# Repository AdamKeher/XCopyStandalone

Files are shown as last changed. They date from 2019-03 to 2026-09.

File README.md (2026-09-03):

# XCopy Standalone
An Arduino / Teensy based version of the Amiga XCopy application for copying floppy disks to and from ADF files. Built for the Teensy 3.2 using a custom PCB and an unmodified PC 3.5" floppy disk drive.

### Note
XCopy Standalone liberally uses floppy interface code taken from the excelent and generously open source ADF-Copy by Dominik Tonn. 
https://nickslabor.niteto.de/download/
Nicks software uses usb serial and a Java client or a MTP connection via usb to transfer data. XCopy Standalone focuses on a standalone unit using SD card storage and a LCD and / or web sockets interface for control.

### Thanks
Special thanks to Giants for all his help with this version including web interface graphics, documentation, suggestions etc.

## Device

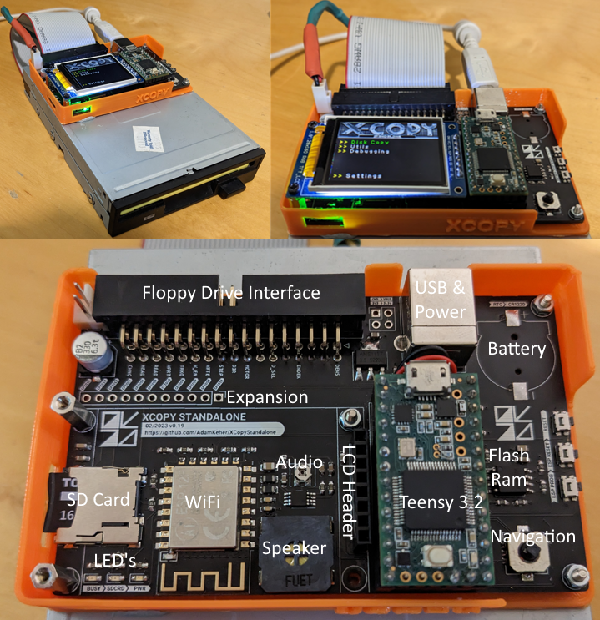
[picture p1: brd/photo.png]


## Status
This project is under heavy development and is in a state of flux with new hardware and software being actively worked on.

## New Features - 04/2023
* v0.19 PCB released with intergrated ESP8266 for WiFi
  * Moved to Kicad from Eagle
  * Changed SD Card to MicroSD reader
  * Added WiFi
  * Connected USB serial to Teensy USB serial
  * Moved TFT to cheap chinese Adafruit knock off, this has changed the pinout
    * https://www.aliexpress.com/item/4001144194129.html
    * USD $1.89!
  * Moved navigation stick to cheap chinese item from LCSC
  * Additional 3.3v power regulator to relieve Teensy's
  * Added larger electrolytic cap for floppy power
  * Switced to four layer board as they are cheap and provide better power / ground planes
* Project code moved from Arduino to ProjectIO with all libraries preinstalled
* New web interface
* Amiga module ripper
* Bootblock library / virus checker using brainfile format
* Web based disk monitor
* Network NTP time update
* Upload and download ADF files via web interface

## Features
* Software
  * ADF Support
    * Amiga file system support for floppy disks and ADF files via ADFlib
  * Disk copy
    * Disk to SD Card
    * SD Card to Disk
    * Disk to Disk
    * Disk to Temporary Flash
    * Temporary Flash to Disk
  * Test disk
  * Format disk
  * Disk flux measurement
  * Serial command line
  * Interfaces
    * TFT LCD
    * USB Serial
    * HTML
  * Serial passthrough for programming onboard ESP8266
* Hardware
  * IDC 34 pin standard floppy drive cable interface
  * 1.8" ST7735R 128x160, 18bit color LCD
  * 5 way navigation joystick
  * Mono PAM8302 amplifier with adjustable Pot
    * Onboard mounted speaker
  * SD Card reader
  * 128MBit Flash Rom with built in ADF files
  * CR1220 battery backed realtime clock
  * ESP8266 for websockets driven interface
  * Single USB plug for serial and to power floppy and Teensy 3.2
  * Status LED's
  * Additional 3.3v power regulator
  * Gerbers, schematic and pcb layout files available 

# PCB

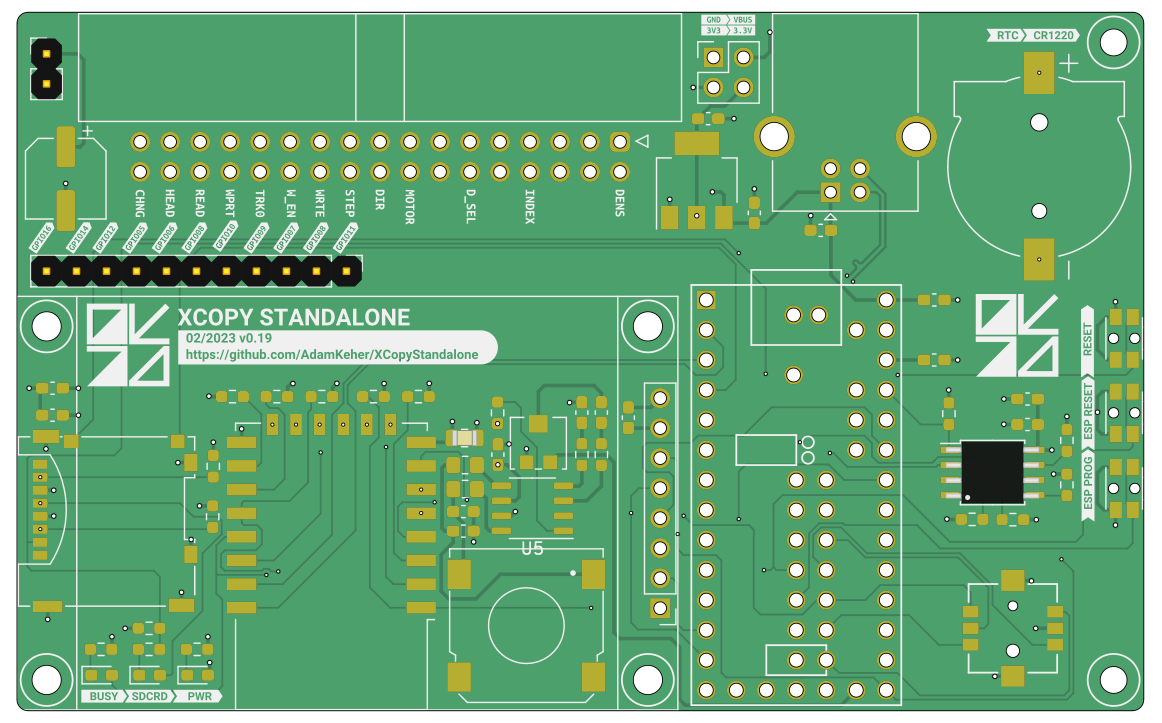
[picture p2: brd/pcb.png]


# Web Interface

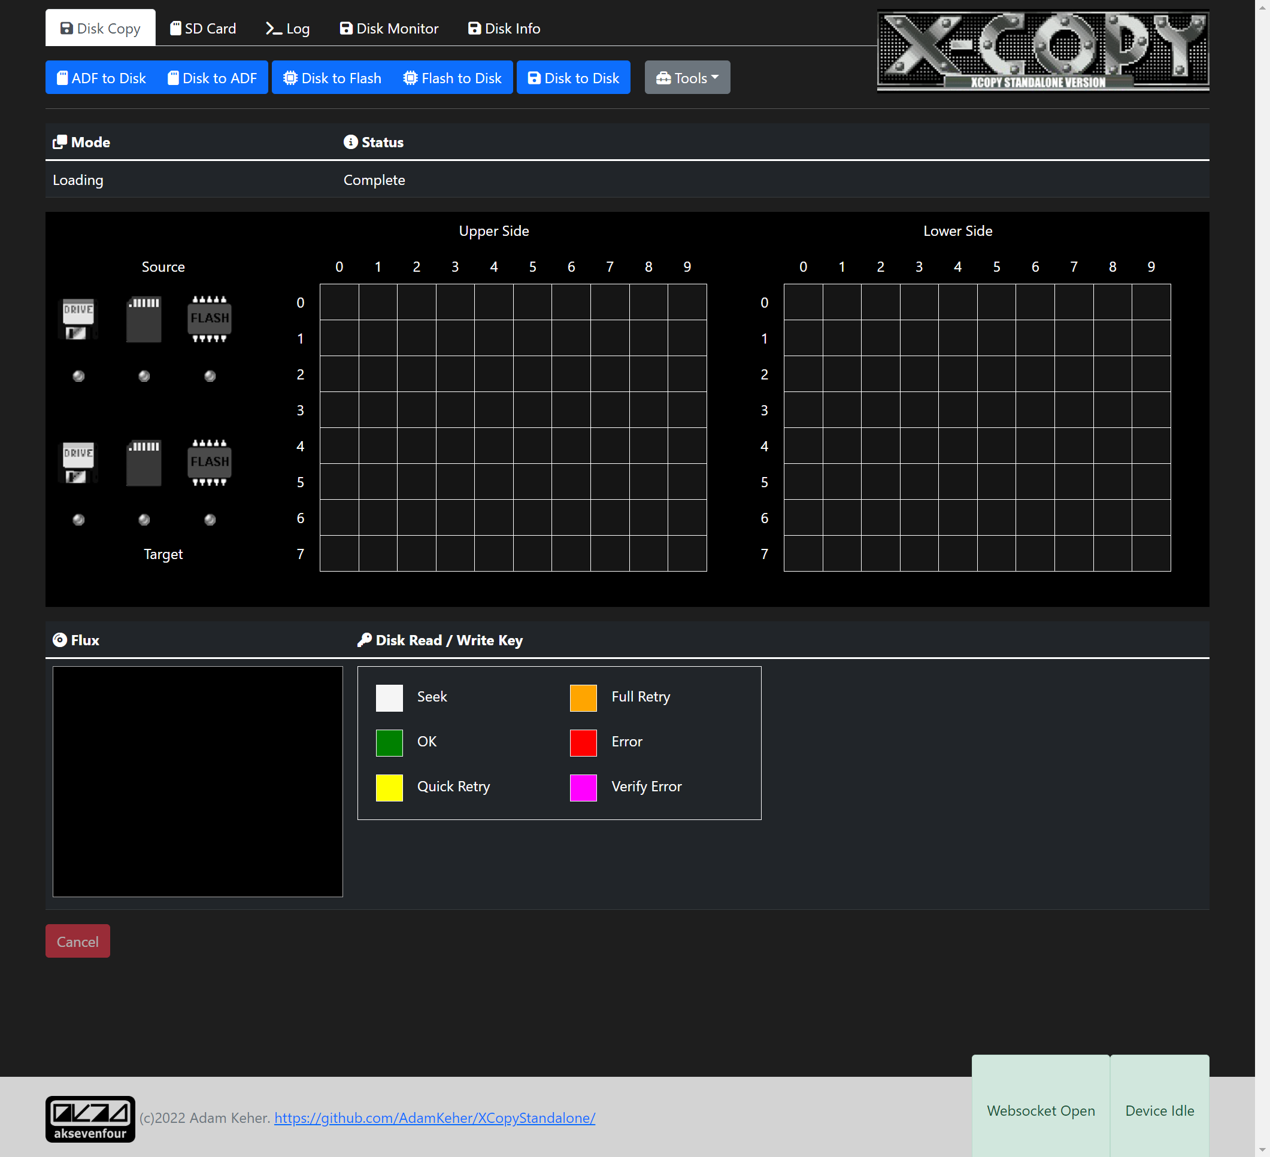
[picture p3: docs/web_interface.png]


# Build Environment Notes:

## VSCode Plugins:
1. PlatoformIO with Teensy & ESP8266 board 
2. Todo+ v4.18.4 by Fabio Spampinato

* Xcopy.h contains PCBVERSION define to target firmware builds to different PCB versions

## ESP8266 Build Notes:
1. Select the `d1_mini` environment (both boards are environments of this one project)
2. Plugin XCopyStandalone device and select "Debugging >> ESP >> ESP Programming Mode"
3. Set serial port to the Teensy port, the device will passthrough serial data to the ESP8266 program
4. Upload code, then upload the web assets with the `d1_mini` "Build Filesystem Image" and "Upload Filesystem Image" tasks

### Over the air

Once the ESP is on your network it can be updated over Wi-Fi instead, using the
`d1_mini_ota` environment - both the firmware and the web assets:

```shell
pio run -e d1_mini_ota -t upload      # firmware
pio run -e d1_mini_ota -t uploadfs    # web interface
pio run -e d1_mini_ota -t uploadall   # both, firmware first
```

`uploadall` is a task of this project rather than of PlatformIO, and it waits
between the two because each upload reboots the ESP.

Use `uploadfs` for the web assets, not `uploadfsota`. The platform decides
whether espota is offering a sketch or a filesystem image by matching the target
name exactly, and `uploadfsota` misses that test - so the image goes over as a
sketch, is measured against the 1MB sketch region instead of its own 2MB
partition, and is refused with `ERROR[4]: Not Enough Space`. `scripts/
espota_fs_flag.py` puts the missing flag back, so both targets now work.

The device calls itself `xcopy` to the DHCP server, to mDNS and to OTA, so it is
reachable by whichever name your network gives it. `upload_port` in
`platformio.ini` is set to `xcopy.lab` - change it to `xcopy.local` to go via
mDNS instead, or to a bare IP address if neither resolves from your machine.

The serial passthrough above is unchanged and remains the way back in if an
update ever leaves the ESP unable to join a network.
5. Select "Debugging >> ESP >> Reset ESP"
6. Open a serial terminal
7. Connect to your wireless access point using the connect command
```shell
>> connect SSIDName Password
```
8. Type the following commands to confirm you have connected
```shell
>> status
WiFi Status: Connected
-----
Mode: STA
PHY mode: N
Channel: 10
AP id: 0
Status: 5
Auto connect: 1
SSID (6): SSIDName
Passphrase (12): Password
BSSID set: 0
>> ip
192.168.X.XX
>> ssid
SSIDName
>>
```

## Project layout

Both firmwares are environments of a single PlatformIO project, so the IDE lists
them in one Project Tasks tree and `pio run` with no arguments builds the pair.

| | |
|---|---|
| `src/` | Teensy 3.2 firmware, built by the `teensy31` environment |
| `src/esp8266/` | ESP8266 firmware, built by the `d1_mini` environment |
| `esp8266/data/` | web interface, uploaded to the ESP as a LittleFS image |
| `shared/` | the Teensy to ESP link contract, compiled into both |
| `lib/` | libraries for both; `esp8266/lib/` holds the ESP only ones |

Both boards are environments of the one project: `teensy31`, `d1_mini`, and
`d1_mini_ota` for updating the ESP over Wi-Fi.

Neither firmware is a `.ino` sketch: PlatformIO only converts a sketch sitting at
the top of the source directory, and with two source trees neither one can be.

## How to build PlatformIO based project

1. [Install PlatformIO Core](http://docs.platformio.org/page/core.html)
2. Download [development platform with examples](https://github.com/platformio/platform-teensy/archive/develop.zip)
3. Open the project
4. Pick the environment you want - `teensy31` or `d1_mini` - or build both at once
5. Select 'PlatformIO:Build'
6. Select 'PlatformIO:Upload'

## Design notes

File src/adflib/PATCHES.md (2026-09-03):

# Vendored ADFlib

Upstream: <https://github.com/lclevy/ADFlib>, tag **v0.10.7** (15 April 2026).
The tree under `src/adflib/` is `src/*.c` and `src/*.h` from that tag, unchanged
except for what is listed below. The platform subdirectories (`generic/`, `linux/`,
`win32/`) are not vendored - their only content is a native block-device driver for
a host OS, and this project supplies its own drivers instead.

Keeping the list this short is the point. Everything else that this firmware needs
ADFlib to do differently is done from outside it, through the driver interface
(`adf_dev_driver.h`) and the log callbacks (`adfEnvSetFct`), which is what the 0.10
API exists for. The previous vendored copy - 0.7.11a, from 2007 - had accumulated
around 560 changed lines because neither of those seams existed yet. Do not start a
second collection: if something here needs changing, look first for the seam.

## Upgrading

1. Take `src/*.c` and `src/*.h` from the new tag.
2. Re-apply the one patch below.
3. Keep `config.h`, this file, and check `build_src_filter` in `platformio.ini` still
   names every file that must not be compiled for the Teensy.
4. `pio test -e native` proves the library still works before any hardware does.

## Additions

### `config.h` - new file

`adf_util.h` includes `config.h` unless `BUILDING_WITH_CMAKE` is defined; upstream
generates it with autotools. Neither build here uses either, so it is written by
hand. Three macros, all naming functions both toolchains provide.

## Patches

### `adf_util.c`, `adf_util.h` - the wall clock

`adfGiveCurrentTime()` upstream calls `time()` and `localtime()`. There is no wall
clock in newlib on a Teensy - the time of day lives in TimeLib, a C++ Arduino
library - and including it here would make the whole of ADFlib depend on the Arduino
core, which would also stop it building for the `native` test environment.

The body now calls `adfHostGiveCurrentTime()`, declared in `adf_util.h` and defined
by the host:

| Environment | Definition | Behaviour |
|---|---|---|
| `teensy31` | `src/XCopy/XCopyAdfHost.cpp` | TimeLib `now()` / `breakTime()` |
| `native` | `test/test_adf/adf_host.c` | a fixed date, so a written image compares byte for byte |

`#include <time.h>` was removed with it. Both edits are marked `XCOPY PATCH` in the
source.

### `adf_dev.h` - `class` is a C++ keyword

`struct AdfDevice` has a member called `class`, so the header cannot be included
from a C++ translation unit - which `adflib.h`, wrapping itself in `extern "C"`,
clearly expects to be. The member is now declared twice behind `#ifdef __cplusplus`:
`devClass` to C++, `class` to C. Same type, same offset, so it is one field with two
spellings and the struct layout is identical in both languages. Library code goes on
saying `dev->class`; this firmware says `dev->devClass`.

Renaming it properly would be a 26-line patch across eight files. Worth reporting
upstream; a one-hunk workaround until then.

### `adf_dev_type.c` - the media table belongs in flash

`adfDevMedia[]` is `static` where it should be `static const`. Every member of it is
already `const` and nothing writes it, but without `const` on the array it lands in
`.data`: 644 bytes copied into RAM at boot and never touched again. That is an
eighth of this board's entire malloc arena. One word.

## Files excluded from the Teensy build

Vendored but filtered out in `platformio.ini`, so the tree stays a clean copy of the
tag while the firmware only pays for what it uses.

| File | Why |
|---|---|
| `adflib.c` | `adfLibInit()` registers the two drivers below and runs `checkInternals()`. `XCopyAdfHost::begin()` does the registration for the drivers that exist on this board, and the internal checks are `static_assert`s in `XCopyAdfHost.cpp`, so they fail at build time rather than at run time. |
| `adf_dev_driver_dump.c` | An ADF-file driver built on stdio `FILE`. `XCopyAdfSdDriver` is the same driver over SdFat. This is the only file in the library that touches stdio. |
| `adf_dev_driver_ramdisk.c` | An 880 KB image in RAM, on a part with 64 KB. |
| `adf_debug.c` | `backtrace()`, which needs glibc. |

All four are compiled in the `native` environment, where they cost nothing and the
dump driver is what the tests read and write images through.

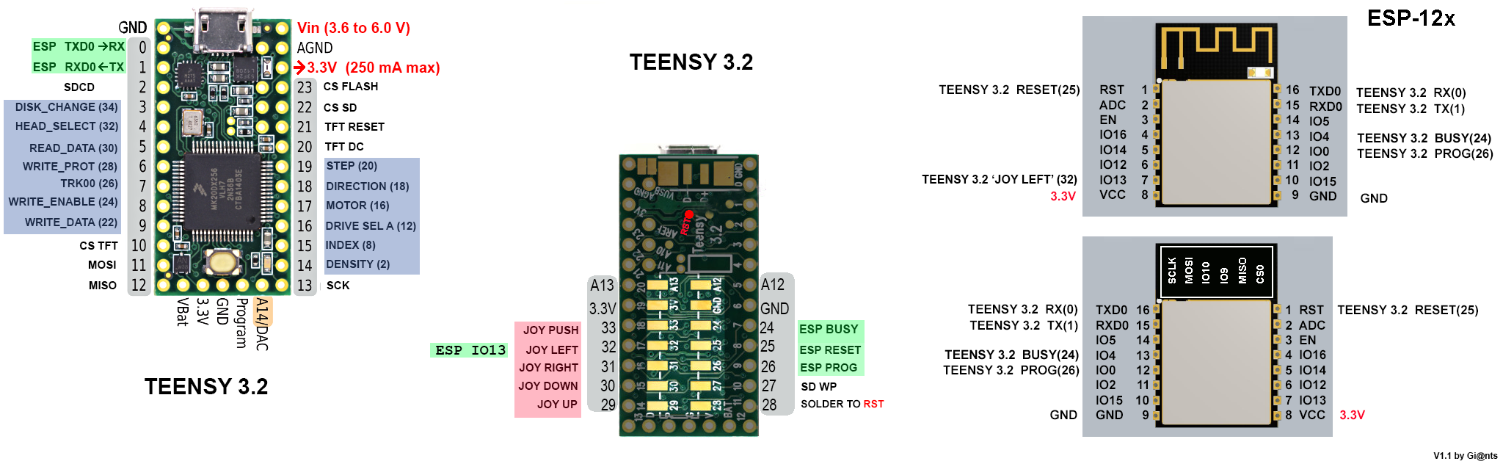
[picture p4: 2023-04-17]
files/Pinout/pinout.png

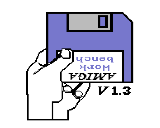
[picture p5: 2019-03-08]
files/Graphics/workbnch.bmp

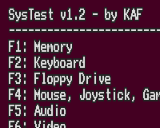
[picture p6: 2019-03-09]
files/Graphics/systest.bmp

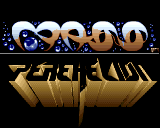
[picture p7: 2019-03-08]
files/Graphics/pere.bmp

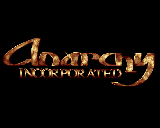
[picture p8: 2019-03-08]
files/Graphics/anarchy.bmp

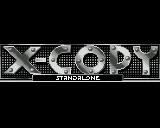
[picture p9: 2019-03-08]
files/Graphics/xcopy.bmp

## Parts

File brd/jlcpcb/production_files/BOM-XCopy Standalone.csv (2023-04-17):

Comment | Designator | Footprint | LCSC | QTY
FerriteBead | FB1,FB2 | R_0805_2012Metric_Pad1.20x1.40mm_HandSolder | C1015 | 2
PAM8302AAD | U5 | SOP-8_3.9x4.9mm_P1.27mm | C112137 | 1
SW_Push | SW2,SW3,SW4 | SW_SKSCLDE010 | C115362 | 3
SW_JOY_SKRHABE010 | SW1 | Switches_ALPS-SKRHAAE010 | C139794 | 1
0.1uF | C11,C9 | C_0603_1608Metric_Pad1.08x0.95mm_HandSolder | C14663 | 2
1uF | C13,C14 | C_0603_1608Metric_Pad1.08x0.95mm_HandSolder | C15849 | 2
220pf | C15,C16 | C_0603_1608Metric_Pad1.08x0.95mm_HandSolder | C1603 | 2
47uF | C3 | C_0805_2012Metric_Pad1.18x1.45mm_HandSolder | C16780 | 1
10uF | C1,C10,C12,C17,C2,C5,C6,C8 | C_0603_1608Metric_Pad1.08x0.95mm_HandSolder | C19702 | 8
1k | R14,R6,R7 | R_0603_1608Metric_Pad0.98x0.95mm_HandSolder | C21190 | 3
100 | R18,R19 | R_0603_1608Metric_Pad0.98x0.95mm_HandSolder | C22775 | 2
10K | R1,R10,R11,R12,R13,R15,R16,R17,R2,R3,R4,R5,R8,R9 | R_0603_1608Metric_Pad0.98x0.95mm_HandSolder | C25804 | 14
503182-1853 | J6 | MOLEX_503182-1853-2 | C266617 | 1
330uF | C4 | CP_Elec_6.3x5.8 | C286137 | 1
AP1117-33 | U3 | SOT-223-3_TabPin2 | C347222 | 1
USB_B | J4 | USB_B_OST_USB_Horizontal-Jing-Extension-111A1010D10200 | C46392 | 1
FS-1340 | LS1 | SPK_FUET_FS-1340 | C482342 | 1
W25Q128JVS | U4 | SOIC-8_5.23x5.23mm_P1.27mm | C571265 | 1
22uF | C7 | C_0603_1608Metric_Pad1.08x0.95mm_HandSolder | C59461 | 1
R_Potentiometer | RV1 | Potentiometer_Bourns_TC33X-2 | C719176 | 1
LED | D3 | LED_0603_1608Metric_Pad1.05x0.95mm_HandSolder | C72038 | 1
LED | D1 | LED_0603_1608Metric_Pad1.05x0.95mm_HandSolder | C72039 | 1
LED | D2 | LED_0603_1608Metric_Pad1.05x0.95mm_HandSolder | C72043 | 1
ESP-12F | U2 | ESP-12E | C82891 | 1
Battery_Cell | BT1 | keystone-PN1056TR | C964750 | 1
ST7735_SPI | U6 | 1.8in_TFT_ST7735 |  | 1
Conn_02x17_Odd_Even | J1 | IDC-Header_2x17_P2.54mm_Horizontal_FLOPPY |  | 1
Conn_01x02 | J3 | PinHeader_1x02_P2.54mm_Vertical |  | 1
ak74:Teensy3.2 | U1 | Teensy30_31_32_All_Pins |  | 1
MountingHole | H1 | MountingHole_2.2mm_M2 |  | 1
Conn_01x07 | J2 | PinHeader_1x11_P2.54mm_Vertical |  | 1
Conn_01x04 | J5 | PinHeader_2x02_P2.54mm_Vertical |  | 1
MountingHole | H2 | MountingHole_2.2mm_M2 |  | 1

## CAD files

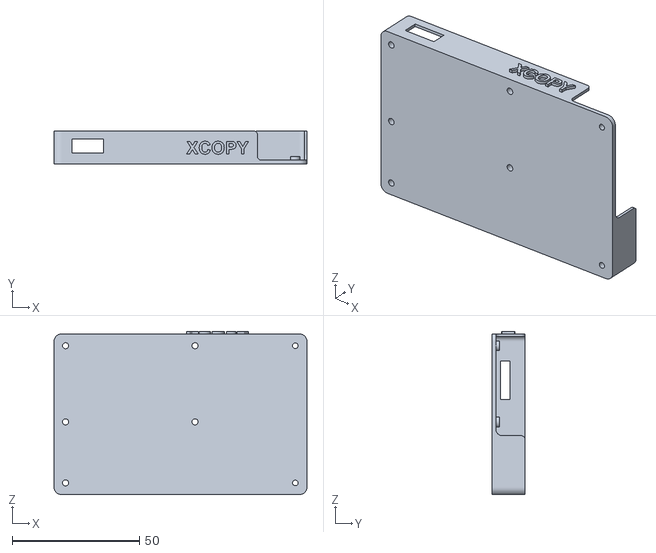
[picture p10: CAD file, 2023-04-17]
brd/case/XCopy Standalone Case v0.19.stl
99.5 x 13.0 x 64.2

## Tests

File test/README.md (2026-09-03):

# Tests

```
pio test -e native      # the console interpreter
pio test -e native_adf  # ADFlib and the directory walk
```

Runs on the host, not on the device. `pio run` is unaffected — it builds the two
firmwares and nothing else, because `default_envs` in `platformio.ini` names them.

## What is here

`test_cli` covers the console interpreter: the command table, the argument parser,
tab completion and the line editor. 28 cases over every shape a command line can
take, every error path, and the corners of the completer and the editor.

It runs against the real sources in `src/XCopy/`, not against copies. That is
possible because those four files depend on nothing but Arduino's `String` — the
terminal and the SD card reach them as function pointers, which is what
`src/XCopy/XCopyConsoleIO.h` exists for. The tests supply a capture buffer for one
and a fixed fake directory tree for the other.

`test_adf` covers ADFlib and `XCopyAdfWalk`, the streaming directory iterator the
console lists through. 14 cases: geometry detection on reopen, OFS and FFS volumes,
a file written and read back byte for byte across a remount, the directory walk
following a hash chain and descending a level, free block accounting across delete
and remount, and the failure paths - a file that is not there, a file that is not an
image, and a write to a read only volume.

It runs against the real vendored library in `src/adflib/`, with upstream's dump
driver standing in for the SD card. That driver is the same `AdfDeviceDriver` vtable
over stdio that `XCopyAdfSdDriver` implements over SdFat, so what is being checked
is the contract both have to satisfy. The one thing the library asks of its host -
the wall clock - is answered in `test_adf/adf_host.c` with a fixed date, so an image
the tests write is reproducible.

It has already earned its place. `adfFreeEntry()` frees the entry struct as well as
the strings inside it, so calling it on a stack entry frees a stack address. That is
an instant crash here and would have been silent heap corruption on the Teensy,
surfacing somewhere else entirely, hours later.

`shim/Arduino.h` is the whole environment the console suite needs: a `String` over `std::string`
with the same surface, including the places Arduino's is unusual and the firmware
relies on it — `substring()` clamps rather than throws, `remove()` truncates,
`charAt()` past the end returns 0.

## What is not here, and cannot be

Anything that needs a floppy drive, an SD card, the TFT or the ESP. That is most of
the firmware, and it is still checked the only way it can be: by building it and
running it on the device. `XCopyAdfSdDriver` and the live floppy driver are in that
group; what stands in for them is the dump driver, which implements the same
interface.

## Adding a suite

One directory per suite under `test/`, named `test_*`, holding a Unity test file
with its own `main()`. If it needs more of the firmware than `String`, the honest
move is usually to give the code under test a seam — as `XCopyConsoleIO.h` did —
rather than to grow the shim until it is a second Arduino.

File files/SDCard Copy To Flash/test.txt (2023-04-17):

ABCDEFGHIJKLMNOPQRSTUVWXYZabcdefghijklmnopqrstuvwxyz0123456789.ABCDEFGHIJKLMNOPQRSTUVWXYZabcdefghijklmnopqrstuvwxyz0123456789.ABCDEFGHIJKLMNOPQRSTUVWXYZabcdefghijklmnopqrstuvwxyz0123456789.ABCDEFGHIJKLMNOPQRSTUVWXYZabcdefghijklmnopqrstuvwxyz0123456789.ABCDEFGHIJKLMNOPQRSTUVWXYZabcdefghijklmnopqrstuvwxyz0123456789.ABCDEFGHIJKLMNOPQRSTUVWXYZabcdefghijklmnopqrstuvwxyz0123456789.ABCDEFGHIJKLMNOPQRSTUVWXYZabcdefghijklmnopqrstuvwxyz0123456789.ABCDEFGHIJKLMNOPQRSTUVWXYZabcdefghijklmnopqrstuvwxyz0123456789.ABCDEFGHIJKLMNOPQRSTUVWXYZabcdefghijklmnopqrstuvwxyz0123456789.ABCDEFGHIJKLMNOPQRSTUVWXYZabcdefghijklmnopqrstuvwxyz0123456789.ABCDEFGHIJKLMNOPQRSTUVWXYZabcdefghijklmnopqrstuvwxyz0123456789.ABCDEFGHIJKLMNOPQRSTUVWXYZabcdefghijklmnopqrstuvwxyz0123456789.ABCDEFGHIJKLMNOPQRSTUVWXYZabcdefghijklmnopqrstuvwxyz0123456789.ABCDEFGHIJKLMNOPQRSTUVWXYZabcdefghijklmnopqrstuvwxyz0123456789.ABCDEFGHIJKLMNOPQRSTUVWXYZabcdefghijklmnopqrstuvwxyz0123456789.ABCDEFGHIJKLMNOPQRSTUVWXYZabcdefghijklmnopqrstuvwxyz0123456789.ABCDEFGHIJKLMNOPQRSTUVWXYZabcdefghijklmnopqrstuvwxyz0123456789.ABCDEFGHIJKLMNOPQRSTUVWXYZabcdefghijklmnopqrstuvwxyz0123456789.ABCDEFGHIJKLMNOPQRSTUVWXYZabcdefghijklmnopqrstuvwxyz0123456789.ABCDEFGHIJKLMNOPQRSTUVWXYZabcdefghijklmnopqrstuvwxyz0123456789.ABCDEFGHIJKLMNOPQRSTUVWXYZabcdefghijklmnopqrstuvwxyz0123456789.ABCDEFGHIJKLMNOPQRSTUVWXYZabcdefghijklmnopqrstuvwxyz0123456789.ABCDEFGHIJKLMNOPQRSTUVWXYZabcdefghijklmnopqrstuvwxyz0123456789.ABCDEFGHIJKLMNOPQRSTUVWXYZabcdefghijklmnopqrstuvwxyz0123456789.ABCDEFGHIJKLMNOPQRSTUVWXYZabcdefghijklmnopqrstuvwxyz0123456789.ABCDEFGHIJKLMNOPQRSTUVWXYZabcdefghijklmnopqrstuvwxyz0123456789.ABCDEFGHIJKLMNOPQRSTUVWXYZabcdefghijklmnopqrstuvwxyz0123456789.ABCDEFGHIJKLMNOPQRSTUVWXYZabcdefghijklmnopqrstuvwxyz0123456789.ABCDEFGHIJKLMNOPQRSTUVWXYZabcdefghijklmnopqrstuvwxyz0123456789.ABCDEFGHIJKLMNOPQRSTUVWXYZabcdefghijklmnopqrstuvwxyz0123456789.ABCDEFGHIJKLMNOPQRSTUVWXYZabcdefghijklmnopqrstuvwxyz0123456789.ABCDEFGHIJKLMNOPQRSTUVWXYZabcdefghijklmnopqrstuvwxyz0123456789.ABCDEFGHIJKLMNOPQRSTUVWXYZabcdefghijklmnopqrstuvwxyz0123456789.ABCDEFGHIJKLMNOPQRSTUVWXYZabcdefghijklmnopqrstuvwxyz0123456789.ABCDEFGHIJKLMNOPQRSTUVWXYZabcdefghijklmnopqrstuvwxyz0123456789.ABCDEFGHIJKLMNOPQRSTUVWXYZabcdefghijklmnopqrstuvwxyz0123456789.ABCDEFGHIJKLMNOPQRSTUVWXYZabcdefghijklmnopqrstuvwxyz0123456789.ABCDEFGHIJKLMNOPQRSTUVWXYZabcdefghijklmnopqrstuvwxyz0123456789.ABCDEFGHIJKLMNOPQRSTUVWXYZabcdefghijklmnopqrstuvwxyz0123456789.ABCDEFGHIJKLMNOPQRSTUVWXYZabcdefghijklmnopqrstuvwxyz0123456789.ABCDEFGHIJKLMNOPQRSTUVWXYZabcdefghijklmnopqrstuvwxyz0123456789.ABCDEFGHIJKLMNOPQRSTUVWXYZabcdefghijklmnopqrstuvwxyz0123456789.ABCDEFGHIJKLMNOPQRSTUVWXYZabcdefghijklmnopqrstuvwxyz0123456789.ABCDEFGHIJKLMNOPQRSTUVWXYZabcdefghijklmnopqrstuvwxyz0123456789.ABCDEFGHIJKLMNOPQRSTUVWXYZabcdefghijklmnopqrstuvwxyz0123456789.ABCDEFGHIJKLMNOPQRSTUVWXYZabcdefghijklmnopqrstuvwxyz0123456789.ABCDEFGHIJKLMNOPQRSTUVWXYZabcdefghijklmnopqrstuvwxyz0123456789.ABCDEFGHIJKLMNOPQRSTUVWXYZabcdefghijklmnopqrstuvwxyz0123456789.ABCDEFGHIJKLMNOPQRSTUVWXYZabcdefghijklmnopqrstuvwxyz0123456789.ABCDEFGHIJKLMNOPQRSTUVWXYZabcdefghijklmnopqrstuvwxyz0123456789.ABCDEFGHIJKLMNOPQRSTUVWXYZabcdefghijklmnopqrstuvwxyz0123456789.ABCDEFGHIJKLMNOPQRSTUVWXYZabcdefghijklmnopqrstuvwxyz0123456789.ABCDEFGHIJKLMNOPQRSTUVWXYZabcdefghijklmnopqrstuvwxyz0123456789.ABCDEFGHIJKLMNOPQRSTUVWXYZabcdefghijklmnopqrstuvwxyz0123456789.ABCDEFGHIJKLMNOPQRSTUVWXYZabcdefghijklmnopqrstuvwxyz0123456789.ABCDEFGHIJKLMNOPQRSTUVWXYZabcdefghijklmnopqrstuvwxyz0123456789.ABCDEFGHIJKLMNOPQRSTUVWXYZabcdefghijklmnopqrstuvwxyz0123456789.ABCDEFGHIJKLMNOPQRSTUVWXYZabcdefghijklmnopqrstuvwxyz0123456789.ABCDEFGHIJKLMNOPQRSTUVWXYZabcdefghijklmnopqrstuvwxyz0123456789.ABCDEFGHIJKLMNOPQRSTUVWXYZabcdefghijklmnopqrstuvwxyz0123456789.ABCDEFGHIJKLMNOPQRSTUVWXYZabcdefghijklmnopqrstuvwxyz0123456789.ABCDEFGHIJKLMNOPQRSTUVWXYZabcdefghijklmnopqrstuvwxyz0123456789.ABCDEFGHIJKLMNOPQRSTUVWXYZabcdefghijklmnopqrstuvwxyz0123456789.ABCDEFGHIJKLMNOPQRSTUVWXYZabcdefghijklmnopqrstuvwxyz0123456789.ABCDEFGHIJKLMNOPQRSTUVWXYZabcdefghijklmnopqrstuvwxyz0123456789.ABCDEFGHIJKLMNOPQRSTUVWXYZabcdefghijklmnopqrstuvwxyz0123456789.ABCDEFGHIJKLMNOPQRSTUVWXYZabcdefghijklmnopqrstuvwxyz0123456789.ABCDEFGHIJKLMNOPQRSTUVWXYZabcdefghijklmnopqrstuvwxyz0123456789.ABCDEFGHIJKLMNOPQRSTUVWXYZabcdefghijklmnopqrstuvwxyz0123456789.ABCDEFGHIJKLMNOPQRSTUVWXYZabcdefghijklmnopqrstuvwxyz0123456789.ABCDEFGHIJKLMNOPQRSTUVWXYZabcdefghijklmnopqrstuvwxyz0123456789.ABCDEFGHIJKLMNOPQRSTUVWXYZabcdefghijklmnopqrstuvwxyz0123456789.ABCDEFGHIJKLMNOPQRSTUVWXYZabcdefghijklmnopqrstuvwxyz0123456789.ABCDEFGHIJKLMNOPQRSTUVWXYZabcdefghijklmnopqrstuvwxyz0123456789.ABCDEFGHIJKLMNOPQRSTUVWXYZabcdefghijklmnopqrstuvwxyz0123456789.ABCDEFGHIJKLMNOPQRSTUVWXYZabcdefghijklmnopqrstuvwxyz0123456789.ABCDEFGHIJKLMNOPQRSTUVWXYZabcdefghijklmnopqrstuvwxyz0123456789.ABCDEFGHIJKLMNOPQRSTUVWXYZabcdefghijklmnopqrstuvwxyz0123456789.ABCDEFGHIJKLMNOPQRSTUVWXYZabcdefghijklmnopqrstuvwxyz0123456789.ABCDEFGHIJKLMNOPQRSTUVWXYZabcdefghijklmnopqrstuvwxyz0123456789.ABCDEFGHIJKLMNOPQRSTUVWXYZabcdefghijklmnopqrstuvwxyz0123456789.ABCDEFGHIJKLMNOPQRSTUVWXYZabcdefghijklmnopqrstuvwxyz0123456789.ABCDEFGHIJKLMNOPQRSTUVWXYZabcdefghijklmnopqrstuvwxyz0123456789.ABCDEFGHIJKLMNOPQRSTUVWXYZabcdefghijklmnopqrstuvwxyz0123456789.ABCDEFGHIJKLMNOPQRSTUVWXYZabcdefghijklmnopqrstuvwxyz0123456789.ABCDEFGHIJKLMNOPQRSTUVWXYZabcdefghijklmnopqrstuvwxyz0123456789.ABCDEFGHIJKLMNOPQRSTUVWXYZabcdefghijklmnopqrstuvwxyz0123456789.ABCDEFGHIJKLMNOPQRSTUVWXYZabcdefghijklmnopqrstuvwxyz0123456789.ABCDEFGHIJKLMNOPQRSTUVWXYZabcdefghijklmnopqrstuvwxyz0123456789.ABCDEFGHIJKLMNOPQRSTUVWXYZabcdefghijklmnopqrstuvwxyz0123456789.ABCDEFGHIJKLMNOPQRSTUVWXYZabcdefghijklmnopqrstuvwxyz0123456789.ABCDEFGHIJKLMNOPQRSTUVWXYZabcdefghijklmnopqrstuvwxyz0123456789.ABCDEFGHIJKLMNOPQRSTUVWXYZabcdefghijklmnopqrstuvwxyz0123456789.ABCDEFGHIJKLMNOPQRSTUVWXYZabcdefghijklmnopqrstuvwxyz0123456789.ABCDEFGHIJKLMNOPQRSTUVWXYZabcdefghijklmnopqrstuvwxyz0123456789.ABCDEFGHIJKLMNOPQRSTUVWXYZabcdefghijklmnopqrstuvwxyz0123456789.ABCDEFGHIJKLMNOPQRSTUVWXYZabcdefghijklmnopqrstuvwxyz0123456789.ABCDEFGHIJKLMNOPQRSTUVWXYZabcdefghijklmnopqrstuvwxyz0123456789.ABCDEFGHIJKLMNOPQRSTUVWXYZabcdefghijklmnopqrstuvwxyz0123456789.ABCDEFGHIJKLMNOPQRSTUVWXYZabcdefghijklmnopqrstuvwxyz0123456789.ABCDEFGHIJKLMNOPQRSTUVWXYZabcdefghijklmnopqrstuvwxyz0123456789.ABCDEFGHIJKLMNOPQRSTUVWXYZabcdefghijklmnopqrstuvwxyz0123456789.ABCDEFGHIJKLMNOPQRSTUVWXYZabcdefghijklmnopqrstuvwxyz0123456789.ABCDEFGHIJKLMNOPQRSTUVWXYZabcdefghijklmnopqrstuvwxyz0123456789.ABCDEFGHIJKLMNOPQRSTUVWXYZabcdefghijklmnopqrstuvwxyz0123456789.ABCDEFGHIJKLMNOPQRSTUVWXYZabcdefghijklmnopqrstuvwxyz0123456789.ABCDEFGHIJKLMNOPQRSTUVWXYZabcdefghijklmnopqrstuvwxyz0123456789.ABCDEFGHIJKLMNOPQRSTUVWXYZabcdefghijklmnopqrstuvwxyz0123456789.ABCDEFGHIJKLMNOPQRSTUVWXYZabcdefghijklmnopqrstuvwxyz0123456789.ABCDEFGHIJKLMNOPQRSTUVWXYZabcdefghijklmnopqrstuvwxyz0123456789.ABCDEFGHIJKLMNOPQRSTUVWXYZabcdefghijklmnopqrstuvwxyz0123456789.ABCDEFGHIJKLMNOPQRSTUVWXYZabcdefghijklmnopqrstuvwxyz0123456789.ABCDEFGHIJKLMNOPQRSTUVWXYZabcdefghijklmnopqrstuvwxyz0123456789.ABCDEFGHIJKLMNOPQRSTUVWXYZabcdefghijklmnopqrstuvwxyz0123456789.ABCDEFGHIJKLMNOPQRSTUVWXYZabcdefghijklmnopqrstuvwxyz0123456789.ABCDEFGHIJKLMNOPQRSTUVWXYZabcdefghijklmnopqrstuvwxyz0123456789.ABCDEFGHIJKLMNOPQRSTUVWXYZabcdefghijklmnopqrstuvwxyz0123456789.ABCDEFGHIJKLMNOPQRSTUVWXYZabcdefghijklmnopqrstuvwxyz0123456789.ABCDEFGHIJKLMNOPQRSTUVWXYZabcdefghijklmnopqrstuvwxyz0123456789.ABCDEFGHIJKLMNOPQRSTUVWXYZabcdefghijklmnopqrstuvwxyz0123456789.ABCDEFGHIJKLMNOPQRSTUVWXYZabcdefghijklmnopqrstuvwxyz0123456789.ABCDEFGHIJKLMNOPQRSTUVWXYZabcdefghijklmnopqrstuvwxyz0123456789.ABCDEFGHIJKLMNOPQRSTUVWXYZabcdefghijklmnopqrstuvwxyz0123456789.ABCDEFGHIJKLMNOPQRSTUVWXYZabcdefghijklmnopqrstuvwxyz0123456789.ABCDEFGHIJKLMNOPQRSTUVWXYZabcdefghijklmnopqrstuvwxyz0123456789.ABCDEFGHIJKLMNOPQRSTUVWXYZabcdefghijklmnopqrstuvwxyz0123456789.ABCDEFGHIJKLMNOPQRSTUVWXYZabcdefghijklmnopqrstuvwxyz0123456789.ABCDEFGHIJKLMNOPQRSTUVWXYZabcdefghijklmnopqrstuvwxyz0123456789.ABCDEFGHIJKLMNOPQRSTUVWXYZabcdefghijklmnopqrstuvwxyz0123456789.ABCDEFGHIJKLMNOPQRSTUVWXYZabcdefghijklmnopqrstuvwxyz0123456789.ABCDEFGHIJKLMNOPQRSTUVWXYZabcdefghijklmnopqrstuvwxyz0123456789.ABCDEFGHIJKLMNOPQRSTUVWXYZabcdefghijklmnopqrstuvwxyz0123456789.ABCDEFGHIJKLMNOPQRSTUVWXYZabcdefghijklmnopqrstuvwxyz0123456789.ABCDEFGHIJKLMNOPQRSTUVWXYZabcdefghijklmnopqrstuvwxyz0123456789.ABCDEFGHIJKLMNOPQRSTUVWXYZabcdefghijklmnopqrstuvwxyz0123456789.ABCDEFGHIJKLMNOPQRSTUVWXYZabcdefghijklmnopqrstuvwxyz0123456789.ABCDEFGHIJKLMNOPQRSTUVWXYZabcdefghijklmnopqrstuvwxyz0123456789.ABCDEFGHIJKLMNOPQRSTUVWXYZabcdefghijklmnopqrstuvwxyz0123456789.ABCDEFGHIJKLMNOPQRSTUVWXYZabcdefghijklmnopqrstuvwxyz0123456789.ABCDEFGHIJKLMNOPQRSTUVWXYZabcdefghijklmnopqrstuvwxyz0123456789.ABCDEFGHIJKLMNOPQRSTUVWXYZabcdefghijklmnopqrstuvwxyz0123456789.ABCDEFGHIJKLMNOPQRSTUVWXYZabcdefghijklmnopqrstuvwxyz0123456789.ABCDEFGHIJKLMNOPQRSTUVWXYZabcdefghijklmnopqrstuvwxyz0123456789.ABCDEFGHIJKLMNOPQRSTUVWXYZabcdefghijklmnopqrstuvwxyz0123456789.ABCDEFGHIJKLMNOPQRSTUVWXYZabcdefghijklmnopqrstuvwxyz0123456789.ABCDEFGHIJKLMNOPQRSTUVWXYZabcdefghijklmnopqrstuvwxyz0123456789.ABCDEFGHIJKLMNOPQRSTUVWXYZabcdefghijklmnopqrstuvwxyz0123456789.ABCDEFGHIJKLMNOPQRSTUVWXYZabcdefghijklmnopqrstuvwxyz0123456789.ABCDEFGHIJKLMNOPQRSTUVWXYZabcdefghijklmnopqrstuvwxyz0123456789.ABCDEFGHIJKLMNOPQRSTUVWXYZabcdefghijklmnopqrstuvwxyz0123456789.ABCDEFGHIJKLMNOPQRSTUVWXYZabcdefghijklmnopqrstuvwxyz0123456789.ABCDEFGHIJKLMNOPQRSTUVWXYZabcdefghijklmnopqrstuvwxyz0123456789.ABCDEFGHIJKLMNOPQRSTUVWXYZabcdefghijklmnopqrstuvwxyz0123456789.ABCDEFGHIJKLMNOPQRSTUVWXYZabcdefghijklmnopqrstuvwxyz0123456789.ABCDEFGHIJKLMNOPQRSTUVWXYZabcdefghijklmnopqrstuvwxyz0123456789.ABCDEFGHIJKLMNOPQRSTUVWXYZabcdefghijklmnopqrstuvwxyz0123456789.ABCDEFGHIJKLMNOPQRSTUVWXYZabcdefghijklmnopqrstuvwxyz0123456789.ABCDEFGHIJKLMNOPQRSTUVWXYZabcdefghijklmnopqrstuvwxyz0123456789.ABCDEFGHIJKLMNOPQRSTUVWXYZabcdefghijklmnopqrstuvwxyz0123456789.ABCDEFGHIJKLMNOPQRSTUVWXYZabcdefghijklmnopqrstuvwxyz0123456789.ABCDEFGHIJKLMNOPQRSTUVWXYZabcdefghijklmnopqrstuvwxyz0123456789.ABCDEFGHIJKLMNOPQRSTUVWXYZabcdefghijklmnopqrstuvwxyz0123456789.ABCDEFGHIJKLMNOPQRSTUVWXYZabcdefghijklmnopqrstuvwxyz0123456789.ABCDEFGHIJKLMNOPQRSTUVWXYZabcdefghijklmnopqrstuvwxyz0123456789.ABCDEFGHIJKLMNOPQRSTUVWXYZabcdefghijklmnopqrstuvwxyz0123456789.ABCDEFGHIJKLMNOPQRSTUVWXYZabcdefghijklmnopqrstuvwxyz0123456789.ABCDEFGHIJKLMNOPQRSTUVWXYZabcdefghijklmnopqrstuvwxyz0123456789.ABCDEFGHIJKLMNOPQRSTUVWXYZabcdefghijklmnopqrstuvwxyz0123456789.ABCDEFGHIJKLMNOPQRSTUVWXYZabcdefghijklmnopqrstuvwxyz0123456789.ABCDEFGHIJKLMNOPQRSTUVWXYZabcdefghijklmnopqrstuvwxyz0123456789.ABCDEFGHIJKLMNOPQRSTUVWXYZabcdefghijklmnopqrstuvwxyz0123456789.ABCDEFGHIJKLMNOPQRSTUVWXYZabcdefghijklmnopqrstuvwxyz0123456789.ABCDEFGHIJKLMNOPQRSTUVWXYZabcdefghijklmnopqrstuvwxyz0123456789.ABCDEFGHIJKLMNOPQRSTUVWXYZabcdefghijklmnopqrstuvwxyz0123456789.ABCDEFGHIJKLMNOPQRSTUVWXYZabcdefghijklmnopqrstuvwxyz0123456789.ABCDEFGHIJKLMNOPQRSTUVWXYZabcdefghijklmnopqrstuvwxyz0123456789.ABCDEFGHIJKLMNOPQRSTUVWXYZabcdefghijklmnopqrstuvwxyz0123456789.ABCDEFGHIJKLMNOPQRSTUVWXYZabcdefghijklmnopqrstuvwxyz0123456789.ABCDEFGHIJKLMNOPQRSTUVWXYZabcdefghijklmnopqrstuvwxyz0123456789.ABCDEFGHIJKLMNOPQRSTUVWXYZabcdefghijklmnopqrstuvwxyz0123456789.ABCDEFGHIJKLMNOPQRSTUVWXYZabcdefghijklmnopqrstuvwxyz0123456789.ABCDEFGHIJKLMNOPQRSTUVWXYZabcdefghijklmnopqrstuvwxyz0123456789.ABCDEFGHIJKLMNOPQRSTUVWXYZabcdefghijklmnopqrstuvwxyz0123456789.ABCDEFGHIJKLMNOPQRSTUVWXYZabcdefghijklmnopqrstuvwxyz0123456789.ABCDEFGHIJKLMNOPQRSTUVWXYZabcdefghijklmnopqrstuvwxyz0123456789.ABCDEFGHIJKLMNOPQRSTUVWXYZabcdefghijklmnopqrstuvwxyz0123456789.ABCDEFGHIJKLMNOPQRSTUVWXYZabcdefghijklmnopqrstuvwxyz0123456789.ABCDEFGHIJKLMNOPQRSTUVWXYZabcdefghijklmnopqrstuvwxyz0123456789.ABCDEFGHIJKLMNOPQRSTUVWXYZabcdefghijklmnopqrstuvwxyz0123456789.ABCDEFGHIJKLMNOPQRSTUVWXYZabcdefghijklmnopqrstuvwxyz0123456789.ABCDEFGHIJKLMNOPQRSTUVWXYZabcdefghijklmnopqrstuvwxyz0123456789.ABCDEFGHIJKLMNOPQRSTUVWXYZabcdefghijklmnopqrstuvwxyz0123456789.ABCDEFGHIJKLMNOPQRSTUVWXYZabcdefghijklmnopqrstuvwxyz0123456789.ABCDEFGHIJKLMNOPQRSTUVWXYZabcdefghijklmnopqrstuvwxyz0123456789.ABCDEFGHIJKLMNOPQRSTUVWXYZabcdefghijklmnopqrstuvwxyz0123456789.ABCDEFGHIJKLMNOPQRSTUVWXYZabcdefghijklmnopqrstuvwxyz0123456789.ABCDEFGHIJKLMNOPQRSTUVWXYZabcdefghijklmnopqrstuvwxyz0123456789.ABCDEFGHIJKLMNOPQRSTUVWXYZabcdefghijklmnopqrstuvwxyz0123456789.ABCDEFGHIJKLMNOPQRSTUVWXYZabcdefghijklmnopqrstuvwxyz0123456789.ABCDEFGHIJKLMNOPQRSTUVWXYZabcdefghijklmnopqrstuvwxyz0123456789.ABCDEFGHIJKLMNOPQRSTUVWXYZabcdefghijklmnopqrstuvwxyz0123456789.ABCDEFGHIJKLMNOPQRSTUVWXYZabcdefghijklmnopqrstuvwxyz0123456789.ABCDEFGHIJKLMNOPQRSTUVWXYZabcdefghijklmnopqrstuvwxyz0123456789.ABCDEFGHIJKLMNOPQRSTUVWXYZabcdefghijklmnopqrstuvwxyz0123456789.ABCDEFGHIJKLMNOPQRSTUVWXYZabcdefghijklmnopqrstuvwxyz0123456789.ABCDEFGHIJKLMNOPQRSTUVWXYZabcdefghijklmnopqrstuvwxyz0123456789.ABCDEFGHIJKLMNOPQRSTUVWXYZabcdefghijklmnopqrstuvwxyz0123456789.ABCDEFGHIJKLMNOPQRSTUVWXYZabcdefghijklmnopqrstuvwxyz0123456789.ABCDEFGHIJKLMNOPQRSTUVWXYZabcdefghijklmnopqrstuvwxyz0123456789.ABCDEFGHIJKLMNOPQRSTUVWXYZabcdefghijklmnopqrstuvwxyz0123456789.ABCDEFGHIJKLMNOPQRSTUVWXYZabcdefghijklmnopqrstuvwxyz0123456789.ABCDEFGHIJKLMNOPQRSTUVWXYZabcdefghijklmnopqrstuvwxyz0123456789.ABCDEFGHIJKLMNOPQRSTUVWXYZabcdefghijklmnopqrstuvwxyz0123456789.ABCDEFGHIJKLMNOPQRSTUVWXYZabcdefghijklmnopqrstuvwxyz0123456789.ABCDEFGHIJKLMNOPQRSTUVWXYZabcdefghijklmnopqrstuvwxyz0123456789.ABCDEFGHIJKLMNOPQRSTUVWXYZabcdefghijklmnopqrstuvwxyz0123456789.ABCDEFGHIJKLMNOPQRSTUVWXYZabcdefghijklmnopqrstuvwxyz0123456789.ABCDEFGHIJKLMNOPQRSTUVWXYZabcdefghijklmnopqrstuvwxyz0123456789.ABCDEFGHIJKLMNOPQRSTUVWXYZabcdefghijklmnopqrstuvwxyz0123456789.ABCDEFGHIJKLMNOPQRSTUVWXYZabcdefghijklmnopqrstuvwxyz0123456789.ABCDEFGHIJKLMNOPQRSTUVWXYZabcdefghijklmnopqrstuvwxyz0123456789.ABCDEFGHIJKLMNOPQRSTUVWXYZabcdefghijklmnopqrstuvwxyz0123456789.ABCDEFGHIJKLMNOPQRSTUVWXYZabcdefghijklmnopqrstuvwxyz0123456789.ABCDEFGHIJKLMNOPQRSTUVWXYZabcdefghijklmnopqrstuvwxyz0123456789.ABCDEFGHIJKLMNOPQRSTUVWXYZabcdefghijklmnopqrstuvwxyz0123456789.ABCDEFGHIJKLMNOPQRSTUVWXYZabcdefghijklmnopqrstuvwxyz0123456789.ABCDEFGHIJKLMNOPQRSTUVWXYZabcdefghijklmnopqrstuvwxyz0123456789.ABCDEFGHIJKLMNOPQRSTUVWXYZabcdefghijklmnopqrstuvwxyz0123456789.ABCDEFGHIJKLMNOPQRSTUVWXYZabcdefghijklmnopqrstuvwxyz0123456789.ABCDEFGHIJKLMNOPQRSTUVWXYZabcdefghijklmnopqrstuvwxyz0123456789.ABCDEFGHIJKLMNOPQRSTUVWXYZabcdefghijklmnopqrstuvwxyz0123456789.ABCDEFGHIJKLMNOPQRSTUVWXYZabcdefghijklmnopqrstuvwxyz0123456789.ABCDEFGHIJKLMNOPQRSTUVWXYZabcdefghijklmnopqrstuvwxyz0123456789.ABCDEFGHIJKLMNOPQRSTUVWXYZabcdefghijklmnopqrstuvwxyz0123456789.ABCDEFGHIJKLMNOPQRSTUVWXYZabcdefghijklmnopqrstuvwxyz0123456789.ABCDEFGHIJKLMNOPQRSTUVWXYZabcdefghijklmnopqrstuvwxyz0123456789.ABCDEFGHIJKLMNOPQRSTUVWXYZabcdefghijklmnopqrstuvwxyz0123456789.ABCDEFGHIJKLMNOPQRSTUVWXYZabcdefghijklmnopqrstuvwxyz0123456789.ABCDEFGHIJKLMNOPQRSTUVWXYZabcdefghijklmnopqrstuvwxyz0123456789.ABCDEFGHIJKLMNOPQRSTUVWXYZabcdefghijklmnopqrstuvwxyz0123456789.ABCDEFGHIJKLMNOPQRSTUVWXYZabcdefghijklmnopqrstuvwxyz0123456789.ABCDEFGHIJKLMNOPQRSTUVWXYZabcdefghijklmnopqrstuvwxyz0123456789.ABCDEFGHIJKLMNOPQRSTUVWXYZabcdefghijklmnopqrstuvwxyz0123456789.ABCDEFGHIJKLMNOPQRSTUVWXYZabcdefghijklmnopqrstuvwxyz0123456789.ABCDEFGHIJKLMNOPQRSTUVWXYZabcdefghijklmnopqrstuvwxyz0123456789.ABCDEFGHIJKLMNOPQRSTUVWXYZabcdefghijklmnopqrstuvwxyz0123456789.ABCDEFGHIJKLMNOPQRSTUVWXYZabcdefghijklmnopqrstuvwxyz0123456789.ABCDEFGHIJKLMNOPQRSTUVWXYZabcdefghijklmnopqrstuvwxyz0123456789.ABCDEFGHIJKLMNOPQRSTUVWXYZabcdefghijklmnopqrstuvwxyz0123456789.ABCDEFGHIJKLMNOPQRSTUVWXYZabcdefghijklmnopqrstuvwxyz0123456789.ABCDEFGHIJKLMNOPQRSTUVWXYZabcdefghijklmnopqrstuvwxyz0123456789.ABCDEFGHIJKLMNOPQRSTUVWXYZabcdefghijklmnopqrstuvwxyz0123456789.ABCDEFGHIJKLMNOPQRSTUVWXYZabcdefghijklmnopqrstuvwxyz0123456789.ABCDEFGHIJKLMNOPQRSTUVWXYZabcdefghijklmnopqrstuvwxyz0123456789.ABCDEFGHIJKLMNOPQRSTUVWXYZabcdefghijklmnopqrstuvwxyz0123456789.ABCDEFGHIJKLMNOPQRSTUVWXYZabcdefghijklmnopqrstuvwxyz0123456789.ABCDEFGHIJKLMNOPQRSTUVWXYZabcdefghijklmnopqrstuvwxyz0123456789.ABCDEFGHIJKLMNOPQRSTUVWXYZabcdefghijklmnopqrstuvwxyz0123456789.ABCDEFGHIJKLMNOPQRSTUVWXYZabcdefghijklmnopqrstuvwxyz0123456789.ABCDEFGHIJKLMNOPQRSTUVWXYZabcdefghijklmnopqrstuvwxyz0123456789.ABCDEFGHIJKLMNOPQRSTUVWXYZabcdefghijklmnopqrstuvwxyz0123456789.ABCDEFGHIJKLMNOPQRSTUVWXYZabcdefghijklmnopqrstuvwxyz0123456789.ABCDEFGHIJKLMNOPQRSTUVWXYZabcdefghijklmnopqrstuvwxyz0123456789.ABCDEFGHIJKLMNOPQRSTUVWXYZabcdefghijklmnopqrstuvwxyz0123456789.ABCDEFGHIJKLMNOPQRSTUVWXYZabcdefghijklmnopqrstuvwxyz0123456789.ABCDEFGHIJKLMNOPQRSTUVWXYZabcdefghijklmnopqrstuvwxyz0123456789.ABCDEFGHIJKLMNOPQRSTUVWXYZabcdefghijklmnopqrstuvwxyz0123456789.ABCDEFGHIJKLMNOPQRSTUVWXYZabcdefghijklmnopqrstuvwxyz0123456789.ABCDEFGHIJKLMNOPQRSTUVWXYZabcdefghijklmnopqrstuvwxyz0123456789.ABCDEFGHIJKLMNOPQRSTUVWXYZabcdefghijklmnopqrstuvwxyz0123456789.ABCDEFGHIJKLMNOPQRSTUVWXYZabcdefghijklmnopqrstuvwxyz0123456789.ABCDEFGHIJKLMNOPQRSTUVWXYZabcdefghijklmnopqrstuvwxyz0123456789.ABCDEFGHIJKLMNOPQRSTUVWXYZabcdefghijklmnopqrstuvwxyz0123456789.ABCDEFGHIJKLMNOPQRSTUVWXYZabcdefghijklmnopqrstuvwxyz0123456789.ABCDEFGHIJKLMNOPQRSTUVWXYZabcdefghijklmnopqrstuvwxyz0123456789.ABCDEFGHIJKLMNOPQRSTUVWXYZabcdefghijklmnopqrstuvwxyz0123456789.ABCDEFGHIJKLMNOPQRSTUVWXYZabcdefghijklmnopqrstuvwxyz0123456789.ABCDEFGHIJKLMNOPQRSTUVWXYZabcdefghijklmnopqrstuvwxyz0123456789.ABCDEFGHIJKLMNOPQRSTUVWXYZabcdefghijklmnopqrstuvwxyz0123456789.ABCDEFGHIJKLMNOPQRSTUVWXYZabcdefghijklmnopqrstuvwxyz0123456789.ABCDEFGHIJKLMNOPQRSTUVWXYZabcdefghijklmnopqrstuvwxyz0123456789.ABCDEFGHIJKLMNOPQRSTUVWXYZabcdefghijklmnopqrstuvwxyz0123456789.ABCDEFGHIJKLMNOPQRSTUVWXYZabcdefghijklmnopqrstuvwxyz0123456789.ABCDEFGHIJKLMNOPQRSTUVWXYZabcdefghijklmnopqrstuvwxyz0123456789.ABCDEFGHIJKLMNOPQRSTUVWXYZabcdefghijklmnopqrstuvwxyz0123456789.ABCDEFGHIJKLMNOPQRSTUVWXYZabcdefghijklmnopqrstuvwxyz0123456789.ABCDEFGHIJKLMNOPQRSTUVWXYZabcdefghijklmnopqrstuvwxyz0123456789.ABCDEFGHIJKLMNOPQRSTUVWXYZabcdefghijklmnopqrstuvwxyz0123456789.ABCDEFGHIJKLMNOPQRSTUVWXYZabcdefghijklmnopqrstuvwxyz0123456789.ABCDEFGHIJKLMNOPQRSTUVWXYZabcdefghijklmnopqrstuvwxyz0123456789.ABCDEFGHIJKLMNOPQRSTUVWXYZabcdefghijklmnopqrstuvwxyz0123456789.ABCDEFGHIJKLMNOPQRSTUVWXYZabcdefghijklmnopqrstuvwxyz0123456789.ABCDEFGHIJKLMNOPQRSTUVWXYZabcdefghijklmnopqrstuvwxyz0123456789.ABCDEFGHIJKLMNOPQRSTUVWXYZabcdefghijklmnopqrstuvwxyz0123456789.ABCDEFGHIJKLMNOPQRSTUVWXYZabcdefghijklmnopqrstuvwxyz0123456789.ABCDEFGHIJKLMNOPQRSTUVWXYZabcdefghijklmnopqrstuvwxyz0123456789.ABCDEFGHIJKLMNOPQRSTUVWXYZabcdefghijklmnopqrstuvwxyz0123456789.ABCDEFGHIJKLMNOPQRSTUVWXYZabcdefghijklmnopqrstuvwxyz0123456789.ABCDEFGHIJKLMNOPQRSTUVWXYZabcdefghijklmnopqrstuvwxyz0123456789.ABCDEFGHIJKLMNOPQRSTUVWXYZabcdefghijklmnopqrstuvwxyz0123456789.ABCDEFGHIJKLMNOPQRSTUVWXYZabcdefghijklmnopqrstuvwxyz0123456789.ABCDEFGHIJKLMNOPQRSTUVWXYZabcdefghijklmnopqrstuvwxyz0123456789.ABCDEFGHIJKLMNOPQRSTUVWXYZabcdefghijklmnopqrstuvwxyz0123456789.ABCDEFGHIJKLMNOPQRSTUVWXYZabcdefghijklmnopqrstuvwxyz0123456789.ABCDEFGHIJKLMNOPQRSTUVWXYZabcdefghijklmnopqrstuvwxyz0123456789.ABCDEFGHIJKLMNOPQRSTUVWXYZabcdefghijklmnopqrstuvwxyz0123456789.ABCDEFGHIJKLMNOPQRSTUVWXYZabcdefghijklmnopqrstuvwxyz0123456789.ABCDEFGHIJKLMNOPQRSTUVWXYZabcdefghijklmnopqrstuvwxyz0123456789.ABCDEFGHIJKLMNOPQRSTUVWXYZabcdefghijklmnopqrstuvwxyz0123456789.ABCDEFGHIJKLMNOPQRSTUVWXYZabcdefghijklmnopqrstuvwxyz0123456789.ABCDEFGHIJKLMNOPQRSTUVWXYZabcdefghijklmnopqrstuvwxyz0123456789.ABCDEFGHIJKLMNOPQRSTUVWXYZabcdefghijklmnopqrstuvwxyz0123456789.ABCDEFGHIJKLMNOPQRSTUVWXYZabcdefghijklmnopqrstuvwxyz0123456789.ABCDEFGHIJKLMNOPQRSTUVWXYZabcdefghijklmnopqrstuvwxyz0123456789.ABCDEFGHIJKLMNOPQRSTUVWXYZabcdefghijklmnopqrstuvwxyz0123456789.ABCDEFGHIJKLMNOPQRSTUVWXYZabcdefghijklmnopqrstuvwxyz0123456789.ABCDEFGHIJKLMNOPQRSTUVWXYZabcdefghijklmnopqrstuvwxyz0123456789.ABCDEFGHIJKLMNOPQRSTUVWXYZabcdefghijklmnopqrstuvwxyz0123456789.ABCDEFGHIJKLMNOPQRSTUVWXYZabcdefghijklmnopqrstuvwxyz0123456789.ABCDEFGHIJKLMNOPQRSTUVWXYZabcdefghijklmnopqrstuvwxyz0123456789.ABCDEFGHIJKLMNOPQRSTUVWXYZabcdefghijklmnopqrstuvwxyz0123456789.ABCDEFGHIJKLMNOPQRSTUVWXYZabcdefghijklmnopqrstuvwxyz0123456789.ABCDEFGHIJKLMNOPQRSTUVWXYZabcdefghijklmnopqrstuvwxyz0123456789.ABCDEFGHIJKLMNOPQRSTUVWXYZabcdefghijklmnopqrstuvwxyz0123456789.ABCDEFGHIJKLMNOPQRSTUVWXYZabcdefghijklmnopqrstuvwxyz0123456789.ABCDEFGHIJKLMNOPQRSTUVWXYZabcdefghijklmnopqrstuvwxyz0123456789.ABCDEFGHIJKLMNOPQRSTUVWXYZabcdefghijklmnopqrstuvwxyz0123456789.ABCDEFGHIJKLMNOPQRSTUVWXYZabcdefghijklmnopqrstuvwxyz0123456789.ABCDEFGHIJKLMNOPQRSTUVWXYZabcdefghijklmnopqrstuvwxyz0123456789.ABCDEFGHIJKLMNOPQRSTUVWXYZabcdefghijklmnopqrstuvwxyz0123456789.ABCDEFGHIJKLMNOPQRSTUVWXYZabcdefghijklmnopqrstuvwxyz0123456789.ABCDEFGHIJKLMNOPQRSTUVWXYZabcdefghijklmnopqrstuvwxyz0123456789.ABCDEFGHIJKLMNOPQRSTUVWXYZabcdefghijklmnopqrstuvwxyz0123456789.ABCDEFGHIJKLMNOPQRSTUVWXYZabcdefghijklmnopqrstuvwxyz0123456789.ABCDEFGHIJKLMNOPQRSTUVWXYZabcdefghijklmnopqrstuvwxyz0123456789.ABCDEFGHIJKLMNOPQRSTUVWXYZabcdefghijklmnopqrstuvwxyz0123456789.ABCDEFGHIJKLMNOPQRSTUVWXYZabcdefghijklmnopqrstuvwxyz0123456789.ABCDEFGHIJKLMNOPQRSTUVWXYZabcdefghijklmnopqrstuvwxyz0123456789.ABCDEFGHIJKLMNOPQRSTUVWXYZabcdefghijklmnopqrstuvwxyz0123456789.ABCDEFGHIJKLMNOPQRSTUVWXYZabcdefghijklmnopqrstuvwxyz0123456789.ABCDEFGHIJKLMNOPQRSTUVWXYZabcdefghijklmnopqrstuvwxyz0123456789.ABCDEFGHIJKLMNOPQRSTUVWXYZabcdefghijklmnopqrstuvwxyz0123456789.ABCDEFGHIJKLMNOPQRSTUVWXYZabcdefghijklmnopqrstuvwxyz0123456789.ABCDEFGHIJKLMNOPQRSTUVWXYZabcdefghijklmnopqrstuvwxyz0123456789.ABCDEFGHIJKLMNOPQRSTUVWXYZabcdefghijklmnopqrstuvwxyz0123456789.ABCDEFGHIJKLMNOPQRSTUVWXYZabcdefghijklmnopqrstuvwxyz0123456789.ABCDEFGHIJKLMNOPQRSTUVWXYZabcdefghijklmnopqrstuvwxyz0123456789.ABCDEFGHIJKLMNOPQRSTUVWXYZabcdefghijklmnopqrstuvwxyz0123456789.ABCDEFGHIJKLMNOPQRSTUVWXYZabcdefghijklmnopqrstuvwxyz0123456789.ABCDEFGHIJKLMNOPQRSTUVWXYZabcdefghijklmnopqrstuvwxyz0123456789.ABCDEFGHIJKLMNOPQRSTUVWXYZabcdefghijklmnopqrstuvwxyz0123456789.ABCDEFGHIJKLMNOPQRSTUVWXYZabcdefghijklmnopqrstuvwxyz0123456789.ABCDEFGHIJKLMNOPQRSTUVWXYZabcdefghijklmnopqrstuvwxyz0123456789.ABCDEFGHIJKLMNOPQRSTUVWXYZabcdefghijklmnopqrstuvwxyz0123456789.ABCDEFGHIJKLMNOPQRSTUVWXYZabcdefghijklmnopqrstuvwxyz0123456789.ABCDEFGHIJKLMNOPQRSTUVWXYZabcdefghijklmnopqrstuvwxyz0123456789.ABCDEFGHIJKLMNOPQRSTUVWXYZabcdefghijklmnopqrstuvwxyz0123456789.ABCDEFGHIJKLMNOPQRSTUVWXYZabcdefghijklmnopqrstuvwxyz0123456789.ABCDEFGHIJKLMNOPQRSTUVWXYZabcdefghijklmnopqrstuvwxyz0123456789.ABCDEFGHIJKLMNOPQRSTUVWXYZabcdefghijklmnopqrstuvwxyz0123456789.ABCDEFGHIJKLMNOPQRSTUVWXYZabcdefghijklmnopqrstuvwxyz0123456789.ABCDEFGHIJKLMNOPQRSTUVWXYZabcdefghijklmnopqrstuvwxyz0123456789.ABCDEFGHIJKLMNOPQRSTUVWXYZabcdefghijklmnopqrstuvwxyz0123456789.ABCDEFGHIJKLMNOPQRSTUVWXYZabcdefghijklmnopqrstuvwxyz0123456789.ABCDEFGHIJKLMNOPQRSTUVWXYZabcdefghijklmnopqrstuvwxyz0123456789.ABCDEFGHIJKLMNOPQRSTUVWXYZabcdefghijklmnopqrstuvwxyz0123456789.ABCDEFGHIJKLMNOPQRSTUVWXYZabcdefghijklmnopqrstuvwxyz0123456789.ABCDEFGHIJKLMNOPQRSTUVWXYZabcdefghijklmnopqrstuvwxyz0123456789.ABCDEFGHIJKLMNOPQRSTUVWXYZabcdefghijklmnopqrstuvwxyz0123456789.ABCDEFGHIJKLMNOPQRSTUVWXYZabcdefghijklmnopqrstuvwxyz0123456789.ABCDEFGHIJKLMNOPQRSTUVWXYZabcdefghijklmnopqrstuvwxyz0123456789.ABCDEFGHIJKLMNOPQRSTUVWXYZabcdefghijklmnopqrstuvwxyz0123456789.ABCDEFGHIJKLMNOPQRSTUVWXYZabcdefghijklmnopqrstuvwxyz0123456789.ABCDEFGHIJKLMNOPQRSTUVWXYZabcdefghijklmnopqrstuvwxyz0123456789.

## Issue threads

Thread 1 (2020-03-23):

Code stolen

amigaharry, 2020-03-23:
Most of this code was stolen from https://nickslabor.niteto.de/download/
Thats really sad...

AdamKeher, 2020-11-29:
The project uses some of the floppy interface code from Nick's open source project. This implementation operates standalone from a PC using a LCD screen and SD card + ESP for a websocket app. 90% of the code, schematic's and PCB's do not draw on Nick's excellent and generous work. Suitable attribution has been given and the license type chosen for the project is compatible with Nick's.

Closed 2020-11-29.

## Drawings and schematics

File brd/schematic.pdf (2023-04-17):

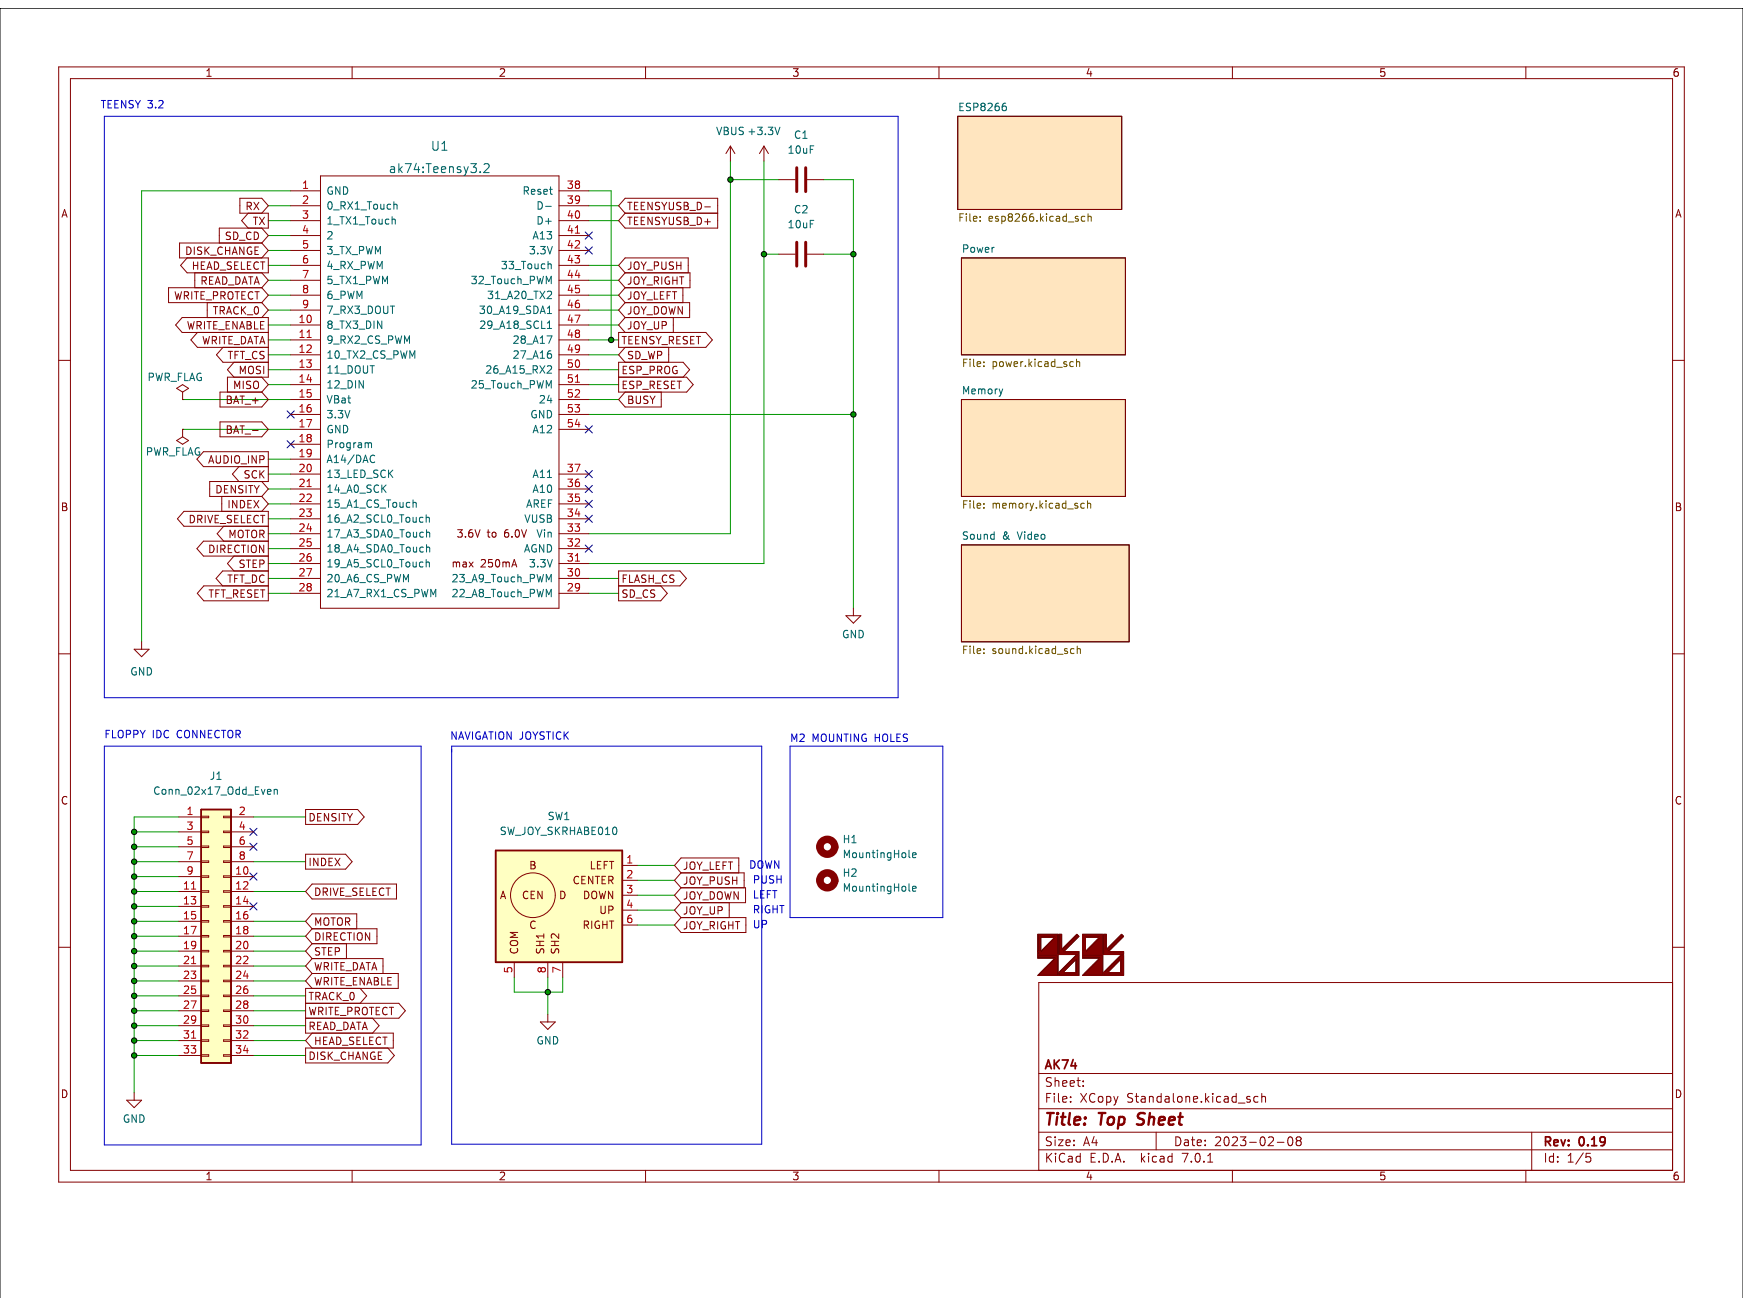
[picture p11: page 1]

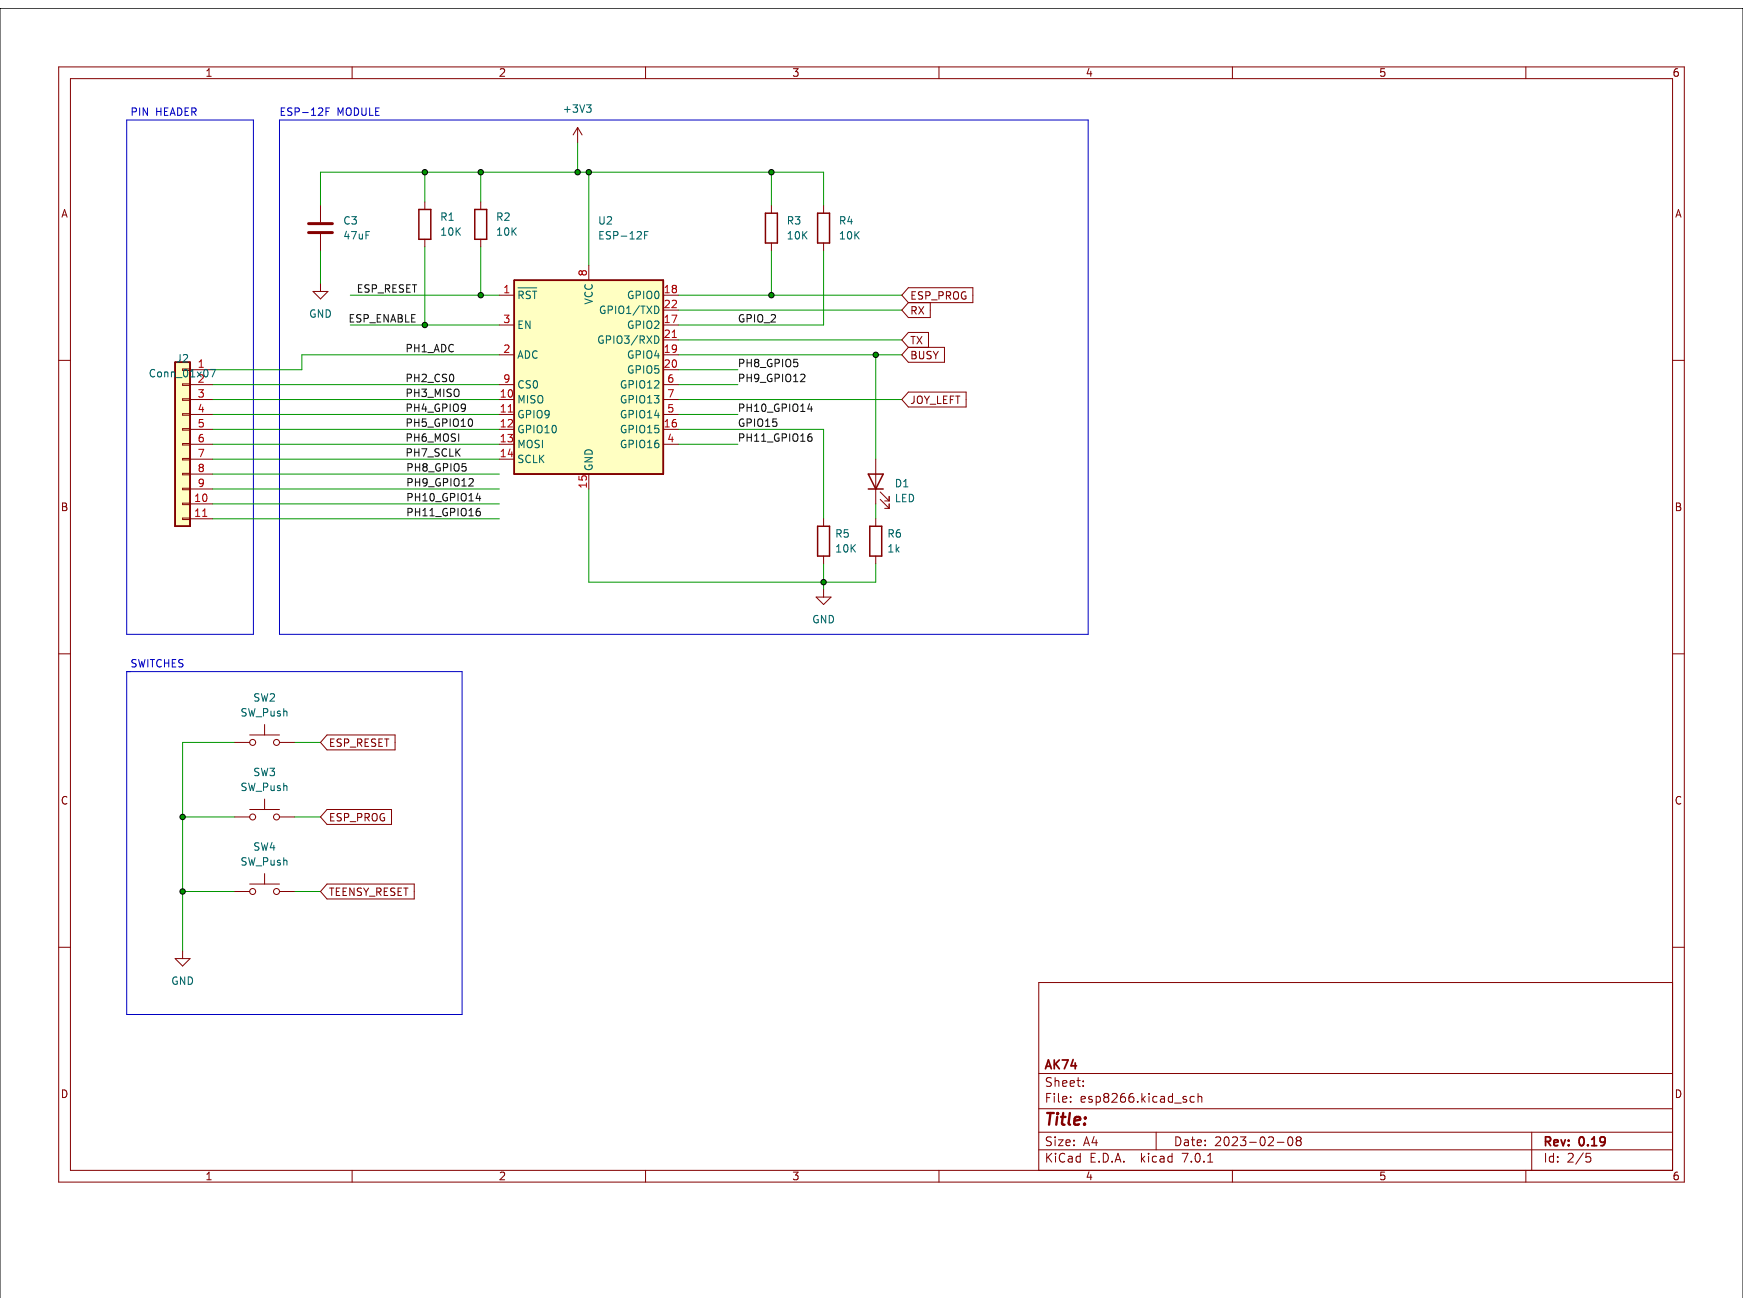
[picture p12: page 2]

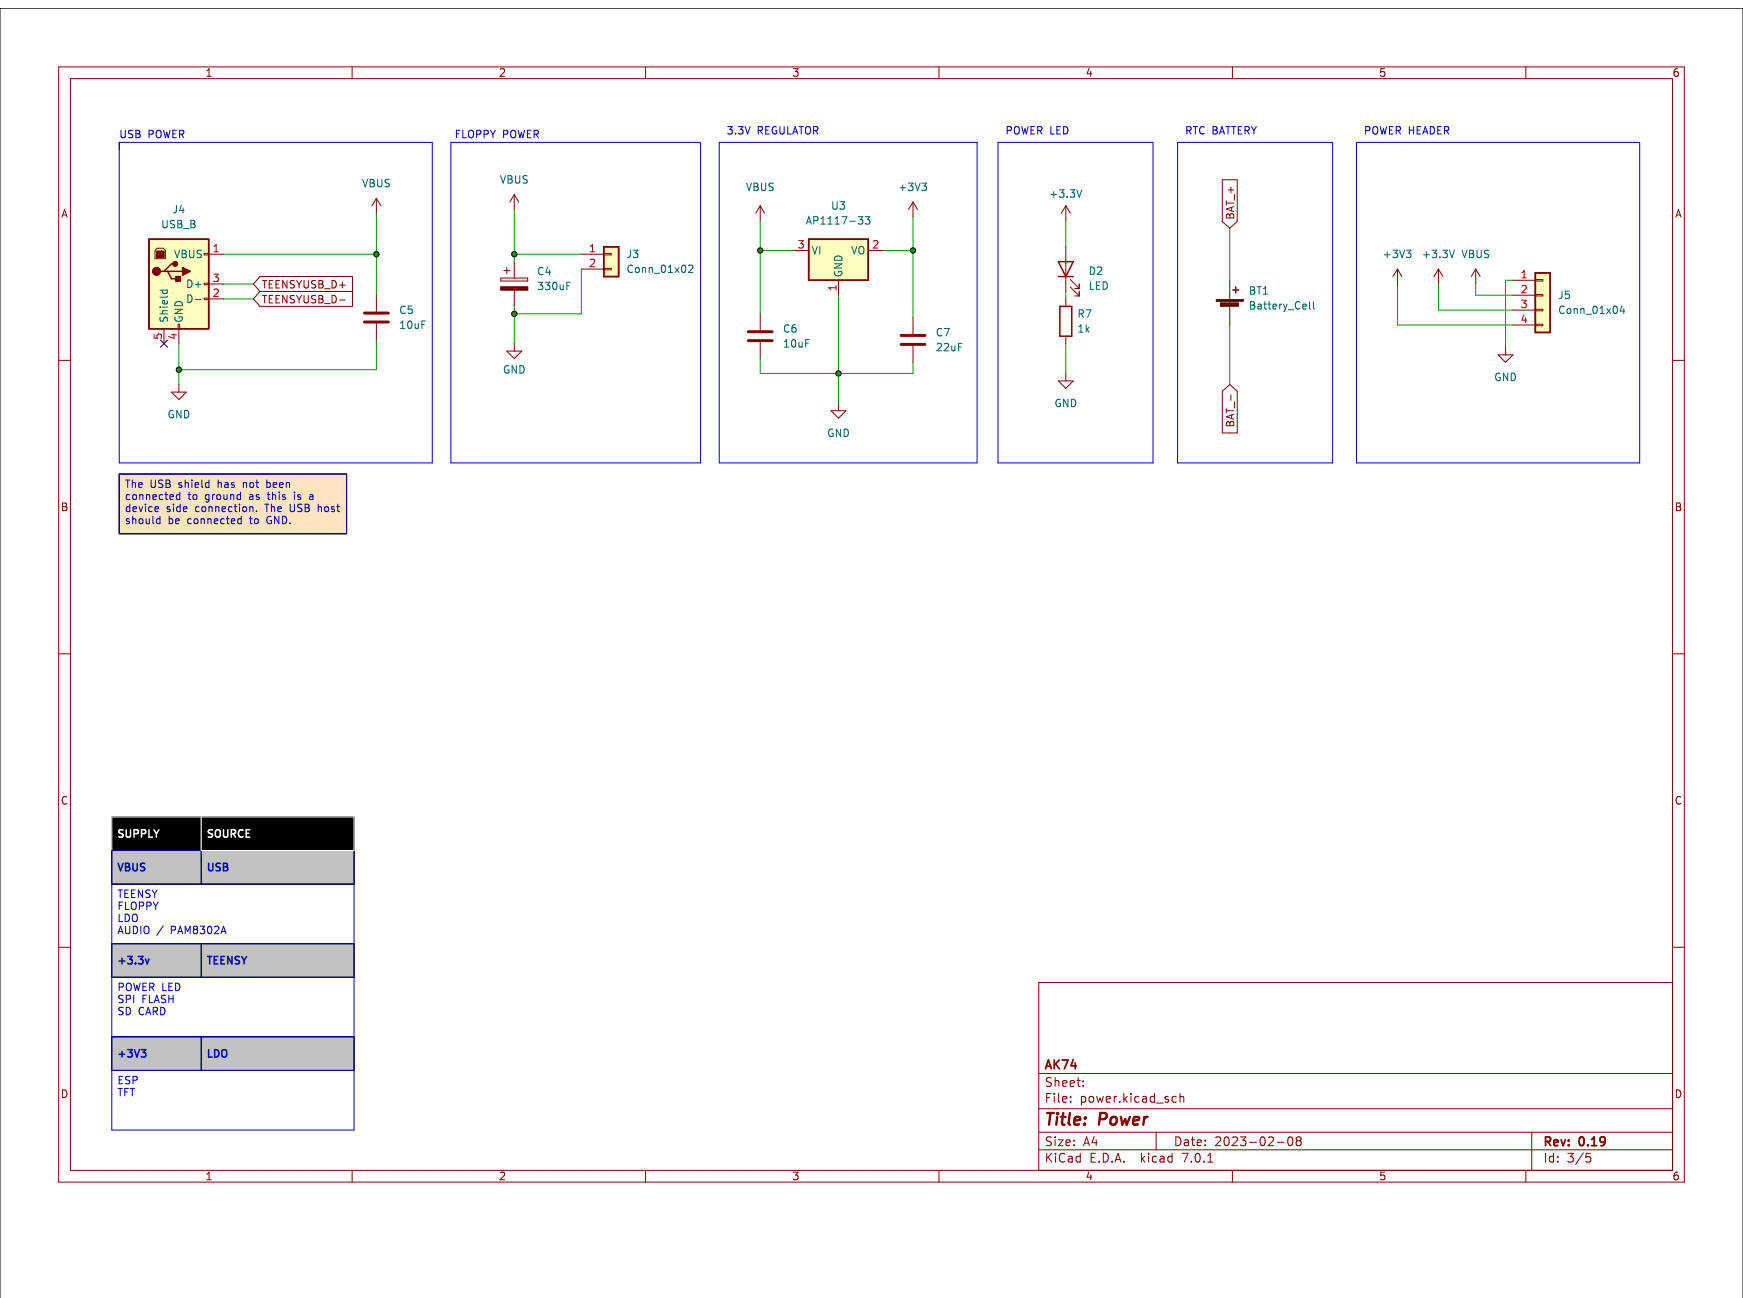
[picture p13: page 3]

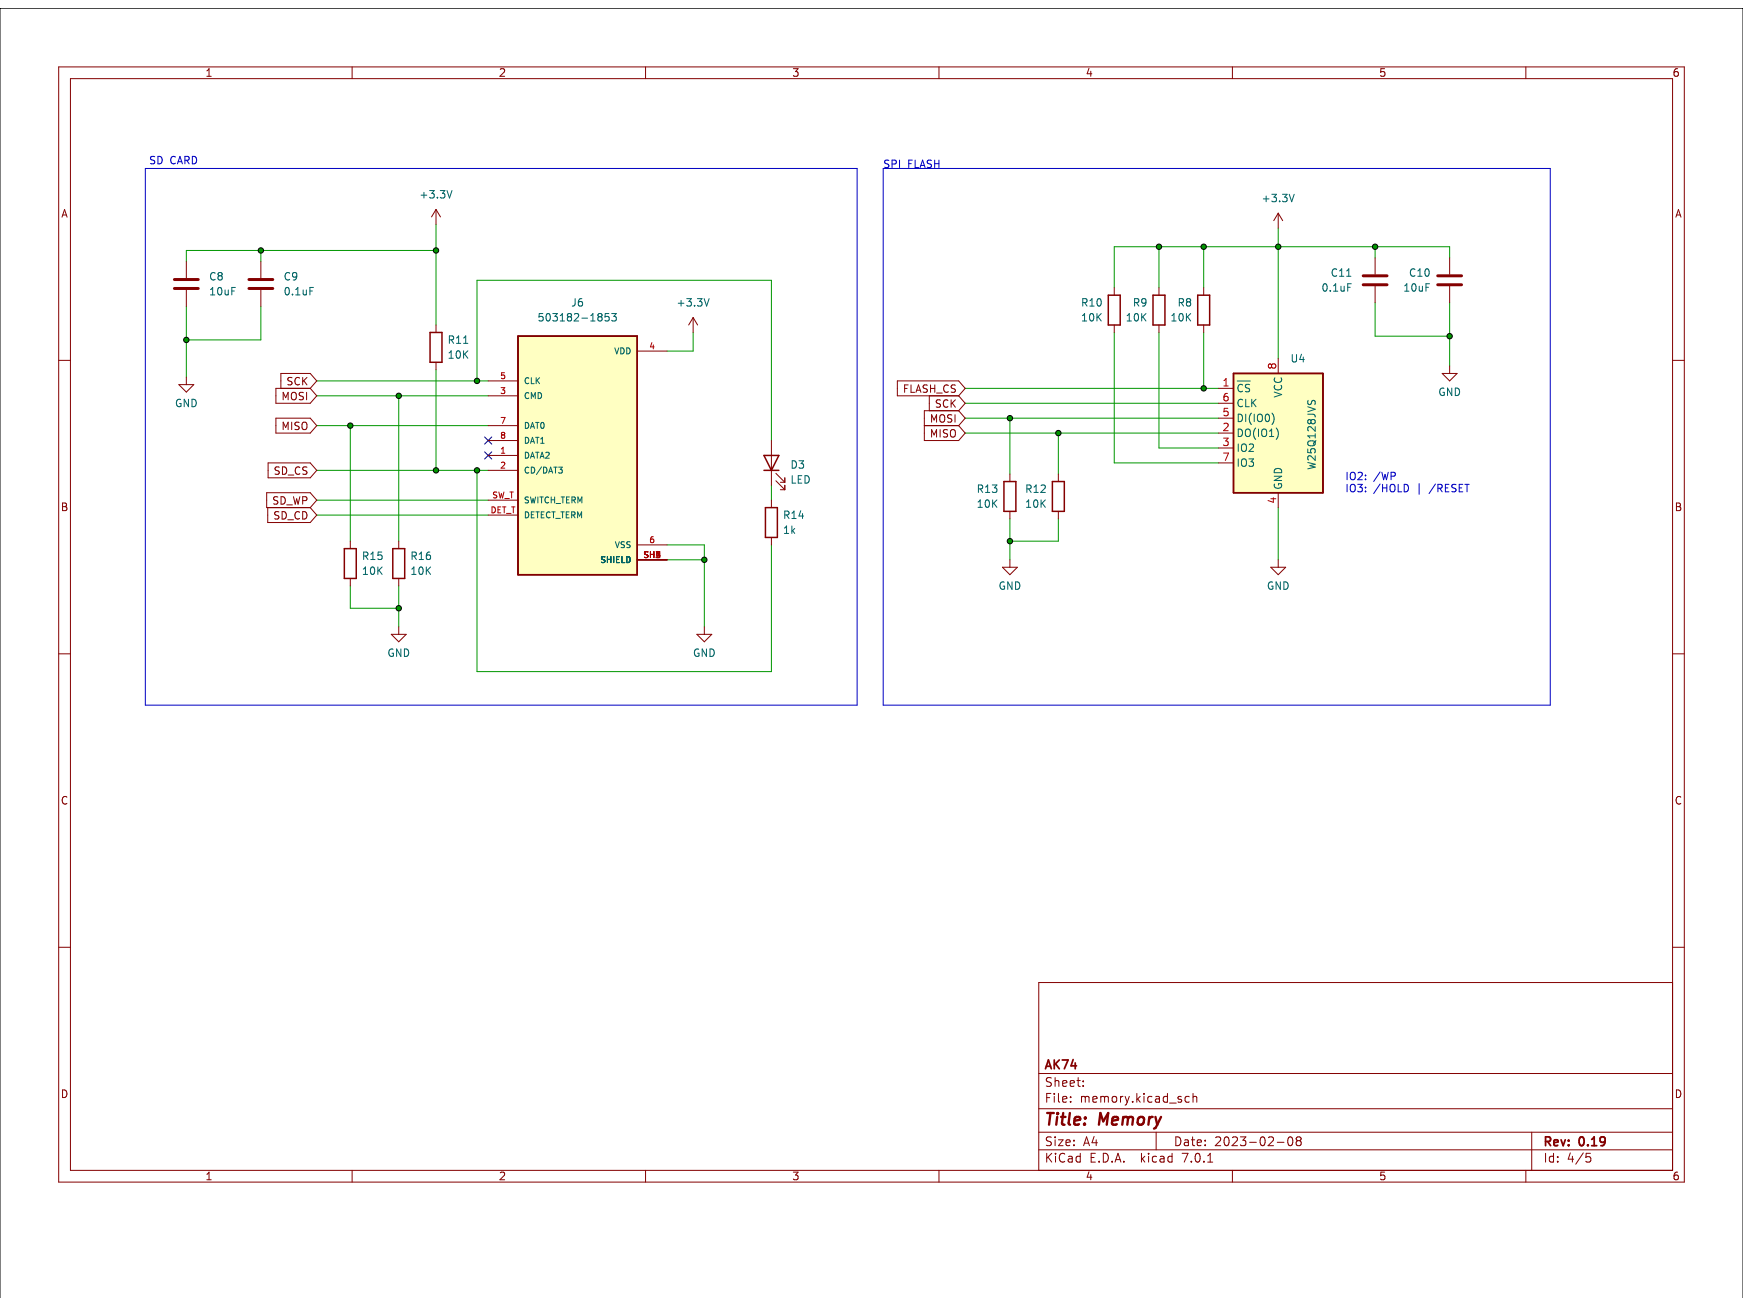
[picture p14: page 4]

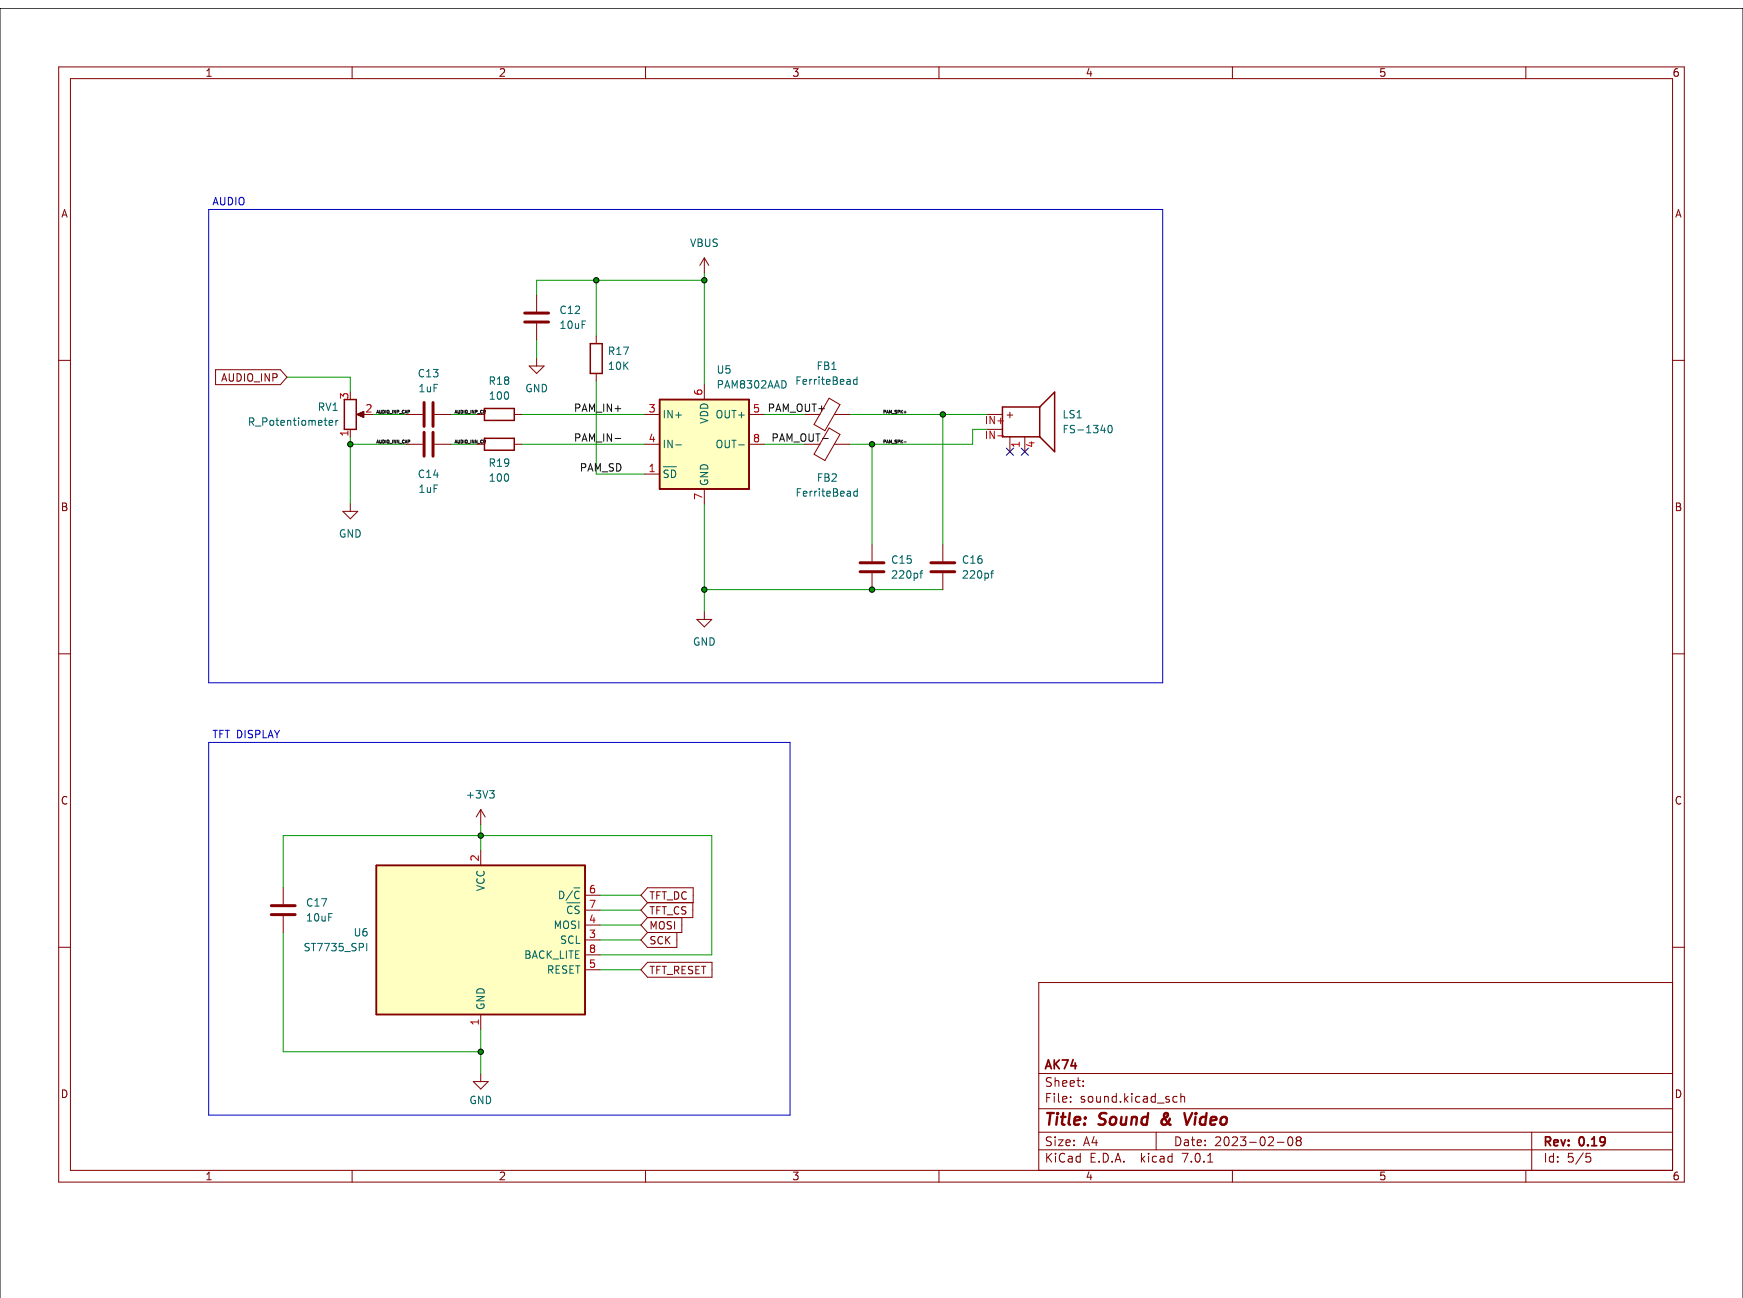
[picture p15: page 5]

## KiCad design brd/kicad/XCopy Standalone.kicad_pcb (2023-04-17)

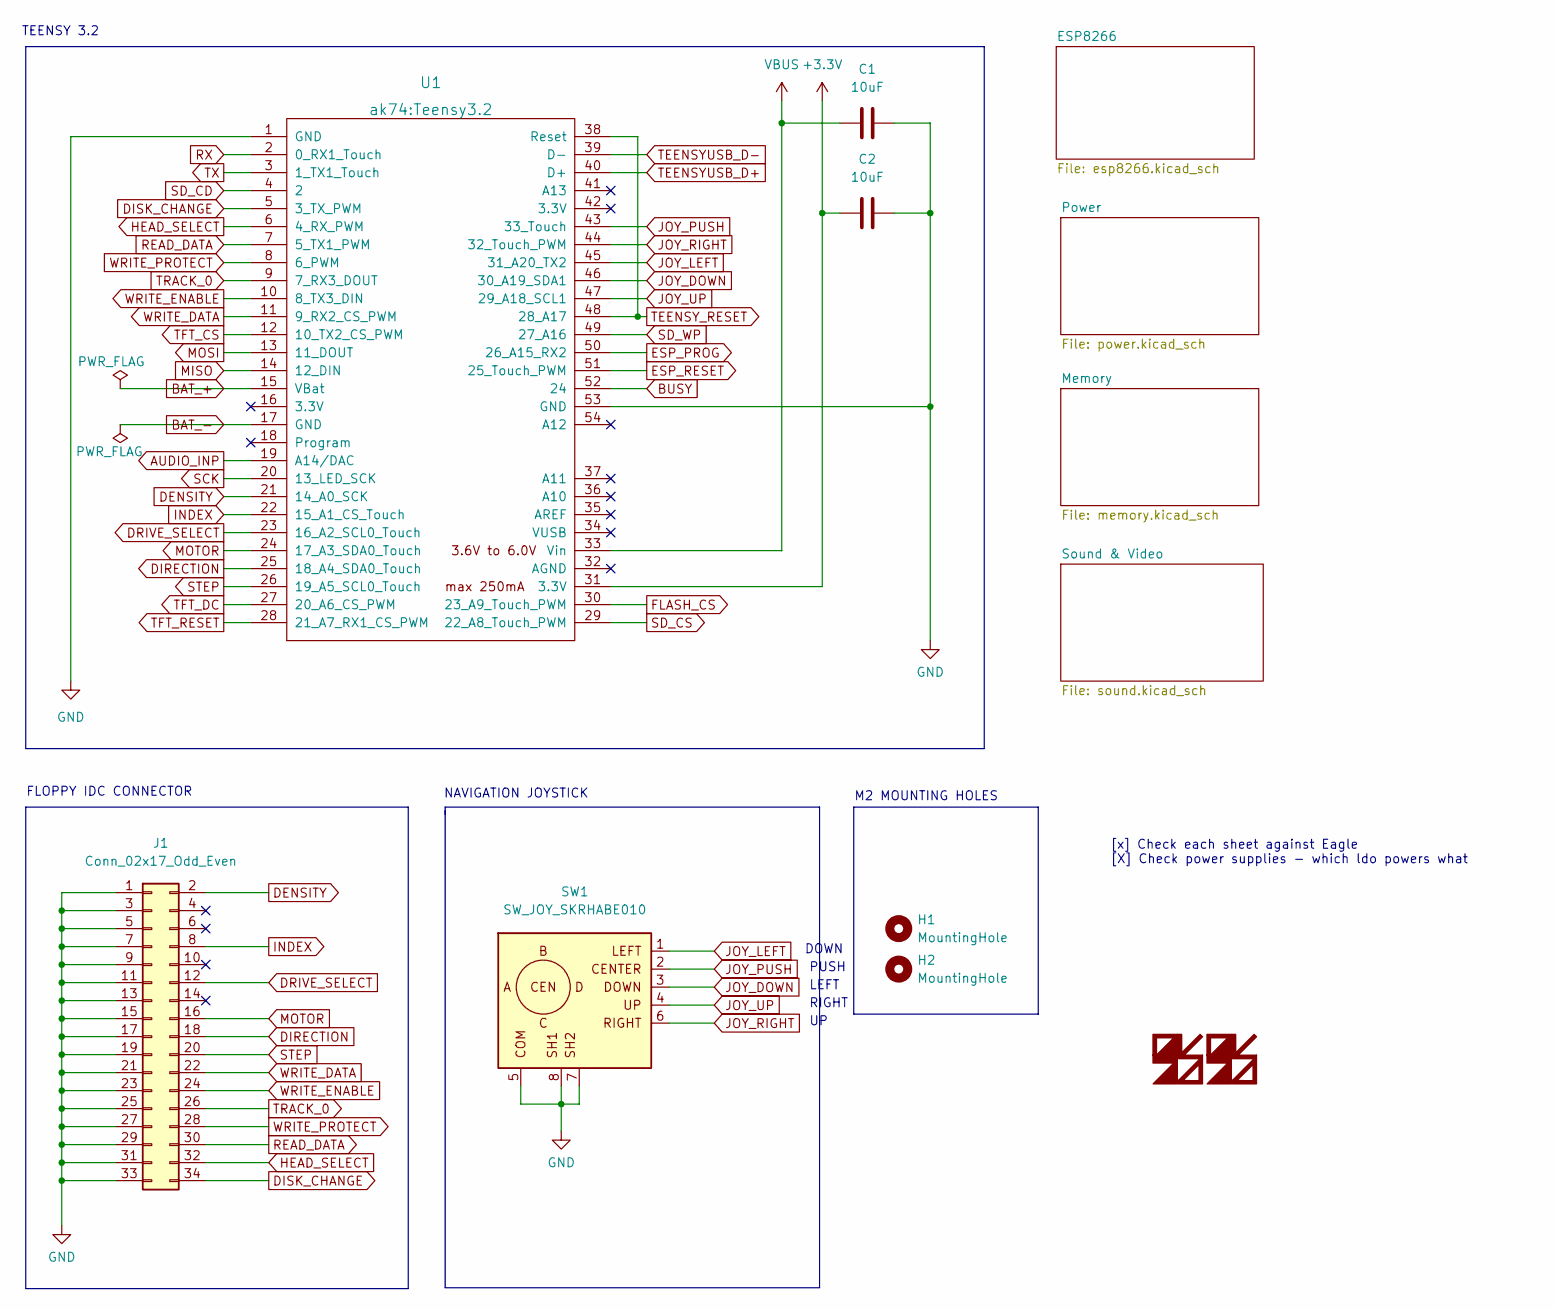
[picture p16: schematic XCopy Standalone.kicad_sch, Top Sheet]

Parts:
C1, C2: 10uF; C_0603_1608Metric_Pad1.08x0.95mm_HandSolder
H1, H2: MountingHole; MountingHole_2.2mm_M2
J1: Conn_02x17_Odd_Even; IDC-Header_2x17_P2.54mm_Horizontal_FLOPPY
SW1: SW_JOY_SKRHABE010; Switches_ALPS-SKRHAAE010; LCSC C139794
U1: ak74:Teensy3.2; Teensy30_31_32_All_Pins

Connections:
+3.3V: C2.2, U1.31 (3.3V); also elsewhere on the board
AUDIO_INP: U1.19 (A14/DAC); also elsewhere on the board
BAT_+: U1.15 (VBat); also elsewhere on the board
BAT_-: U1.17 (GND); also elsewhere on the board
BUSY: U1.52 (24); also elsewhere on the board
DENSITY: J1.2, U1.21 (14_A0_SCK)
DIRECTION: J1.18, U1.25 (18_A4_SDA0_Touch)
DISK_CHANGE: J1.34, U1.5 (3_TX_PWM)
DRIVE_SELECT: J1.12, U1.23 (16_A2_SCL0_Touch)
ESP_PROG: U1.50 (26_A15_RX2); also elsewhere on the board
ESP_RESET: U1.51 (25_Touch_PWM); also elsewhere on the board
FLASH_CS: U1.30 (23_A9_Touch_PWM); also elsewhere on the board
GND: C1.1, C2.1, J1.1, J1.3, J1.5, J1.7, J1.9, J1.11, J1.13, J1.15, J1.17, J1.19, J1.21, J1.23, J1.25, J1.27, J1.29, J1.31, J1.33, SW1.5 (COM), SW1.7 (SH2), SW1.8 (SH1), U1.1 (GND), U1.53 (GND); also elsewhere on the board
HEAD_SELECT: J1.32, U1.6 (4_RX_PWM)
INDEX: J1.8, U1.22 (15_A1_CS_Touch)
JOY_DOWN: SW1.3 (C), U1.46 (30_A19_SDA1)
JOY_LEFT: SW1.1 (A), U1.45 (31_A20_TX2); also elsewhere on the board
JOY_PUSH: SW1.2 (Center), U1.43 (33_Touch)
JOY_RIGHT: SW1.6 (D), U1.44 (32_Touch_PWM)
JOY_UP: SW1.4 (B), U1.47 (29_A18_SCL1)
MISO: U1.14 (12_DIN); also elsewhere on the board
MOSI: U1.13 (11_DOUT); also elsewhere on the board
MOTOR: J1.16, U1.24 (17_A3_SDA0_Touch)
READ_DATA: J1.30, U1.7 (5_TX1_PWM)
RX: U1.2 (0_RX1_Touch); also elsewhere on the board
SCK: U1.20 (13_LED_SCK); also elsewhere on the board
SD_CD: U1.4 (2); also elsewhere on the board
SD_CS: U1.29 (22_A8_Touch_PWM); also elsewhere on the board
SD_WP: U1.49 (27_A16); also elsewhere on the board
STEP: J1.20, U1.26 (19_A5_SCL0_Touch)
TEENSYUSB_D+: U1.40 (D+); also elsewhere on the board
TEENSYUSB_D-: U1.39 (D-); also elsewhere on the board
TEENSY_RESET: U1.38 (Reset), U1.48 (28_A17); also elsewhere on the board
TFT_CS: U1.12 (10_TX2_CS_PWM); also elsewhere on the board
TFT_DC: U1.27 (20_A6_CS_PWM); also elsewhere on the board
TFT_RESET: U1.28 (21_A7_RX1_CS_PWM); also elsewhere on the board
TRACK_0: J1.26, U1.9 (7_RX3_DOUT)
TX: U1.3 (1_TX1_Touch); also elsewhere on the board
VBUS: C1.2, U1.33 (Vin); also elsewhere on the board
WRITE_DATA: J1.22, U1.11 (9_RX2_CS_PWM)
WRITE_ENABLE: J1.24, U1.10 (8_TX3_DIN)
WRITE_PROTECT: J1.28, U1.8 (6_PWM)

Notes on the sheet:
DOWN
NAVIGATION JOYSTICK
TEENSY 3.2
[x] Check each sheet against Eagle [X] Check power supplies - which ldo powers what
M2 MOUNTING HOLES
FLOPPY IDC CONNECTOR
LEFT
RIGHT
PUSH

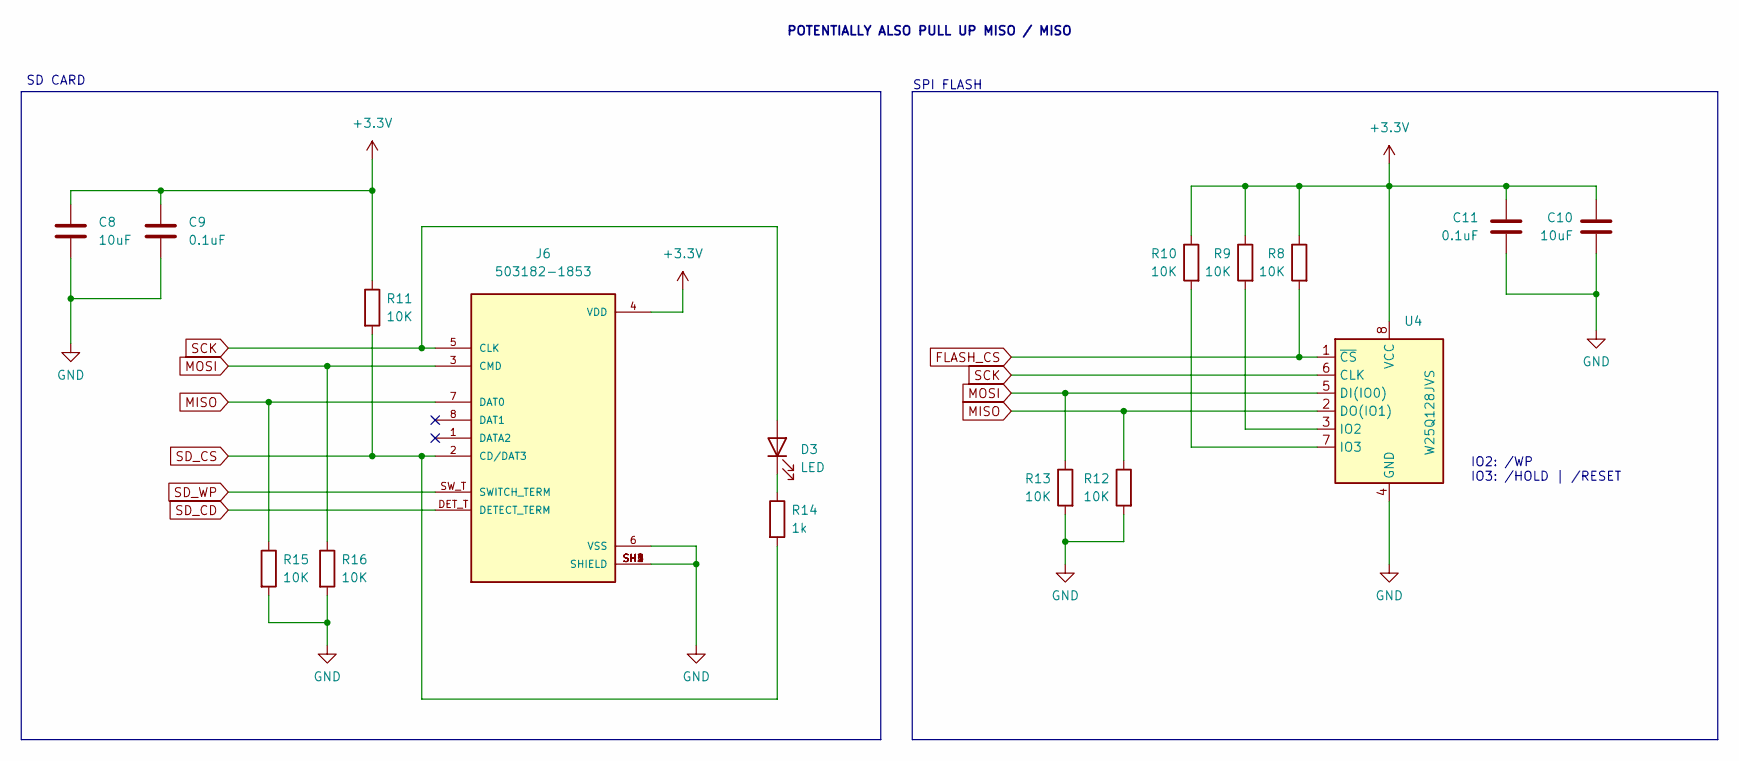
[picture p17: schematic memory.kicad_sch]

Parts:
C8, C10: 10uF; C_0603_1608Metric_Pad1.08x0.95mm_HandSolder
C9, C11: 0.1uF; C_0603_1608Metric_Pad1.08x0.95mm_HandSolder
D3: LED; LED_0603_1608Metric_Pad1.05x0.95mm_HandSolder
J6: 503182-1853; MOLEX_503182-1853-2; PARTREV G; LCSC C266617
R8, R9, R10, R11, R12, R13, R15, R16: 10K; R_0603_1608Metric_Pad0.98x0.95mm_HandSolder
R14: 1k; R_0603_1608Metric_Pad0.98x0.95mm_HandSolder
U4: W25Q128JVS; SOIC-8_5.23x5.23mm_P1.27mm; LCSC C571265

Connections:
+3.3V: C8.1, C9.1, C10.1, C11.1, J6.4 (VDD), R8.1, R9.1, R10.1, R11.1, U4.8 (VCC); also elsewhere on the board
FLASH_CS: R8.2, U4.1 (~CS); also elsewhere on the board
GND: C8.2, C9.2, C10.2, C11.2, J6.6 (VSS), J6.SH1 (SHIELD), J6.SH2 (SHIELD), J6.SH3 (SHIELD), J6.SH4 (SHIELD), J6.SH5 (SHIELD), R12.2, R13.2, R15.2, R16.2, U4.4 (GND); also elsewhere on the board
MISO: J6.7 (DAT0), R12.1, R15.1, U4.2 (DO(IO1)); also elsewhere on the board
MOSI: J6.3 (CMD), R13.1, R16.1, U4.5 (DI(IO0)); also elsewhere on the board
unnamed: D3.1 (K), R14.1
unnamed: R9.2, U4.3 (IO2)
unnamed: R10.2, U4.7 (IO3)
SCK: D3.2 (A), J6.5 (CLK), U4.6 (CLK); also elsewhere on the board
SD_CD: J6.DET_T (DETECT_TERM); also elsewhere on the board
SD_CS: J6.2 (CD/DAT3), R11.2, R14.2; also elsewhere on the board
SD_WP: J6.SW_T (SWITCH_TERM); also elsewhere on the board

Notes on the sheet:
SD CARD
IO2: /WP IO3: /HOLD | /RESET
POTENTIALLY ALSO PULL UP MISO / MISO
SPI FLASH

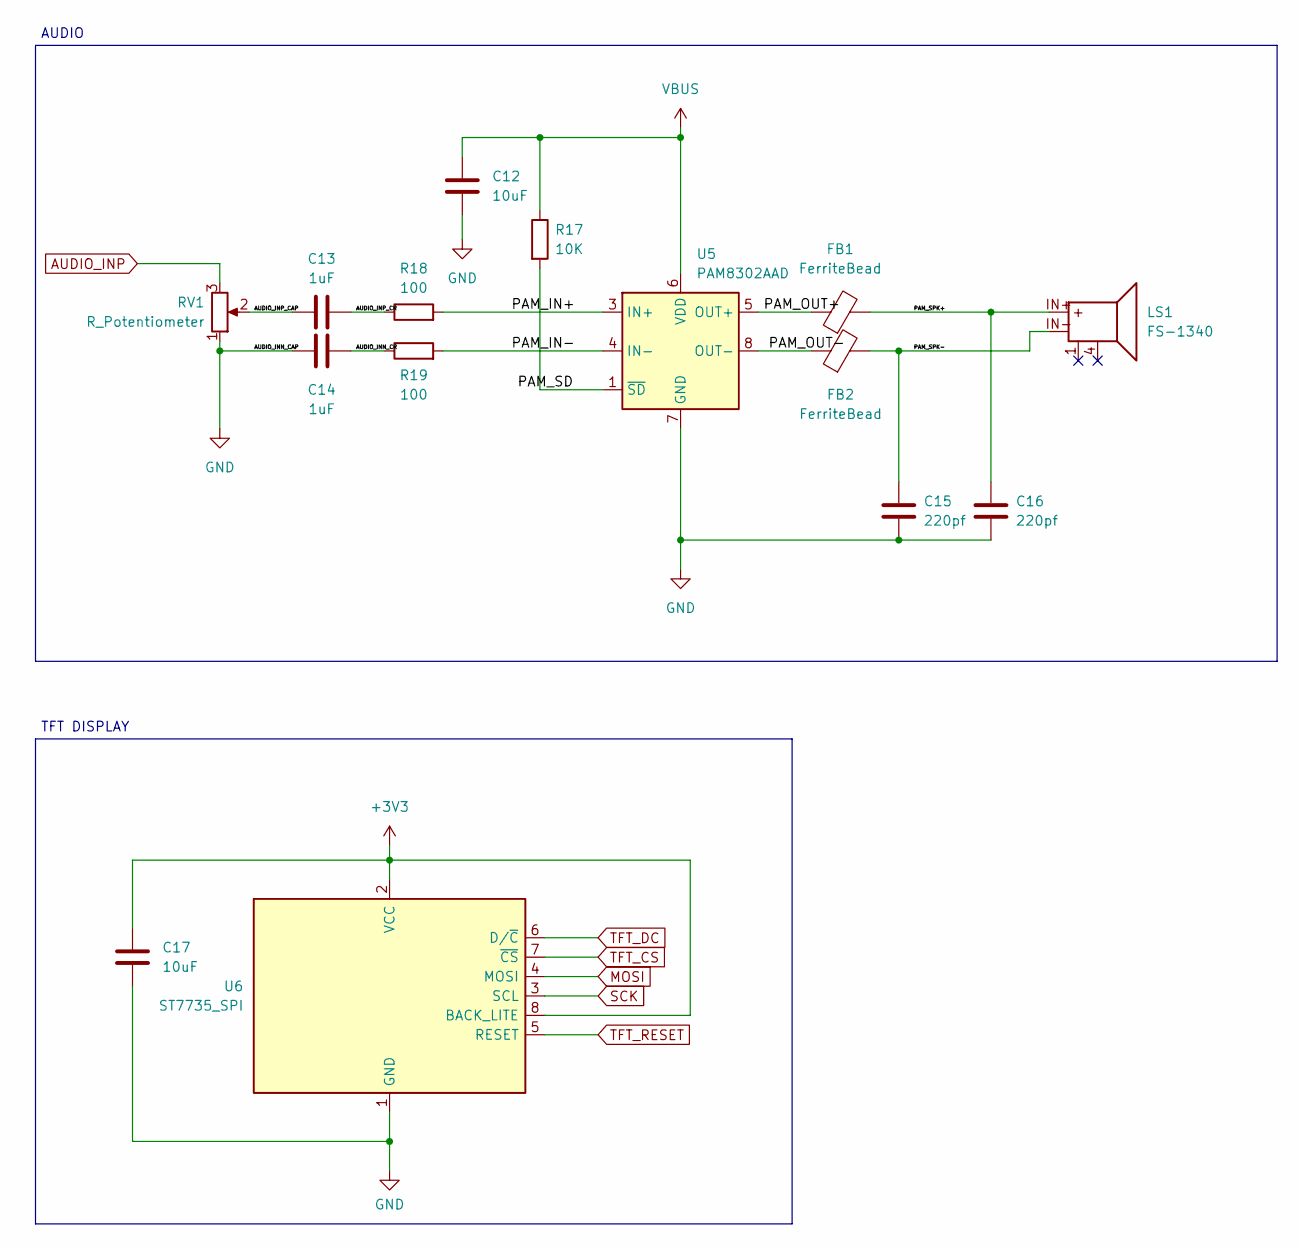
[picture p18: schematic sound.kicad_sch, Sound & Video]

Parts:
C12, C17: 10uF; C_0603_1608Metric_Pad1.08x0.95mm_HandSolder
C13, C14: 1uF; C_0603_1608Metric_Pad1.08x0.95mm_HandSolder
C15, C16: 220pf; C_0603_1608Metric_Pad1.08x0.95mm_HandSolder
FB1, FB2: FerriteBead; R_0805_2012Metric_Pad1.20x1.40mm_HandSolder
LS1: FS-1340; SPK_FUET_FS-1340; LCSC C482342
R17: 10K; R_0603_1608Metric_Pad0.98x0.95mm_HandSolder
R18, R19: 100; R_0603_1608Metric_Pad0.98x0.95mm_HandSolder
RV1: R_Potentiometer; Potentiometer_Bourns_TC33X-2; LCSC C719176
U5: PAM8302AAD; SOP-8_3.9x4.9mm_P1.27mm; LCSC C112137
U6: ST7735_SPI; 1.8in_TFT_ST7735

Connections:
+3V3: C17.2, U6.2 (VCC), U6.8 (BACK_LITE); also elsewhere on the board
/Sound & Video/AUDIO_INN_CR: C14.1, R19.1
/Sound & Video/AUDIO_INP_CAP: C13.1, RV1.2
/Sound & Video/AUDIO_INP_CR: C13.2, R18.1
/Sound & Video/PAM_IN+: R18.2, U5.3 (IN+)
/Sound & Video/PAM_IN-: R19.2, U5.4 (IN-)
/Sound & Video/PAM_OUT+: FB1.1, U5.5 (OUT+)
/Sound & Video/PAM_OUT-: FB2.1, U5.8 (OUT-)
/Sound & Video/PAM_SD: R17.2, U5.1 (~SD)
/Sound & Video/PAM_SPK+: C16.2, FB1.2, LS1.IN+
/Sound & Video/PAM_SPK-: C15.2, FB2.2, LS1.IN-
AUDIO_INP: RV1.3; also elsewhere on the board
GND: C12.2, C14.2, C15.1, C16.1, C17.1, RV1.1, U5.7 (GND), U6.1 (GND); also elsewhere on the board
MOSI: U6.4 (MOSI); also elsewhere on the board
SCK: U6.3 (SCL); also elsewhere on the board
TFT_CS: U6.7 (~CS); also elsewhere on the board
TFT_DC: U6.6 (D/~C); also elsewhere on the board
TFT_RESET: U6.5 (RESET); also elsewhere on the board
VBUS: C12.1, R17.1, U5.6 (VDD); also elsewhere on the board

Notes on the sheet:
AUDIO
TFT DISPLAY

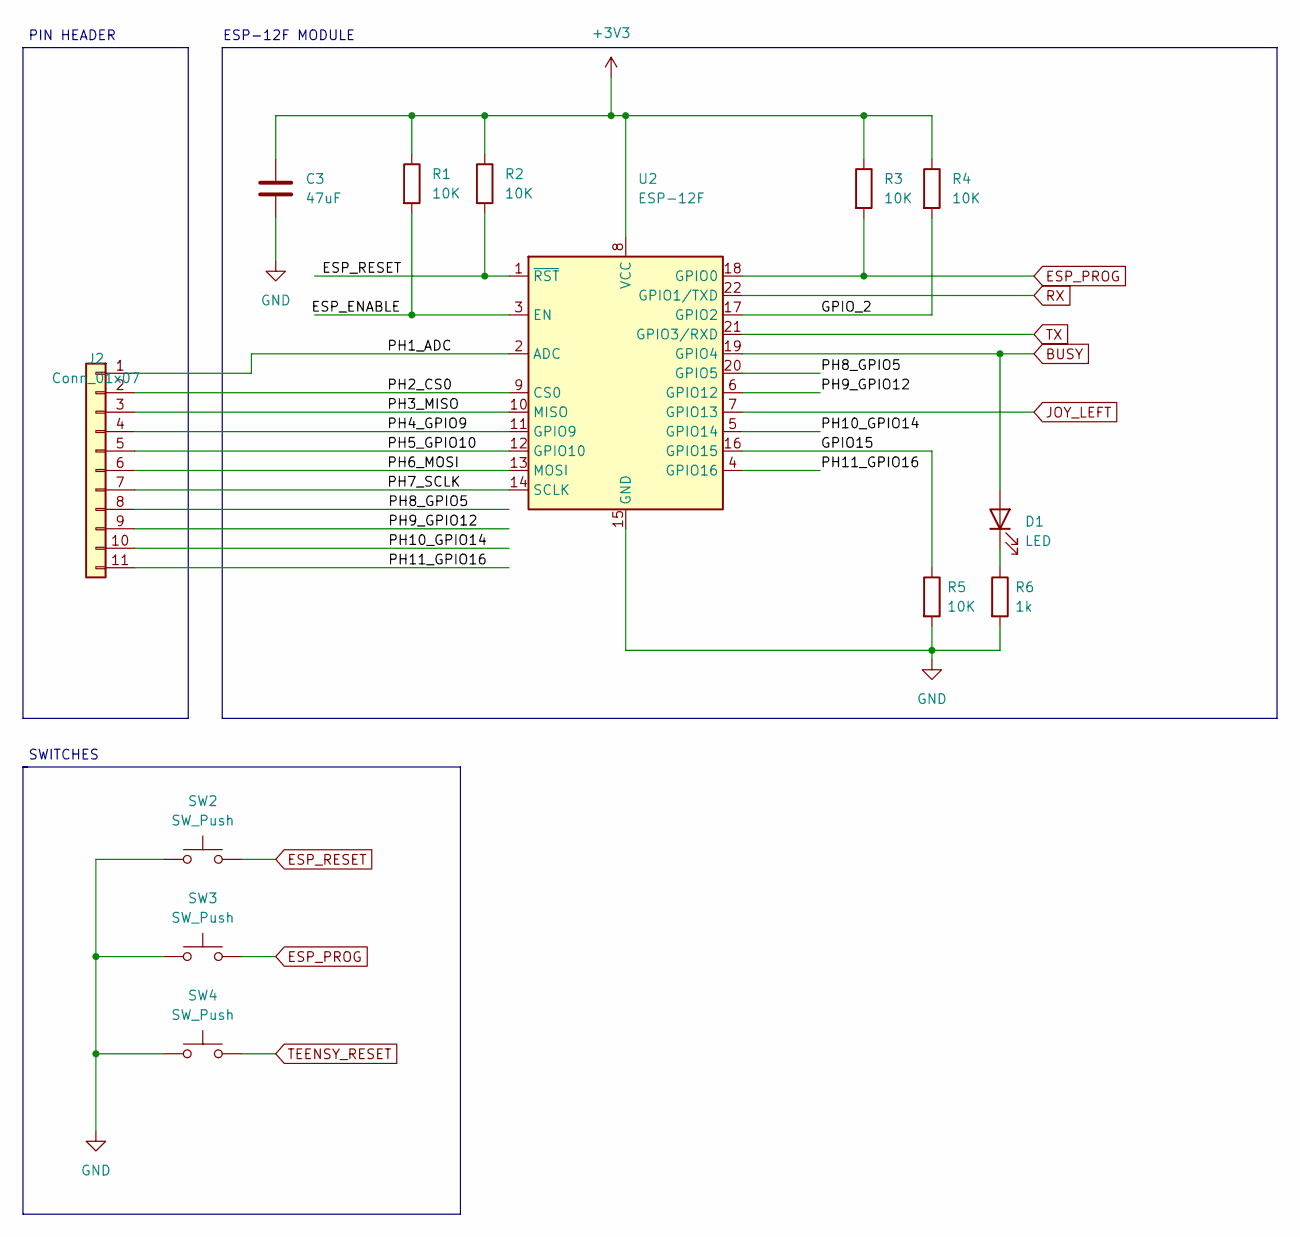
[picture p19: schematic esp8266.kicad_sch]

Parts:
C3: 47uF; C_0805_2012Metric_Pad1.18x1.45mm_HandSolder
D1: LED; LED_0603_1608Metric_Pad1.05x0.95mm_HandSolder
J2: Conn_01x07; PinHeader_1x11_P2.54mm_Vertical
R1, R2, R3, R4, R5: 10K; R_0603_1608Metric_Pad0.98x0.95mm_HandSolder
R6: 1k; R_0603_1608Metric_Pad0.98x0.95mm_HandSolder
SW2, SW3, SW4: SW_Push; SW_SKSCLDE010; LCSC C115362
U2: ESP-12F; ESP-12E

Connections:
+3V3: C3.1, R1.1, R2.1, R3.1, R4.1, U2.8 (VCC); also elsewhere on the board
/ESP8266/ESP_ENABLE: R1.2, U2.3 (EN)
/ESP8266/GPIO15: R5.1, U2.16 (GPIO15)
/ESP8266/GPIO_2: R4.2, U2.17 (GPIO2)
/ESP8266/PH1_ADC: J2.1, U2.2 (ADC)
/ESP8266/PH2_CS0: J2.2, U2.9 (CS0)
/ESP8266/PH3_MISO: J2.3, U2.10 (MISO)
/ESP8266/PH4_GPIO9: J2.4, U2.11 (GPIO9)
/ESP8266/PH5_GPIO10: J2.5, U2.12 (GPIO10)
/ESP8266/PH6_MOSI: J2.6, U2.13 (MOSI)
/ESP8266/PH7_SCLK: J2.7, U2.14 (SCLK)
/ESP8266/PH8_GPIO5: J2.8, U2.20 (GPIO5)
/ESP8266/PH9_GPIO12: J2.9, U2.6 (GPIO12)
/ESP8266/PH10_GPIO14: J2.10, U2.5 (GPIO14)
/ESP8266/PH11_GPIO16: J2.11, U2.4 (GPIO16)
BUSY: D1.2 (A), U2.19 (GPIO4); also elsewhere on the board
ESP_PROG: R3.2, SW3.2, U2.18 (GPIO0); also elsewhere on the board
ESP_RESET: R2.2, SW2.2, U2.1 (~RST); also elsewhere on the board
GND: C3.2, R5.2, R6.2, SW2.1, SW3.1, SW4.1, U2.15 (GND); also elsewhere on the board
JOY_LEFT: U2.7 (GPIO13); also elsewhere on the board
unnamed: D1.1 (K), R6.1
RX: U2.22 (GPIO1/TXD); also elsewhere on the board
TEENSY_RESET: SW4.2; also elsewhere on the board
TX: U2.21 (GPIO3/RXD); also elsewhere on the board

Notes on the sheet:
ESP-12F MODULE
PIN HEADER
SWITCHES

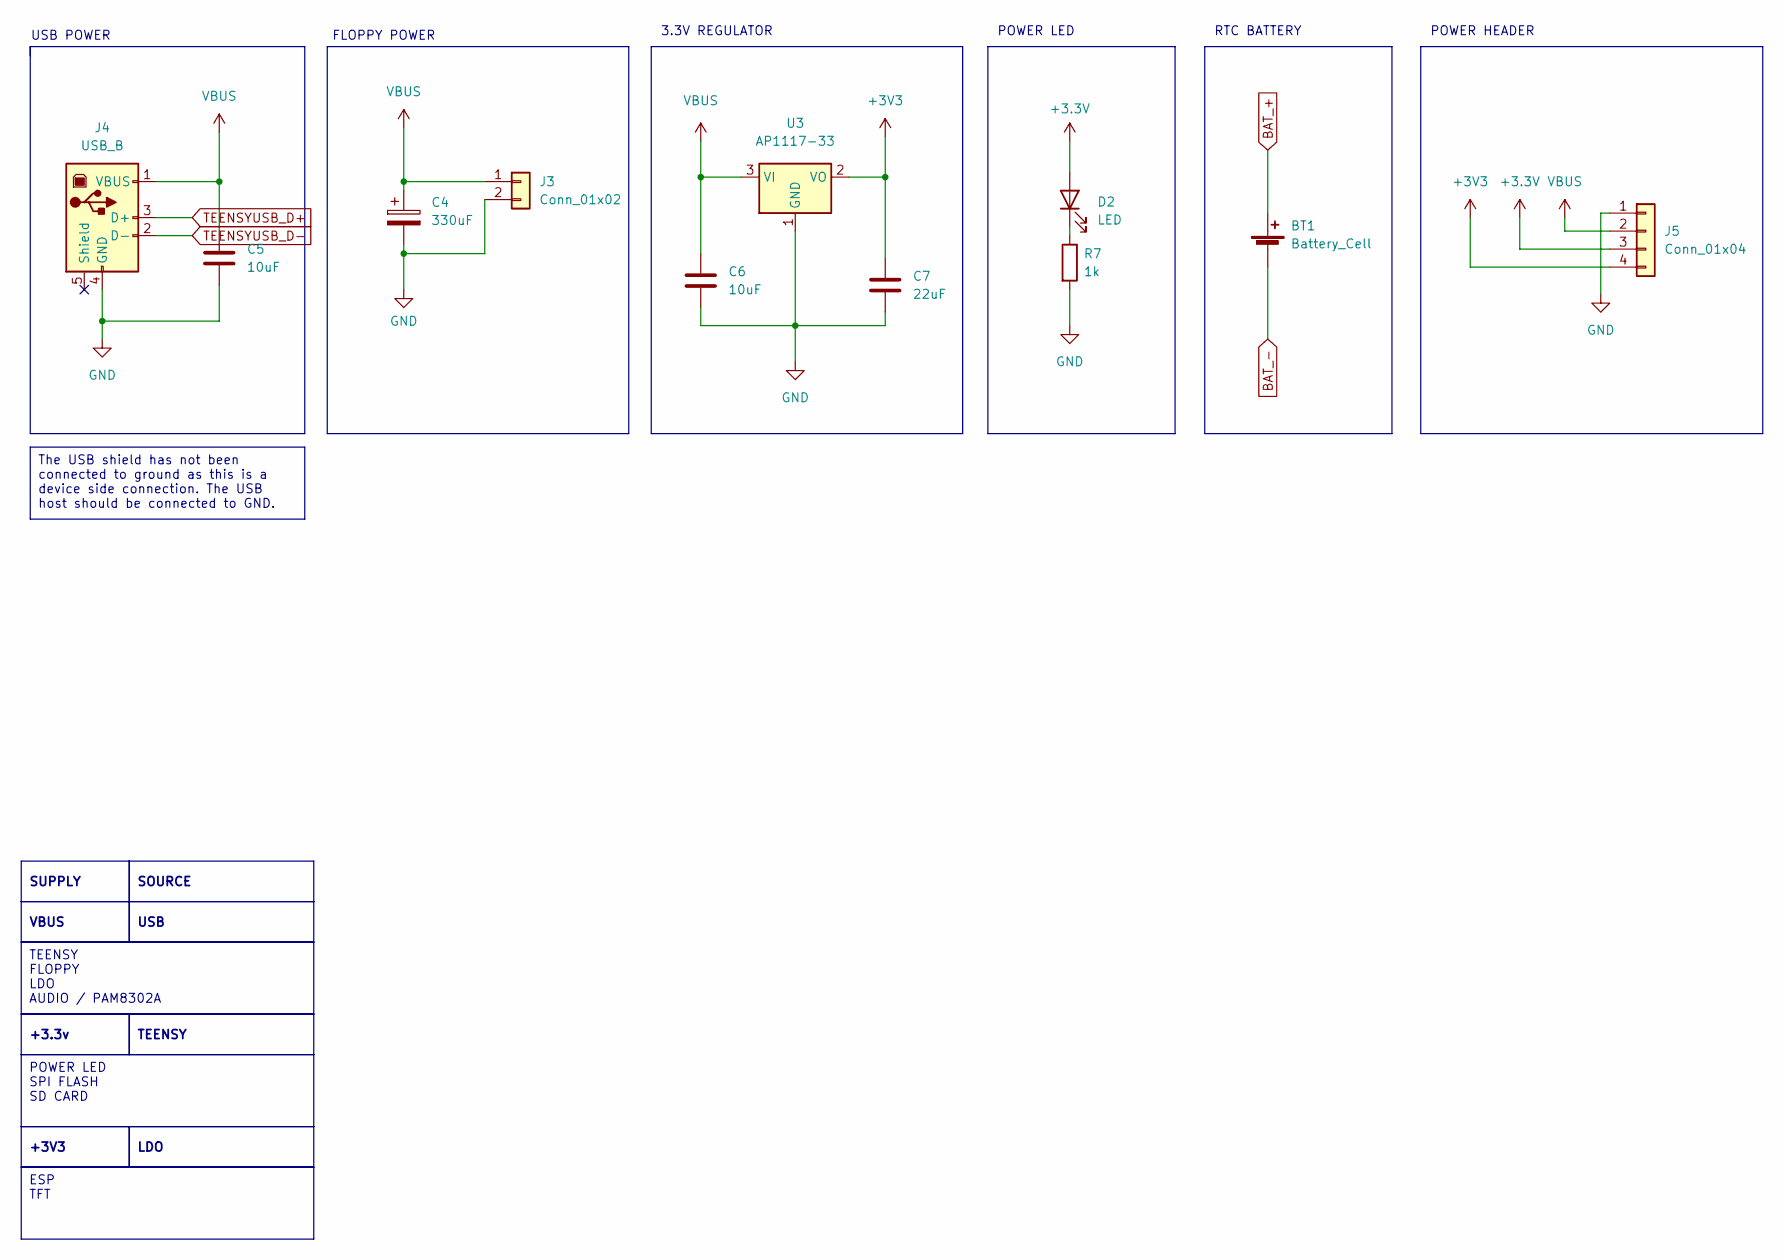
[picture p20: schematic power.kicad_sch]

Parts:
BT1: Battery_Cell; keystone-PN1056TR; LCSC C964750
C4: 330uF; CP_Elec_6.3x5.8; LCSC C286137
C5, C6: 10uF; C_0603_1608Metric_Pad1.08x0.95mm_HandSolder
C7: 22uF; C_0603_1608Metric_Pad1.08x0.95mm_HandSolder
D2: LED; LED_0603_1608Metric_Pad1.05x0.95mm_HandSolder
J3: Conn_01x02; PinHeader_1x02_P2.54mm_Vertical
J4: USB_B; USB_B_OST_USB_Horizontal-Jing-Extension-111A1010D10200; LCSC C46392
J5: Conn_01x04; PinHeader_2x02_P2.54mm_Vertical
R7: 1k; R_0603_1608Metric_Pad0.98x0.95mm_HandSolder
U3: AP1117-33; SOT-223-3_TabPin2; LCSC C347222

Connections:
+3.3V: D2.2 (A), J5.3; also elsewhere on the board
+3V3: C7.1, J5.4, U3.2 (VO); also elsewhere on the board
BAT_+: BT1.1 (+); also elsewhere on the board
BAT_-: BT1.2 (-); also elsewhere on the board
GND: C4.2, C5.2, C6.2, C7.2, J3.2, J4.4 (GND), J5.1, R7.2, U3.1 (GND); also elsewhere on the board
unnamed: D2.1 (K), R7.1
TEENSYUSB_D+: J4.3 (D+); also elsewhere on the board
TEENSYUSB_D-: J4.2 (D-); also elsewhere on the board
VBUS: C4.1, C5.1, C6.1, J3.1, J4.1 (VBUS), J5.2, U3.3 (VI); also elsewhere on the board

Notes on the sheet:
POWER LED SPI FLASH SD CARD
TEENSY
ESP TFT
TEENSY FLOPPY LDO AUDIO / PAM8302A
USB
The USB shield has not been connected to ground as this is a device side connection. The USB host should be connected to GND.
LDO
SUPPLY
+3V3
VBUS
SOURCE
+3.3v
3.3V REGULATOR
RTC BATTERY
POWER LED
FLOPPY POWER
POWER HEADER
USB POWER

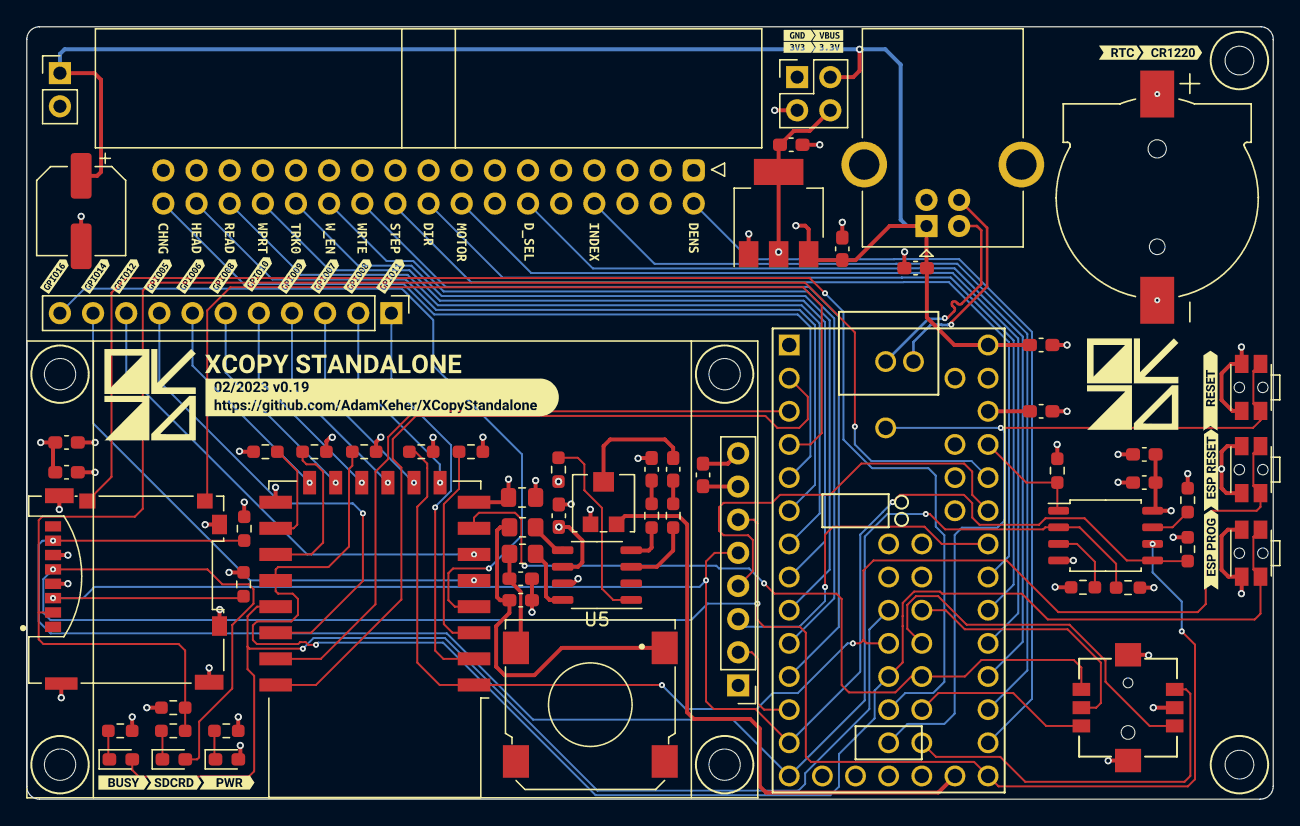
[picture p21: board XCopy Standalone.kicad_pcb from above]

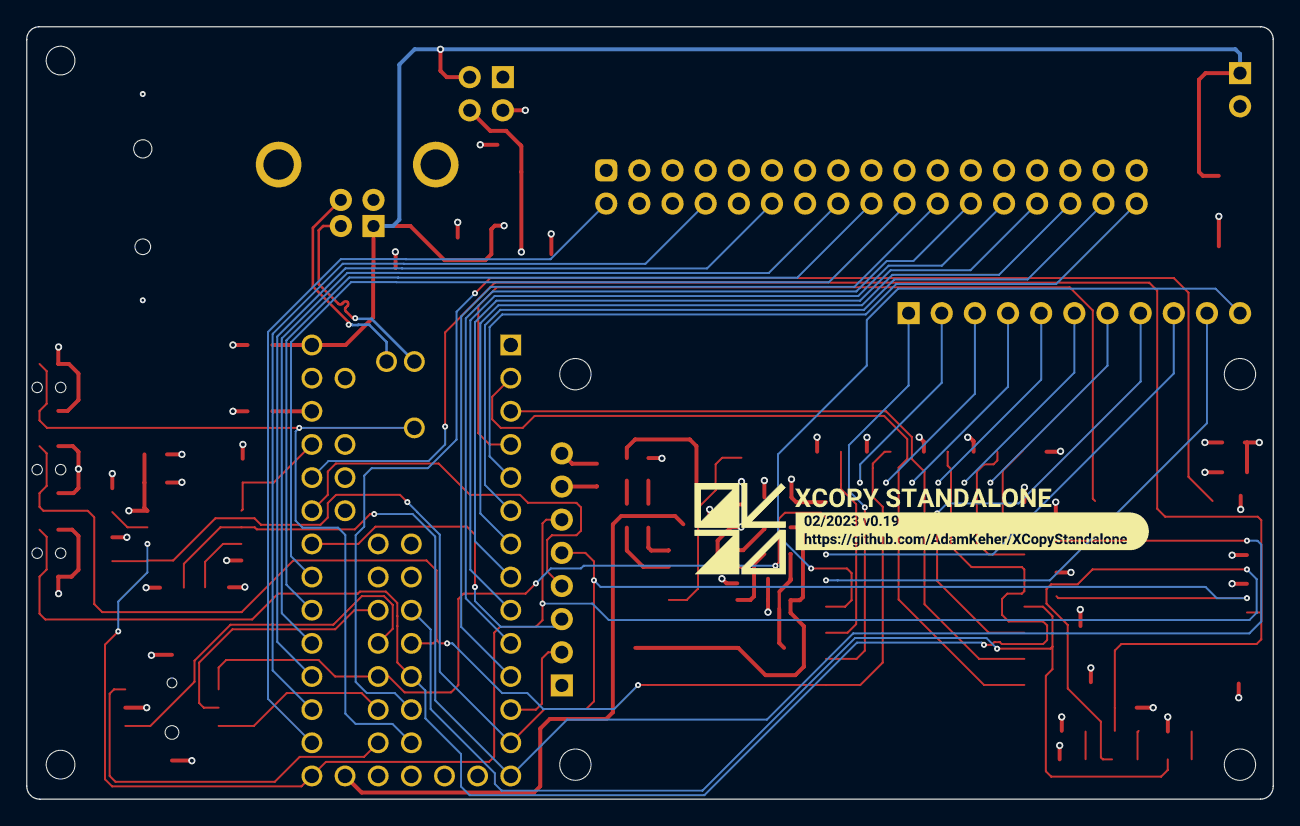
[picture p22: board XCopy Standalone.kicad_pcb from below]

Board: 4 copper layers, 95.5 x 59.2 mm, 102 parts (2 on the bottom side), 72 nets.

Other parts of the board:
kibuzzard-63E64A01: G***; kibuzzard-63E64A01
kibuzzard-63E64B6F: G***; kibuzzard-63E64B6F
kibuzzard-63E64BAD: G***; kibuzzard-63E64BAD
kibuzzard-63E65A6E: G***; kibuzzard-63E65A6E
kibuzzard-63E65E35, kibuzzard-63E65E35#2: G***; kibuzzard-63E65E35
kibuzzard-63E65F2C: G***; kibuzzard-63E65F2C
kibuzzard-63E65F17: G***; kibuzzard-63E65F17
kibuzzard-63E78C9C: G***; kibuzzard-63E78C9C
kibuzzard-63E78C36: G***; kibuzzard-63E78C36
kibuzzard-63E78C45: G***; kibuzzard-63E78C45
kibuzzard-63E78C77: G***; kibuzzard-63E78C77
kibuzzard-63E648B8, kibuzzard-63E648B8#2: G***; kibuzzard-63E648B8
kibuzzard-63E649A5: G***; kibuzzard-63E649A5
kibuzzard-63E649C1: G***; kibuzzard-63E649C1
kibuzzard-63E649E9: G***; kibuzzard-63E649E9
kibuzzard-63E650D0: G***; kibuzzard-63E650D0
kibuzzard-63E650FB: G***; kibuzzard-63E650FB
kibuzzard-63E651BF: G***; kibuzzard-63E651BF
kibuzzard-63E652DF, kibuzzard-63E652DF#2: G***; kibuzzard-63E652DF
kibuzzard-63E655A7: G***; kibuzzard-63E655A7
kibuzzard-63E6473B: G***; kibuzzard-63E6473B
kibuzzard-63E6479F: G***; kibuzzard-63E6479F
kibuzzard-63E6490B: G***; kibuzzard-63E6490B
kibuzzard-63E6512D: G***; kibuzzard-63E6512D
kibuzzard-63E6513B: G***; kibuzzard-63E6513B
kibuzzard-63E6514F: G***; kibuzzard-63E6514F
kibuzzard-63E6515C: G***; kibuzzard-63E6515C
kibuzzard-63E6582B: G***; kibuzzard-63E6582B
kibuzzard-63E65082: G***; kibuzzard-63E65082
kibuzzard-63E65107: G***; kibuzzard-63E65107
kibuzzard-63E65113: G***; kibuzzard-63E65113
kibuzzard-63E65145: G***; kibuzzard-63E65145
kibuzzard-63E65580: G***; kibuzzard-63E65580
kibuzzard-63E65598: G***; kibuzzard-63E65598
kibuzzard-63E65800: G***; kibuzzard-63E65800
kibuzzard-63E65845: G***; kibuzzard-63E65845
kibuzzard-63E65952: G***; kibuzzard-63E65952

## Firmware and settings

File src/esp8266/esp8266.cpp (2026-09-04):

#include "Arduino.h"
#include <ESP8266WiFi.h>
#include <WiFiClient.h>
#include <ESP8266WebServer.h>
#include <ESP8266mDNS.h>
#include "ESPCommand.h"
#include <FS.h>
#include <WebSocketsServer.h>
#include <LITTLEFS.h>
#include <ArduinoOTA.h>

// Baud rate, timeouts and the file transfer wire format are the Teensy link contract.
// The same header is compiled into the Teensy tree, so there is nothing to keep in
// step by hand -- see the -I in platformio.ini.
#include "XCopyProtocol.h"

ESP8266WebServer server(80);
WebSocketsServer webSocket(81);
/*
   One name, used for DHCP, for mDNS and for over the air updates, so the device
   is called the same thing by the router, by a browser looking for xcopy.local
   and by an upload aimed at it.
*/
#define DEVICE_HOSTNAME "xcopy"

const int led = 2;
const int busyPin = 4;
const int cancelPin = 13;
const String _marker = "espCommand";

ESPCommandLine command;

volatile int busyState = 0;
volatile bool busyChanged = false;

/*
   Over the air updates.

   The ESP is otherwise only reachable for flashing through the Teensy serial
   passthrough - plug in, put the device in ESP Programming Mode, point the upload
   port at the Teensy. That path stays exactly as it was and is the recovery route
   when an update goes wrong, so nothing here replaces it.

   Both halves can come over the air: the sketch, and the LittleFS image the whole
   web interface is served from. PlatformIO picks between them by appending the
   filesystem flag to espota for the uploadfs target, so the two are one
   mechanism with two targets rather than two mechanisms.

   Deliberately begun from loop() rather than setup(). Wi-Fi credentials are
   applied by the "connect" console command and the SDK reconnects to a saved
   network on its own, so at the end of setup() there is usually no network yet
   for mDNS to announce on.
*/
bool otaStarted = false;

// IRAM_ATTR only places this function in IRAM. String, lwIP and arduinoWebSockets all
// live in flash, and calling into flash from an interrupt while the SPI flash cache is
// disabled faults the chip. Sample the pin here, broadcast from loop().
void IRAM_ATTR busyISR()
{
  busyState = digitalRead(busyPin);
  busyChanged = true;
}

void sendBusyStatus()
{
  // broadcastTXT takes String by non-const reference, so this needs to be an lvalue.
  String payload = "pinStatus," + String(busyState);
  webSocket.broadcastTXT(payload);
}

String getContentType(String filename)
{ 
  filename.toLowerCase();

  if (filename.endsWith(".htm"))
    return "text/html";
  else if (filename.endsWith(".html"))
    return "text/html";
  else if (filename.endsWith(".css"))
    return "text/css";
  else if (filename.endsWith(".js"))
    return "application/javascript";
  else if (filename.endsWith(".png"))
    return "image/png";
  else if (filename.endsWith(".gif"))
    return "image/gif";
  else if (filename.endsWith(".jpg"))
    return "image/jpeg";
  else if (filename.endsWith(".ico"))
    return "image/x-icon";
  if (filename.endsWith(".text"))
    return "text/plain";
  else if (filename.endsWith(".xml"))
    return "text/xml";
  else if (filename.endsWith(".pdf"))
    return "application/x-pdf";
  else if (filename.endsWith(".zip"))
    return "application/x-zip";
  else if (filename.endsWith(".gz"))
    return "application/x-gzip";
  // else if (filename.endsWith(".adf") == true)
  //   return "application/x-binary";
    
  return "text/plain";
}

void handleNotFound()
{
  String message = "File Not Found\n\n";
  message += "URI: ";
  message += server.uri();
  message += "\nMethod: ";
  message += (server.method() == HTTP_GET) ? "GET" : "POST";
  message += "\nArguments: ";
  message += server.args();
  message += "\n";

  for (uint8_t i = 0; i < server.args(); i++)
  {
    message += " " + server.argName(i) + ": " + server.arg(i) + "\n";
  }

  server.send(404, "text/plain", message);
}

bool handleFileRead(String path)
{
  if (path.endsWith("/")) {
    path += "index.html";
  }

  String contentType = getContentType(path);

  if (LittleFS.exists(path))
  {
    File file = LittleFS.open(path, "r");
    server.streamFile(file, contentType);
    file.close();
    return true;
  }

  if (path.startsWith("/sdcard/")) {
    // static: 2048 bytes is half the cont stack this handler runs on.
    static const int bufferSize = 2048;
    static char buffer[bufferSize];
    size_t totalsize = 0;
    unsigned long lastDataTime = millis();
    size_t filesize = 0;

    // strip /sdcard prefix for local SD Card path
    if (path.startsWith("/sdcard")) {
      path = path.substring(7);
    }

    path = server.urlDecode(path);

    // request file
    Serial.print("\r\n");
    Serial.printf(XCOPY_COMMAND_MARKER XFER_CMD_SENDFILE ",%s\r\n", path.c_str());

    // get file size
    String ssize = "";
    ssize = Serial.readStringUntil('\n');
    ssize.replace("\n", "");
    if (ssize.startsWith(XFER_REPLY_ERROR)) {
      return false;
    }
    sscanf(ssize.c_str(), "%zu", &filesize);

    // Without a size the loop below exits on its first pass (0 >= 0) and the reply is
    // a 200 with an empty, never-terminated chunked body. Fail the request instead.
    if (filesize == 0) {
      return false;
    }

    webSocket.broadcastTXT("download,start");

    // start http send
    server.setContentLength(filesize);
    server.send(200, contentType.c_str(), "");

    // get file
    while (true) {
      while (Serial.available()) {
          lastDataTime = millis();
          size_t readSize = Serial.readBytes(buffer, bufferSize);
          totalsize += readSize;
          // send http data
          server.sendContent(buffer, readSize);
      }

      // exit all bytes of file received
      if (totalsize >= filesize) { break; }

      // give up once the Teensy has gone quiet for XFER_IDLE_TIMEOUT
      if (millis() - lastDataTime > XFER_IDLE_TIMEOUT) {
          // finish http send
          server.sendContent("");
          webSocket.broadcastTXT("download,end");
          return false;
      }
    }

    server.sendContent("");
    webSocket.broadcastTXT("download,end");

    return true;
  }

  return false;
}

static bool   uploadFailed = false;
static String uploadError = "";
static size_t uploadSize = 0;
static size_t uploadSent = 0;
static String uploadCrc = "";

// Blocks until the Teensy confirms the chunk is buffered, or we give up. yield() keeps the
// WiFi stack and the soft WDT fed; stalling here is exactly the backpressure we want, since
// it propagates up the TCP window to the browser instead of overrunning the UART.
static bool waitAck() {
  unsigned long t = millis();
  while (millis() - t < XFER_TIMEOUT) {
    if (Serial.available() && Serial.read() == XFER_ACK) return true;
    yield();
  }
  return false;
}

// Reads the expected size from a header rather than server.arg(): headers are parsed before
// the body and cannot be clobbered by multipart form parsing, which is core-version
// dependent. Falls back to the query string.
static size_t requestedFileSize() {
  size_t n = 0;
  String v = server.header("X-File-Size");
  if (v.length() == 0) v = server.arg("filesize");
  sscanf(v.c_str(), "%zu", &n);
  return n;
}

// NOTE: this handler must never call server.send(). Responding from here emits a second
// HTTP response on the same connection and closes the socket before the multipart trailer
// has been consumed, which the browser reports as a network error even though every byte
// arrived. handleUploadDone() sends the single response.
void handleFileUpload() {
  HTTPUpload& upload = server.upload();

  if (upload.status == UPLOAD_FILE_START) {
    digitalWrite(led, 0);
    uploadFailed = false;
    uploadError = "";
    uploadSent = 0;
    uploadCrc = "";
    uploadSize = requestedFileSize();

    String path = upload.filename;
    if (!path.startsWith("/")) path = "/" + path;

    bool overwrite = (server.header("X-Overwrite") == "1");

    // The transfer is length-delimited, so a missing size would make the Teensy write a
    // zero-byte file and report success. Fail loudly instead.
    if (uploadSize == 0) {
      uploadFailed = true;
      uploadError = "nosize";
      webSocket.broadcastTXT("cancelUpload,nosize");
      digitalWrite(led, 1);
      return;
    }

    while (Serial.available()) Serial.read();   // drop stale bytes before the handshake

    Serial.print("\r\n");
    Serial.printf(XCOPY_COMMAND_MARKER XFER_CMD_GETFILE ",%s,%u,%d\r\n", path.c_str(), (unsigned)uploadSize, overwrite ? 1 : 0);

    Serial.setTimeout(XFER_HANDSHAKE_TIMEOUT);  // SD init + bmpDraw headroom
    String response = Serial.readStringUntil('\n');
    response.trim();

    if (response != XFER_REPLY_OK) {
      uploadFailed = true;
      uploadError = response.startsWith(XFER_REPLY_ERROR ",") ? response.substring(6)
                  : (response.length() ? response : "timeout");
      webSocket.broadcastTXT(String("cancelUpload," + uploadError).c_str());
      digitalWrite(led, 1);
    }
  }
  else if (upload.status == UPLOAD_FILE_WRITE) {
    if (uploadFailed) return;                   // swallow the rest of the body quietly

    size_t off = 0;
    while (off < upload.currentSize) {
      size_t n = upload.currentSize - off;
      if (n > XFER_CHUNK) n = XFER_CHUNK;

      Serial.write(upload.buf + off, n);
      Serial.flush();

      if (!waitAck()) {
        uploadFailed = true;
        uploadError = "timeout";
        webSocket.broadcastTXT("cancelUpload,timeout");
        digitalWrite(led, 1);
        return;
      }
      off += n;
      uploadSent += n;
    }
  }
  else if (upload.status == UPLOAD_FILE_END) {
    if (!uploadFailed) {
      Serial.setTimeout(XFER_TIMEOUT);
      String receipt = Serial.readStringUntil('\n');   // "done,<bytes>,<crc32>"
      receipt.trim();

      if (receipt.startsWith(XFER_REPLY_DONE ",")) {
        int last = receipt.lastIndexOf(',');
        size_t got = 0;
        sscanf(receipt.substring(5, last).c_str(), "%zu", &got);
        uploadCrc = receipt.substring(last + 1);

        if (uploadSize > 0 && got != uploadSize) {
          uploadFailed = true;
          uploadError = "short";
        }
      } else {
        uploadFailed = true;
        uploadError = receipt.startsWith(XFER_REPLY_ERROR ",") ? receipt.substring(6) : "noreceipt";
      }
    }
    // UPLOAD_FILE_START raised this to XFER_HANDSHAKE_TIMEOUT and the receipt read
    // above to XFER_TIMEOUT; without this the download path would inherit that
    // timeout on its size read.
    Serial.setTimeout(SERIAL_DEFAULT_TIMEOUT);
    digitalWrite(led, 1);
  }
  else if (upload.status == UPLOAD_FILE_ABORTED) {
    // Just stop sending -- the Teensy closes the file on its own read timeout.
    uploadFailed = true;
    uploadError = "aborted";
    Serial.setTimeout(SERIAL_DEFAULT_TIMEOUT);
    digitalWrite(led, 1);
  }
}

// The single response for the whole POST.
void handleUploadDone() {
  if (uploadFailed) {
    webSocket.broadcastTXT(String("cancelUpload," + uploadError).c_str());
    server.send(500, "application/json",
                String("{\"ok\":false,\"error\":\"") + uploadError + "\"}");
  } else {
    server.send(200, "application/json",
                String("{\"ok\":true,\"size\":") + String(uploadSent) +
                ",\"crc32\":\"" + uploadCrc + "\"}");
  }
}

void webSocketEvent(uint8_t num, WStype_t type, uint8_t *payload, size_t lenght)
{ // When a WebSocket message is received
  switch (type)
  {
    // if the websocket is disconnected
    case WStype_DISCONNECTED: {
      Serial.print("\r\n");
      Serial.printf("xcopyCommand,disconnect,%u\r\n", num);    
      break;
    }
    // if a new websocket connection is established
    case WStype_CONNECTED: {
      IPAddress ip = webSocket.remoteIP(num);
      Serial.print("\r\n");
      Serial.printf("xcopyCommand,connected,%u,%d.%d.%d.%d,%s\r\n", num, ip[0], ip[1], ip[2], ip[3], payload);
      // Greet the client with the busy state instead of waiting for it to ask.
      // Targeted rather than sendBusyStatus(), which broadcasts -- the browsers
      // already connected have it.
      busyState = digitalRead(busyPin);
      String status = "pinStatus," + String(busyState);
      webSocket.sendTXT(num, status);
      // And with the signal strength, which changes rarely enough that a browser
      // arriving between broadcasts would otherwise show nothing for five
      // seconds - or forever, on a link steady enough never to move a bar.
      command.sendWifiStatus(num);
      break;
    }
    // if new text data is received 
    case WStype_TEXT: {
      String cmd = (char *)payload;
      // else if: the else below binds to this if, so "ping" was answered *and*
      // forwarded to the Teensy as "xcopyCommand,ping".
      if (cmd == "ping") { webSocket.sendTXT(num, "pong"); }
      else if (cmd.startsWith(_marker)) {
        // These were "if (cmd = ... == \"busyPin\")": an assignment, not a comparison.
        // The bool result was assigned to cmd and the if tested the resulting String,
        // which is always truthy, so every espCommand message fired both branches --
        // including a pulse on the cancel pin.
        String subcmd = cmd.substring(_marker.length() + 1);
        if (subcmd == "busyPin") {
          busyState = digitalRead(busyPin);
          sendBusyStatus();
        }
        if (subcmd == "cancelPin") {
          digitalWrite(cancelPin, LOW);
          delay(50);
          digitalWrite(cancelPin, HIGH);
        }
      }
      else { Serial.printf("\r\nxcopyCommand,%s\r\n", cmd.c_str()); }
      break;
    }
    default:
      break;
  }
}

/*
   Wires up the over the air handlers. Called from setup(); the listener itself is
   not opened until loop() sees a network - see otaStarted.
*/
void setupOTA()
{
  // Same name MDNS.begin() announces, so the device answers to one hostname
  // whichever way it is reached: the web interface and OTA are both xcopy.
  ArduinoOTA.setHostname(DEVICE_HOSTNAME);

  ArduinoOTA.onStart([]() {
    if (ArduinoOTA.getCommand() == U_FS)
    {
      /*
         The filesystem is written in place, straight into its partition, so it
         has to be unmounted first. Nothing in the core does this for you - the
         reference example marks this exact spot - and leaving it mounted means
         overwriting a live filesystem from underneath the handles into it.
      */
      Serial.println("OTA: filesystem update, unmounting LittleFS");
      LittleFS.end();
    }
    else
    {
      Serial.println("OTA: firmware update");
    }
  });

  ArduinoOTA.onProgress([](unsigned int progress, unsigned int total) {
    // Every tenth, not every packet. Serial is the Teensy link, and the console
    // it feeds is the same one a filesystem image would flood with 2MB of dots.
    static unsigned int lastTenth = 11;
    if (total == 0)
      return;
    unsigned int tenth = (progress / (total / 10 + 1));
    if (tenth == lastTenth)
      return;
    lastTenth = tenth;
    Serial.printf("OTA: %u%%\r\n", (progress / (total / 100 + 1)));
  });

  ArduinoOTA.onEnd([]() {
    Serial.println("OTA: complete, rebooting");
  });

  ArduinoOTA.onError([](ota_error_t error) {
    // Named rather than numbered: the number on its own says nothing at the point
    // somebody is looking at a failed update.
    const char *reason = "unknown";
    switch (error)
    {
    case OTA_AUTH_ERROR:    reason = "auth failed"; break;
    case OTA_BEGIN_ERROR:   reason = "begin failed, image too large for the space"; break;
    case OTA_CONNECT_ERROR: reason = "connect failed"; break;
    case OTA_RECEIVE_ERROR: reason = "receive failed"; break;
    case OTA_END_ERROR:     reason = "end failed"; break;
    }
    Serial.printf("OTA: error %u, %s\r\n", error, reason);

    // A failed filesystem update left it unmounted, and the web interface is
    // served out of it. Put it back rather than waiting for a reboot nobody
    // knows to perform.
    if (ArduinoOTA.getCommand() == U_FS)
      LittleFS.begin();
  });
}

void setup(void)
{
  /*
     First, before anything that takes time.

     This is the name handed to the DHCP server, which is where a DNS server that
     learns its records from DHCP gets them - so it is what makes the device
     resolve as itself rather than as an ESP_XXXXXX derived from its MAC, and
     what an over the air upload is aimed at.

     The SDK starts re-associating with a saved network at boot, on its own,
     before setup() runs. Association and the DHCP request that follows it take a
     second or two, so setting the name here beats them - but only just, which is
     why nothing slower is allowed above it. If the name ever does turn up stale,
     a power cycle settles it.
  */
  WiFi.hostname(DEVICE_HOSTNAME);

  /*
     Come back on our own after a reset.

     The Teensy pushes the network credentials over on its own boot, and for a
     long time that was the only thing that ever connected this radio - so
     resetting the ESP alone, which is exactly what flashing it does, left it off
     the network until the whole device was power cycled.

     The reason it could not reconnect by itself is that ESP8266 core 3.x
     defaults WiFi.persistent() to false, so the credentials the Teensy sends
     reach RAM and never flash. On the 2.x cores this project was written against
     the default was true, which is why the arrangement used to appear to work.
     The connect handler now stores them deliberately rather than by default, and
     this asks the radio to use what was stored.

     begin() with no arguments connects with the saved configuration, so the
     Teensy is the place the network is *configured* and no longer the thing that
     has to be running for the ESP to be *on* it.
  */
  WiFi.mode(WIFI_STA);
  WiFi.setAutoReconnect(true);
  WiFi.begin();

  pinMode(led, OUTPUT);
  digitalWrite(led, 1);
  pinMode(busyPin, INPUT);
  pinMode(cancelPin, OUTPUT);
  digitalWrite(cancelPin, HIGH);
  attachInterrupt(busyPin, busyISR, CHANGE);

  // Must precede begin(). The core default is 256 bytes; the SD *download* path blasts
  // 2048-byte bursts from the Teensy while server.sendContent() can block on TCP, so at
  // 1 Mbaud 256 bytes is only ~2.5ms of headroom. 2048 gives ~20ms.
  Serial.setRxBufferSize(2048);
  Serial.begin(ESPBaudRate);

  if (MDNS.begin(DEVICE_HOSTNAME))
    Serial.println("MDNS responder started");
  else
    Serial.println("MDNS responder failed to start");

  LittleFS.begin();
  Serial.println("LittleFS started");

  webSocket.begin();
  // A Wi-Fi drop tears the TCP connection down without a FIN, so without a
  // heartbeat the client slot stays allocated forever. There are only
  // WEBSOCKETS_SERVER_CLIENT_MAX (5) of them -- five silent drops and the server
  // stops accepting browsers at all, which from the browser side looks like a
  // reconnect that never succeeds. Ping every 5s, 3s to answer, disconnect after
  // two consecutive misses. Browsers answer protocol pings themselves, so this
  // needs nothing from the client.
  webSocket.enableHeartbeat(5000, 3000, 2);
  Serial.println("WebSockets server started");
  webSocket.onEvent(webSocketEvent);

  const char *uploadHeaders[] = { "X-File-Size", "X-Overwrite" };
  // (size_t) cast is required: with an int literal the variadic collectHeaders() overload
  // wins overload resolution and fails to compile on newer cores.
  server.collectHeaders(uploadHeaders, (size_t)2);

  server.on("/upload", HTTP_GET, handleNotFound);
  server.on("/upload", HTTP_POST, handleUploadDone, handleFileUpload);
  server.onNotFound([]() {
    digitalWrite(led, 0);
    if (!handleFileRead(server.uri()))
      handleNotFound();
    digitalWrite(led, 1);
  });
  server.begin();
  Serial.println("HTTP server started");

  setupOTA();

  command.begin(&webSocket);
}

void loop(void)
{
  if (busyChanged) {
    busyChanged = false;
    sendBusyStatus();
  }

  // Opened the first time there is a network to announce on, not in setup():
  // the SDK reconnects to a saved network asynchronously and the "connect"
  // command can bring one up long afterwards.
  if (!otaStarted && WiFi.status() == WL_CONNECTED)
  {
    // false: MDNS.begin() has already run in setup(), and letting ArduinoOTA
    // call it again restarts the responder the web interface is found by.
    ArduinoOTA.begin(false);
    otaStarted = true;
    Serial.println("OTA ready");
  }

  if (otaStarted)
    ArduinoOTA.handle();

  webSocket.loop();
  server.handleClient();
  MDNS.update();
  command.Update();
  command.wifiUpdate();
}

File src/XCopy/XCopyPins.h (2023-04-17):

#ifndef XCOPYPINS_H
#define XCOPYPINS_H

#define PIN_SCLK  13  // SCLK can also use pin 14
#define PIN_MOSI  11  // MOSI can also use pin 7

#define PIN_DC    20   //  but certain pairs must NOT be used: 2+10, 6+9, 20+23, 21+22
#define PIN_RST   21   // RST can use any pinboot 
#define PIN_TFTCS 10 // CS & DC can use pins 2, 6, 9, 10, 15, 20, 21, 22, 23

#define PIN_FLASHCS         23
#define PIN_SDCS            22
#define PIN_BUSYPIN         24
#define PIN_ESPRESETPIN     25
#define PIN_ESPPROGPIN      26
#define PIN_TEENSYRESETPIN  28


#if PCBVERSION == 1
    #define PIN_NAVIGATION_UP_PIN    29
    #define PIN_NAVIGATION_DOWN_PIN  30
    #define PIN_NAVIGATION_RIGHT_PIN 31
    #define PIN_NAVIGATION_LEFT_PIN  32
    #define PIN_NAVIGATION_PUSH_PIN  33

    #define PIN_CARDWP               27
    #define PIN_CARDDETECT           2
#else
    #define PIN_NAVIGATION_UP_PIN    31
    #define PIN_NAVIGATION_DOWN_PIN  32
    #define PIN_NAVIGATION_RIGHT_PIN 29
    #define PIN_NAVIGATION_LEFT_PIN  30
    #define PIN_NAVIGATION_PUSH_PIN  33

    #define PIN_CARDWP               2
    #define PIN_CARDDETECT           27
#endif


#endif // XCOPYPINS_H

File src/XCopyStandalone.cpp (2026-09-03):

#include "XCopy/XCopy.h"
#include "XCopy/XCopyPins.h"
#include "FivePosNavigation/FivePosNavigation.h"

#ifndef __MK20DX256__
#error Not Teensy 3.2 MCU, make sure you get a version 3.2, because the 3.1 ist not 5V tolerant
#endif

// #if F_CPU != 96000000L
// #error Please compile Teensy set to 96MHz optimized
// #endif

// remember to compile with smallest code or you will run out of memory

TFT_ST7735 tft = TFT_ST7735(PIN_TFTCS, PIN_DC, PIN_RST);
FivePosNavigation navigation = FivePosNavigation(PIN_NAVIGATION_UP_PIN, PIN_NAVIGATION_DOWN_PIN, PIN_NAVIGATION_LEFT_PIN, PIN_NAVIGATION_RIGHT_PIN, PIN_NAVIGATION_PUSH_PIN);
XCopy xcopy = XCopy(&tft);
XCopyLog Log = XCopyLog();

void navigationCallBack(uint8_t change_mask, FivePosNavigationState state, uint32_t duration, bool repeat) {
  if ((change_mask & FIVEPOSNAVIGATION_DOWN) && state.down)
  { 
    xcopy.navigateDown(repeat);
    // Serial.println("Down");
  }
  if ((change_mask & FIVEPOSNAVIGATION_UP) && state.up)
  { 
    // Serial.println("Up");
    xcopy.navigateUp(repeat);
  }
  if ((change_mask & FIVEPOSNAVIGATION_PUSH) && state.push)
  { 
    // Serial.println("Push");
    xcopy.navigateSelect();
  }
  if ((change_mask & FIVEPOSNAVIGATION_LEFT) && state.left)
  { 
    xcopy.navigateLeft();
    // Serial.println("Left");
  }
  if ((change_mask & FIVEPOSNAVIGATION_RIGHT) && state.right)
  { 
    xcopy.navigateRight();
    // Serial.println("Right");
  }
}

// Each ISR keeps its own debounce timestamp. These were previously sharing a single
// non-volatile "current" global, so either handler could overwrite the timestamp the
// other was about to compare against.
volatile unsigned long lastCancel = 0;
void ISR_CANCEL()
{
  // shitty debounce
  unsigned long current = millis();
  if (current - lastCancel > 150)
  {
    lastCancel = current;
    xcopy.cancelOperation();
  }
}

volatile unsigned long lastCardDetect = 0;
void ISR_CARD_DETECT()
{
  unsigned long current = millis();
  if (current - lastCardDetect > 100)
  {
    lastCardDetect = current;
    // No delay() here: this runs in interrupt context. cardChange() only timestamps
    // the event; XCopy::update() waits out the switch bounce before reading the pin.
    xcopy.cardChange();
  }
}

void setup() {
  // Init Reset Pin
  // -------------------------------------------------------------------------------------------
  pinMode(PIN_TEENSYRESETPIN, INPUT_DISABLE);

  Serial.begin(115200);

  navigation.begin(10, INPUT_PULLUP, navigationCallBack);
  /*
     Auto repeat on up and down. Long enough before it starts that a deliberate
     single step is never doubled, fast enough once it does that a hundred file SD
     card is a couple of seconds of holding rather than a hundred clicks. The click
     sample is 7ms, so the rate is set by how fast the screen can follow and not by
     the audio.
  */
  navigation.setRepeat(450, 90);
  xcopy.begin();
  #if PCBVERSION == 1
  attachInterrupt(PIN_NAVIGATION_LEFT_PIN, ISR_CANCEL, FALLING);
  #else
  attachInterrupt(PIN_NAVIGATION_LEFT_PIN, ISR_CANCEL, FALLING);
  attachInterrupt(PIN_NAVIGATION_UP_PIN, ISR_CANCEL, FALLING);
  #endif

  pinMode(PIN_CARDDETECT, INPUT_PULLUP);
  attachInterrupt(PIN_CARDDETECT, ISR_CARD_DETECT, CHANGE);
}

void loop() {
  navigation.update();
  xcopy.update();
}

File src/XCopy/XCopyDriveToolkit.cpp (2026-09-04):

#include "XCopyDriveToolkit.h"
#include "XCopyLog.h"

/*
   Screen layout, 160 x 128 landscape.

   Two rows of indicators rather than one: the six outputs sit above the five
   inputs, because "what am I driving" and "what is the drive saying" are the two
   halves of every question asked here, and a single strip of eleven would put
   them in one undifferentiated line. Same 25 pixel pitch the calibration screen
   uses, so a box is a box across both screens.

   Rows are tabulated rather than open coded into every draw call because the TFT
   is repainted in place: a cell is cleared and rewritten on its own, and a y that
   disagreed between the clear and the write would leave debris.
*/
static const uint8_t ROW_OUT_BOX = 0;
static const uint8_t ROW_OUT_TEXT = 10;
static const uint8_t ROW_IN_BOX = 24;
static const uint8_t ROW_IN_TEXT = 34;
static const uint8_t ROW_TITLE = 50;
static const uint8_t ROW_POS = 64;
static const uint8_t ROW_SPEED = 76;
static const uint8_t ROW_STATUS = 92;
static const uint8_t ROW_HELP1 = 108;
static const uint8_t ROW_HELP2 = 118;

static const uint8_t BOX_W = 20;
static const uint8_t BOX_H = 8;
static const uint8_t BOX_X[6] = {0, 25, 50, 75, 100, 125};

//! No ST7735_GREY in the library, and a line at rest has to be visibly different
//! from one that is asserted without being alarming. Mid grey in RGB565.
static const uint16_t DT_GREY = 0x4208;

// Console colours, paired one to one with the TFT colours below so the panel and
// the screen describe the same drive in the same language. Same set XCopyTrackMap
// and the calibration panel use, for the same reason.
#define DT_RESET  "\033[0m"
#define DT_DIM    "\033[0;90m"
#define DT_WHITE  "\033[1;37m"
#define DT_GREEN  "\033[0;32m"
#define DT_YELLOW "\033[0;33m"
#define DT_RED    "\033[1;31m"
#define DT_CYAN   "\033[0;36m"

/*
   Four characters at most, so one table serves the console and the TFT both. The
   TFT draws these under a 20 pixel box on a 25 pixel pitch, and a fifth character
   would overrun into its neighbour.
*/
static const char *const SIG_LABEL[XCopyDriveToolkit::sigCount] = {
    "SEL", "MOT", "DIR", "SIDE", "DENS", "STEP", "IDX", "RDAT", "T0", "WP", "CHG"};

//! Connector pin, shown so the table can be read against a drive's own manual.
static const uint8_t SIG_PIN[XCopyDriveToolkit::sigCount] = {
    12, 16, 18, 32, 2, 20, 8, 30, 26, 28, 34};

const char *XCopyDriveToolkit::label(uint8_t sig) { return SIG_LABEL[sig]; }
uint8_t XCopyDriveToolkit::idcPin(uint8_t sig) { return SIG_PIN[sig]; }

//! printf() on this core has no float support linked in, so "%.1f" prints nothing
//! at all. Every speed on every surface goes through here instead.
static void formatRpm(float rpm, char *out, size_t length)
{
    if (rpm <= 0.0f)
    {
        snprintf(out, length, "-- RPM");
        return;
    }
    const int tenths = (int)((rpm * 10.0f) + 0.5f);
    snprintf(out, length, "%d.%d RPM", tenths / 10, tenths % 10);
}

// SESSION

void XCopyDriveToolkit::begin(XCopyGraphics *graphics, XCopyESP8266 *esp, XCopyFloppy *floppy)
{
    _graphics = graphics;
    _esp = esp;
    _floppy = floppy;

    /*
       Opens with every output released.

       A diagnostic that started by asserting things would destroy the first
       measurement it is asked for: the question is what this drive does when a
       line is driven, and that needs a known quiet starting point to be a
       question at all.
    */
    _sel = false;
    _mot = false;
    _inward = false;
    _upper = true;
    _high = true;
    _sticky = false;
    _cylinder = -1;
    _stepPulses = 0;
    _rpm = 0.0f;
    _idxEdges = 0;
    _rdataActive = false;
    _panelActive = false;

    memset(_moved, 0, sizeof(_moved));
    memset(_previous, 0, sizeof(_previous));
    memset(_raw, 0, sizeof(_raw));
    for (uint8_t i = 0; i < sigCount; i++)
        _level[i] = Level::rest;

    _floppy->setSelectLine(false);
    _floppy->setMotorLine(false);
    _floppy->setDirFast(0);
    _floppy->setSideFast(0);
    _floppy->setDensityLine(true);

    /*
       The idle timeout would stop the motor five seconds into a session where the
       whole point may be watching a spindle that has been asked to run. The
       toolkit owns the motor line for the duration and puts this back in end().
    */
    _floppy->setMotorIdleOff(false);
    /*
       beginRPM() owns the index interrupt and endRPM() gives it back, so the index
       indicator, the edge count and the speed readout all cost no interrupt of our
       own - and there is nothing left for an exit path to forget to detach. The
       feature this replaces attached three interrupts in begin() and detached none
       of them.
    */
    _floppy->clearIndexEdges();
    _floppy->beginRPM();

    _nextSampleMs = millis();
    _active = true;
    sample();
}

void XCopyDriveToolkit::end()
{
    if (!_active)
        return;

    releaseOutputs();
    _floppy->endRPM();
    _floppy->setMotorIdleOff(true);
    _active = false;
}

void XCopyDriveToolkit::update()
{
    if (!_active)
        return;

    if ((int32_t)(millis() - _nextSampleMs) < 0)
        return;
    _nextSampleMs = millis() + kSampleMs;

    sample();
    drawSignals();
    drawReadouts();
    paintAll();
    sendState();
}

// SAMPLING
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

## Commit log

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2019-03-10 Implemented disk to disk cancel and error states
    [XCopy.cpp]
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2019-03-21 Added ESP commands and fixed response truncation
    [XCopy.cpp]
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2019-04-03 Added ESP reset and program pins to Teensy
    [XCopy.cpp]
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2022-04-07 clearwifi command added & skipped wifi connection if no ssid or password present.
    [XCopy.cpp]
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2022-04-10 Fixed http sendFile error handling
    [XCopy.cpp]
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2022-04-14 Moved error handling for SD card failures
    [XCopy.cpp]
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2026-08-30 Add RPM command and update Teensy platform version and enhance XCopy functionality
    - Updated Teensy platform version to 4.18.0 in platformio.ini.
    - Added 'rpm' command to XCopyCommand for measuring drive speed using index pulses.
    - Introduced methods in XCopyFloppy for RPM measurement: beginRPM(), readRPM(), and endRPM().
    - Modified readIndexISR to maintain a rolling buffer of index timestamps for accurate RPM calculations.
    - Refactored diskRPM() to utilize the new RPM measurement methods.
    - Included necessary Arduino.h header in multiple ADF library files for consistency and to resolve potential issues.
2026-08-30 Fix SD card upload reliability and raise ESP link to 1 Mbaud
    Web interface uploads were silently truncating, and completed uploads often
    reported an error in the browser.
    Transfer protocol (ESP8266 <-> Teensy):
    - Replace the open-loop 125ms pacing delay with a per-chunk ACK. The ESP never
    has more than one un-ACKed chunk outstanding, so peak Serial1 ring occupancy
    is bounded by XFER_CHUNK no matter how long an SD write stalls. Previously a
    cluster allocation or block erase longer than the fixed 125ms guess overran
    the 64-byte UART buffer and lost data silently.
    - ACK on buffered rather than on written, so the ESP transmits chunk N+1 while
    the Teensy writes chunk N.
    - Add a CRC32 a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
    [XCopy.cpp]
2026-08-30 Fix six critical defects found in code review
    XCopy::begin() handed _esp to Log.setESP() and _disk.begin() before the object
    was constructed, so XCopyDisk::_esp and XCopyLog::_esp stayed null for the whole
    run -- 92 _esp-> calls in XCopyDisk.cpp and every Log << went through a null
    pointer. It only worked because none of those member functions touch `this`.
    Construct the ESP object right after the pinModes it depends on; reset and
    handshake stay where they were. Guard XCopyLog's uses and default _esp to
    nullptr so a future member access faults loudly rather than silently.
    XCopy::_cancelOperation was not volatile although ISR_CANCEL sets it and
    processState()'s passthrough loop polls it with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
    [XCopy.cpp]
2026-08-30 Fix high severity defects found in code review
    readTrack() returns int and signals failure with -1, but three call sites stored
    the result in a uint8_t. The value truncates to 255, so "errors != -1" was always
    true and the read-failed branch was unreachable. XCopy::sendBlock() consequently
    shipped garbage sector data, checksums and histogram to the web UI after a failed
    read, and the "read" and "bootf" console commands reported failures as successes.
    XCopy::onWebCommand's copyEmptyBlocks handler wrote into a 220 byte stack array
    with no bound on the index, so a websocket message with more than 220 comma
    separated fields overran the stack. The array was also uninitialised while the
    loops bel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
    [XCopy.cpp]
2026-08-30 Fix medium severity defects found in code review
    XCopy::sendFile() tested the read result only after using it, so a FatFile::read()
    error (-1) became Serial1.write(buffer, (size_t)-1). Test before the write. Its
    2KB buffer also moves from the stack to BSS, matching getFile().
    XCopyESP8266::begin() called sendCommand("ping\r\n", 200). The second parameter is
    `bool strip`, not a timeout, so it requested stripping and kept the default 250ms.
    getFile() raised Serial1's timeout to XFER_TIMEOUT and left it there for every
    later read; the ESP likewise left Serial at 8000 then 5000 after an upload, so the
    download path inherited a 5s timeout on its size read. Both restore the default.
    The pinned T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
    [XCopy.cpp]
2026-08-30 Fix low severity and latent defects found in code review
    Two bugs in code nothing currently calls, wrong the moment it is wired up:
    XCopyDisk::getADFVolumeName() tested "if (_sdcard->begin())", reporting an error
    when the card initialised and carrying on when it did not, and leaked _sdcard on
    both early returns. Its 512 byte buffer was also uninitialised, so an unrecognised
    ADFFileSource ran the root block checks over stack garbage; zeroed, those checks
    fail cleanly and yield "NDOS".
    XCopyConfig::createConfig() built its object with as<JsonObject>(). On an empty
    document ArduinoJson 6 returns a null object, so every assignment was discarded
    and _config serialised to the string "null". Swit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
2026-08-31 Single owned SdFat instance for the whole program
    SdFat is not a handle to a card, it is the FatVolume, and FatFile::open(path,
    oflag) resolves against FatFile::m_cwd -- a static that SdFat::begin() repoints at
    whichever instance called it last. Every bare SdFile / FatFile / File in this
    codebase therefore belongs to that instance, whether or not the code that opened
    it knows which one. There were four instances:
    XCopySDCard::_sd one per new XCopySDCard(), 14 sites
    XCopyDebug::SD a member of the debug menu object
    bare FatFile opens no instance at all, just the static cwd
    adf_nativ.cpp an SdFat on the stack, per call
    The last one was actively b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
    [XCopy.cpp]
2026-08-31 Give back the 2KB sendFile static that broke the ls command
    2794b1d made XCopy::sendFile's 2048 byte transfer buffer static, on the reasoning
    that a large buffer does not belong on the stack. That was wrong for this part.
    The buffer is live only for the duration of a web download; as a static it costs
    2KB for the entire runtime, and RAM headroom rather than stack depth is what is
    scarce here. Static RAM went 25756 -> 27804 in that commit, exactly the 2048.
    The console "ls" command is the most allocation hungry path in the firmware.
    XCopySDCard::next() puts a 255 byte name buffer on the stack per entry, and
    printDirectory() calls getfile() -- which returns XCopyFile, three Strings, by
    value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
    [XCopy.cpp]
2026-08-31 Cut the heap churn in the directory listing paths
    The ls lockup was a heap and stack collision, and 2KB of static was enough to
    trigger it, so the listing path was running with almost no margin. This reduces
    what it allocates rather than what it reserves.
    XCopySDCard::getfile() returned XCopyFile by value: three String deep copies per
    call. Both directory loops called it six times per entry, so eighteen allocate and
    free pairs per file went on nothing. It returns a const reference now, and each
    loop binds it once. The reference is valid until the next next(), which is all any
    caller needs, and every one of the twelve call sites only reads members.
    Both loops also built their output line wi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
2026-08-31 Extract the transfer protocol into XCopyTransfer and a shared protocol.h
    The Teensy <-> ESP link was defined twice: XCopy.h and esp8266.ino each carried
    their own copy of the baud rates, timeouts and XFER_* values, kept in step by
    "must match" comments, and the message sequence itself existed only as whatever
    you could reconstruct by reading both firmwares side by side.
    shared/XCopyProtocol.h is now the one definition of the link, compiled into both
    trees via -I. It also names two values that were bare numbers on the ESP side
    (XFER_HANDSHAKE_TIMEOUT, XFER_IDLE_TIMEOUT), gives the command, reply and error
    tokens names both ends use, and documents the three message sequences.
    XCopy::sendFile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
    [XCopy.cpp, XCopyProtocol.h]
2026-08-31 Split XCopyState into what was asked for and what is being done
    One enum held both: "copy a disk to ADF", which the machine then spends thirty
    seconds in, and "set the volume", which is over before the function returns.
    Menu items carried it, _xcopyState held it, the ESP was sent it, and nothing
    stopped a value meant for one being used as the other.
    XCopyAction is now what a menu item or a web command asks for; XCopyState is
    what processState() is dispatching on. stateForAction() is the whole of the
    mapping between them, and the actions that finish where they stand -- every
    setting, both resets, the SD listing -- have no state at all any more.
    XCopyAction is scoped, so an action cannot be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
    [XCopy.cpp]
2026-08-31 Port the floppy driver to a class
    FloppyDrive was ~1700 lines of free functions over 40-odd globals with
    external linkage - cmd, param, mode, errors, track, motor, sectors and
    hist among them, all visible to the whole firmware. XCopyFloppy replaces
    it: 34 public methods, ~30 private helpers, with the decoded track
    buffer, head position and error/retry bookkeeping as members. XCopy owns
    the single instance and passes it to XCopyDisk, XCopyDriveTest and
    XCopyCommandLine, matching how the other collaborators are already wired.
    The state ftm0_isr and diskWrite() touch stays at file scope, and keeps
    external linkage. Those handlers fire every few microseconds and most of
    what they share is not v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
    [XCopy.cpp]
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2026-08-31 Keep the SD card cursor on the stack
    XCopySDCard was heap allocated in five functions and deleted on every
    exit path - 25 delete calls, one of which faulted intermittently at the
    end of a disk write, taking the board down with it after the whole disk
    had been written successfully.
    It is a small object holding two Strings and two SdFile cursors, it never
    outlives the call, and nothing stores it, so there is no reason for it to
    be on the heap. As a local it takes an allocate/free out of the few KB
    the heap has left between the track buffer and the stack, and makes it
    impossible to leak it on an early return - which three of these functions
    had done before.
    This removes the statement that was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
2026-08-31 Rebuild the WebSocket connection layer around real socket state
    Losing the device put up a blocking modal that then could not be dismissed
    when it came back: ping() was gated on connectionState, and its own timeout
    set that flag false while the socket was still open. With no ping there was
    no pong, and setWebsocketStatus("open") -- the only thing that hid the modal
    -- was reachable only from onopen, which could not fire because nothing had
    closed. The server kept broadcasting, so the UI updated behind a dialog that
    was stuck by construction.
    Anything that now decides the link is dead closes the socket and lets onclose
    drive the state, so a disconnected state can no longer outlive the condit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
2026-09-01 live: bound the index waits, state media unprompted, and fix the decode clock (v716.26)
    The firmware half of the host work recorded in the app repo's
    docs/floppy-xcopy.md (sections 8f-8g); this is the build that has been
    flashed and measured throughout, and the one the 7-of-7 emulator boots of
    core 1.60.0 ran against.
    - XCopyFloppy::indexTimer()/waitForIndex(): every spin on the index line is
    bounded at 500 ms (a revolution is ~200 ms). An empty drive produces no
    pulse, and the unbounded original hung the board after the live banner,
    before the command loop that answers HELLO - only a reset recovered it.
    The no-index sentinel is deliberately large so an empty drive reads as DD,
    no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
    [XCopy.cpp]
2026-09-01 live: force short USB packets so delivery is milliseconds, not bursts (v717.26)
    The host's serial driver completes a read only when its buffer fills or a
    short packet terminates the transfer, and a 63 KB/s stream fills every
    64-byte CDC packet exactly - so the stream reached the application in
    4 KB bursts 59 ms apart, and every command ACK sat in the same buffer
    behind the data. The device was never behind; the delivery was.
    XCL_CFG_TX_FLUSH_US (default 1000 us, 0 = the old behaviour) forces the
    pending partial packet out each interval with usb_serial_flush_output(),
    which never blocks; command responses flush immediately on top. Measured
    with xcopyjitter on the bench, paced ~61 KB/s: deliv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
2026-09-03 ui: put the track grid back to ten cylinders a row (v720.26)
    The grid went to 12 x 7 when SCP support pushed the cylinder count from 80
    to 84, because 12 x 7 is exactly 84 and the last row came out full rather
    than ragged. Tidy arithmetic, wrong layout: twelve columns need hex headings,
    so the columns read 0-B and the row labels became bare indices 0-6. Nothing
    about that says "Amiga disk" to anyone looking at it.
    Ten to a row, so a row is a group of ten cylinders and the labels read 0, 10,
    20 ... 80 - the layout XCopy itself used and every imaging tool since, and the
    one a fault pattern can be read off without counting. The short last row is
    the point rather than a defect: cylinders 80 to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
2026-09-03 drive: continuous head calibration test in place of Test Drive (v722.26)
    Test Drive was a passive signal monitor with half its indicators dead: the
    index interrupt was commented out, write protect and the sixth box were
    painted white unconditionally, and Home and Step Track were labels with no
    implementation behind them. It attached three interrupts and detached none,
    and processState() then deleted the object with all three still armed. It ran
    a blocking inner loop that starved the console and ESP pumps, which is the
    structural reason it could never be driven from anywhere but the TFT.
    Replaced with a continuous head calibration test after Amiga Test Kit's: read
    one cylinder of a known goo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
    [XCopy.cpp, XCopyHeadCalibration.cpp, XCopyHeadCalibration.h]
2026-09-03 headcal: fixed console panel, accumulated tally and audio feedback (v723.26)
    The console half was a scrolling log of near identical lines, which is the
    hardest possible way to read a change out of a drive somebody is adjusting.
    It is now the same ASCII table the help screen and the disk map are drawn
    with, at XCopyTrackMap's exact geometry, updated in place by cursor addressing
    so the frame stays put and only the fields move.
    Two halves to the display now, because they answer different questions. The
    sector row is one revolution: which sectors are being missed right now, moving
    the instant the drive is touched. The grid below is every cylinder the session
    has visited over every pass it has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
    [XCopy.cpp, XCopyHeadCalibration.cpp, XCopyHeadCalibration.h]
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2026-09-03 esp: update the firmware and the web assets over the air
    The ESP could only be reached for flashing through the Teensy serial
    passthrough: plug the device in, put it in ESP Programming Mode, point the
    upload port at the Teensy, upload, reset. That is a lot of ceremony for the web
    assets in particular, which change far more often than the ESP firmware and are
    now a 2MB filesystem image.
    Both halves come over Wi-Fi now. `upload` sends the sketch, `uploadfs` sends the
    LittleFS image; PlatformIO appends espota's filesystem flag for the uploadfs
    target itself, so the two are one mechanism with two targets.
    The space works out differently for each, and in our favour. The sketch is
    staged into fr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
    [esp8266.cpp]
2026-09-03 esp: call the device xcopy, and aim OTA at it by name
    The over the air upload pointed at esp8266.local, which was the mDNS name the
    firmware happened to announce rather than the name this device is known by. It
    is xcopy.lab on the local DNS server, so that is what upload_port is now.
    The firmware had a matching problem underneath. It announced esp8266 over mDNS
    and never set a DHCP hostname at all, so what it told the DHCP server was the
    SDK default derived from its MAC. A DNS server that learns records from DHCP
    would therefore have registered it as ESP_XXXXXX, and xcopy.lab resolving would
    have been down to a reservation compensating for the device not knowing its own
    name. One DEVICE_HOS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
    [esp8266.cpp]
2026-09-03 esp: repair uploadfsota, and add an uploadall task
    Uploading the web assets with the uploadfsota target failed at the invitation
    with "ERROR[4]: Not Enough Space", which reads like a device out of room and is
    not. The platform decides whether espota offers a sketch or a filesystem image
    by matching the target name exactly:
    if "uploadfs" in COMMAND_LINE_TARGETS: env.Append(UPLOADERFLAGS=["-s"])
    COMMAND_LINE_TARGETS holds whole names, so for uploadfsota that reads
    "uploadfs" in ["uploadfsota"], which is False. Without the flag the 2MB image was
    offered as a sketch and measured against the 1MB sketch region rather than
    against its own 2MB partition, which it fits exactly. Both targets are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
2026-09-03 esp: let the radio remember its own network
    Resetting the ESP left it off the network until the whole device was power
    cycled. Flashing it is a reset, so every firmware update - through the Teensy or
    over the air - ended with the ESP unreachable, and OTA in particular could not
    be used twice in a row.
    The credentials live on the Teensy and are pushed over on its boot, which is
    fine as a place to configure them and was also, until now, the only thing that
    ever connected the radio. What made that fatal rather than merely odd is that
    ESP8266 core 3.x defaults WiFi.persistent() to false: the credentials the
    Teensy sent reached RAM and never flash, so the ESP had nothing to reconnect
    with and no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
    [esp8266.cpp]
2026-09-03 headcal: shared grid, live tally, pause and a speed readout (v724.26)
    The browser's session tally was its own table with its own cell size, its own
    header row and its own colour names, sitting under a tab whose neighbours all
    draw the disk the same way. It is now the Disk Copy grid: buildCylinderGrid()
    in diskcopy.js builds both, parameterised by the left hand block - the source
    and destination icons for a copy, nothing for a calibration - and the cell ids.
    Same 40px cells, same row labels reading 0, 10, 20 ... 80, same short last row
    for the cylinders SCP reaches and AmigaDOS cannot. The four states come out of
    the disk copy key rather than three colours invented for this one screen: bare
    i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
    [XCopy.cpp, XCopyHeadCalibration.cpp, XCopyHeadCalibration.h]
2026-09-03 gfx: put back the header read that finds the flash thumbnails (v725.26)
    Highlighting anything under Built In ADF Files printed "565 format not
    recognized" and drew nothing. The file is fine; rawDraw() was reading it four
    bytes out of step.
    37ec909 tidied away the unused locals in rawDraw(), and headerSize went with
    them - the whole statement, not just the assignment. read16() and read32() walk
    a shared file offset, so a field that is not read is not skipped either: it is
    handed to whatever is read next. The DIB header size (40) became the width, the
    width (160) became the height, and the low half of the height became the plane
    count. 128 is not 1, so the parse bailed before it ever looked a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
2026-09-03 tft: repaint the two rows that changed, and repeat a held stick (v726.26)
    Every click of the joystick redrew the whole screen. The menu reprinted every
    entry in the level over an identical copy of itself and re-measured the version
    string to put back on top of it; the file listing cleared the panel and
    reprinted up to twelve filenames. Moving a cursor changes two entries' colour
    and nothing else, and both now draw exactly that.
    drawItem() is split out of each list's draw loop and is what both the full draw
    and the single row repaint call, because the two have to lay down the same
    pixels - a repainted row that sits a character to the side of the one it
    replaced is worse than not repainting i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
    [FivePosNavigation.cpp, XCopy.cpp, XCopyStandalone.cpp]
2026-09-03 device: reboot from the browser and the console, and a square banner (v727.26)
    The TFT settings menu could restart the device and the other two interfaces
    could not, so both now ask for the same one: XCopy::reboot(), which the menu
    action delegates to as well. In the browser it is under Tools, below a divider
    after Format Disk, and it confirms first - it sits one item from Format Disk and
    it abandons whatever the drive is in the middle of. On the console it is
    "reboot".
    The implementation did not work on an unmodified board. It pulsed pin 28 and
    then printed "Looks like pin 28 has not been jumpered to the RST pad on your
    Teensy 3.2", which is its own failure notice: that jumper is an option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
    [XCopy.cpp]
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2026-09-04 drive: a toolkit for bringing up an unknown drive (v734.26)
    A drive failure currently presents as one undifferentiated read error. A drive
    that steps but never spins, a drive that spins but whose index sensor is dead,
    and a drive that is never selected in the first place all look identical from
    the outside, and each needs a different fix. Nothing in the firmware told them
    apart, so a mechanism from an unknown source could only be diagnosed by guessing
    at jumpers and re-running a copy.
    The immediate fault this exists for is a drive that steps correctly and produces
    no index. Stepping works with the spindle stopped, so a drive that seeks
    convincingly can be completely stationary - invisible u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
    [XCopy.cpp, XCopyDriveToolkit.cpp, XCopyDriveToolkit.h]
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2026-09-04 fixed: two decimals without the double runtime, 9.4KB (v736.26)
    String(someFloat) was costing ten kilobytes. It calls dtostrf(), which calls
    fcvtf(), which calls _dtoa_r() - newlib's arbitrary precision decimal conversion,
    and that arrives with the whole soft double library behind it: __adddf3,
    __subdf3, __muldf3, __divdf3, the Bignum helpers _Balloc, __multadd, __pow5mult,
    __lshift, __mdiff, quorem and the rest. Four percent of the part to put "0.80"
    next to the word Volume.
    Eleven call sites wanted it, in five files, and every one of them was printing a
    two decimal display quantity: the audio volume, a flux histogram bucket in
    microseconds, a drive speed, a transfer rate, a stopwatch. XCo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
    [XCopy.cpp]
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2026-09-04 diskinfo: describe every track, from the drive or from an image
    An Amiga track analyser, in the shape of HxC's Track Analyzer: what is actually
    on a disk track by track, rather than whether it can be copied. A protected track
    with the wrong cylinder in its headers, a track with no sectors at all, a disk
    with 84 cylinders instead of 80 - all of those are the output, not an error.
    That is why the per track work is surveyCapture() and censusTrack() and not
    readTrack().
    Both sources funnel into one emitTrack(), so the browser cannot tell them apart.
    surveyScp() replays a file's flux through feedFluxSample(), which is the capture
    handler's own body, so an image and the disk it came from are deco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
    [XCopy.cpp]
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
